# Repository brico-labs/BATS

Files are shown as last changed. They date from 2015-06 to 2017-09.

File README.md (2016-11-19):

NOTA IMPORTANTE  
Lee a sección [META](#meta) para clonar este proxecto.

Qué imos facer? Qué se describe en este documento?
==================================================

Imos deseñar un shield para Arduino usando [KiCad](http://www.kicad-pcb.org/)

Daremos unha visión xeral da funcionalidade da suite KiCad pero non vamos a redactar un tutorial detallado nin de deseño de circuitos nin do mesmo KiCad. Daremos as pistas xustiñas para empezar a traballar con KiCad, se queredes un tutorial detallado, en youtube tedes un super recomendable, elaborado por [TutoElectro](https://www.youtube.com/playlist?list=PL1Hs_F1k2mdRVYDtdWd7tQKDZTfxop7np)

Tamén comentaremos a nivel xeral os pasos para desenvolver este proxecto.

Qué é KiCad?
============

KiCad é unha suite de deseño electrónico automatizado [1]. KiCad permite o deseño tanto de esquemas de circuitos como das placas de circuito impreso a nivel profesional. A suite está dispoñible para Windows, Linux e Apple OS X. É un programa gratuito e **libre** distribuido baixo licencia **GNU GPL v2**.

Mellor ainda, a suite KiCad é a elexida polo CERN para o desenvolvemento e deseño de electrónica. É de esperar que con este respaldo a suite mellore ainda mais.

Requisitos do shield
====================

Queremos facer un shield que poida servir para iniciarse no mundo da programación con Arduino, especialmente centrado no ensino (tecnoloxía 3º - 4º ESO). Neste eido, traballar sobre breadboard pode ser complexo, moitas veces o material é compartido e isto implica que, cada clase, hai que montar e desmontar o circuito que logo se programará. Isto leva o seu tempo e ocasiona erros de montaxe que son difíciles de detectar, polo que o uso dun shield parece que pode ser unha solución.

Mália isto, empregando un shield xa ensamblada se perde a oportunidade de profundizar os coñecementos de electrónica e circuitos que se adquiren ao facer un mesmo a montaxe, así que un shield na que o alumno/a teña que colocar e soldar el mesmo os compoñentes, segundo avanza na súa aprendizaxe, parécenos a solución de compromiso idónea.

Queremos que o shield sexa escalable, que sirva para traballar cuns poucos compoñentes se non se quere profundizar demasiado, pero que permita tamén chegar a nivéis máis avanzados e con máis compoñentes sen cambiar de shield.

Estes son os compoñentes que se pensan incluír:

-   3-4 x Botóns
-   1 x RGB
-   1 x LDR
-   1 x Pines servo
-   1 x sensor temp (dudoso)
-   2 x potenciómetros
-   1 x LED vermello
-   1 x LED amarelo
-   1 x LED verde
-   1 x Zoador
-   1 x Botón de reset

Instalación de KiCad (en Ubuntu)
================================

Para instalar o KiCad en Ubuntu basta con facer o típico ciclo de instalación:

``` {bash}
sudo apt-get install kicad
```

Se queremos estar á última temos o ppa de Monsieur Reynaud dispoñible:

``` {bash}
sudo apt-add-repository ppa:js-reynaud/ppa-KiCad
sudo apt-get update
sudo apt-get install kicad
```

Nos escollimos esta opción.

Se non usades un linux baseado en Debian, teredes que consultar na rede como facer a instalación para o voso sistema operativo. De todolos xeitos a instalación é moi doada, donde podemos atopar algún problemiña é na instalación das bibliotecas de compoñentes que vos contaremos cos mais detalle mais adiante.

Configuración de directorios para este proxecto
===============================================

Además de desenvolver o proxecto con KiCad queremos ter o proxecto dispoñible en github.

Agora que temos KiCad instalado imos preparar un directorio de traballo ao que chamamos **bats**.

O directorio **bats** será o "repositorio" ou depósito do noso proxecto para git. Contén os seguintes subdirectorios:

doc  
Contén a documentación do proxecto (o que estás a leer agora mesmo) redactada en [Pandoc](http://pandoc.org/)

kicad  
Contén o proxecto KiCad

Unha vez que temos preparado o directorio do proxecto activamos git para iniciar o control de versións.

------------------------------------------------------------------------

Describir a configuración de git??

------------------------------------------------------------------------

Biblioteca de compoñentes incluindo un shield para Arduino
==========================================================

As bibliotecas de KiCad están organizadas en duas partes:

-   Un ficheiro que contén os símbolos dos compoñentes para usarse no editor de esquemas electrónicos **Eescheme**

-   As pegadas dos compoñentes electrónicos, é dicir, a forma que ten que ter a pista da placa de circuito impreso (*PCB*) para poder soldar o compoñente.

O KiCad trae por defecto varios templates que permiten o desenrolo de proxectos baseados en diferentes modelos de Arduino.

Nos optamos por outro camiño, instalamos unha nova biblioteca de compoñentes e fixemos o proxecto usando esta biblioteca.

Unha biblioteca moi completa é a de Freetronics que podemos atopar tamén en github en:

<https://github.com/freetronics/freetronics_KiCad_library.git>

As bibliotecas de KiCad poden estar almacenadas en diferentes directorios do noso ordenador. Poderíamos engadir as bibliotecas que usemos en algún subdirectorio de */usr/share/kicad* ou de */usr/local/share*. Esta podería ser unha boa estratexia nun servidor compartido por varios usuarios. Tamén poderíamos descarregar todas as bibliotecas a un directorio común do noso *home*. Pero como estamos facendo un control de versións do noso proxecto con git a propia páxina da biblioteca suxírenos o xeito mais adoitado de facer a instalación: coma un submódulo git do noso proxecto.

A vantaxe de engadir a biblioteca de compoñentes de Freetronics coma un submódulo Git é que o noso proxecto queda "aillado" do proxecto engadido como submódulo. Podemos avanzar no noso proxecto e salvar os cambios feitos con Git, sen afectar aos submódulos, e viceversa.

Por exemplo, unha vez que teñamos o noso directorio de traballo configurado con git, e a libreria de Freetronics engadida como submodulo, poderíamos empezar o desenrolo da nosa placa BATS e ir gardando os nosos avances. Estas operacións non afectarán a librería Freetronics, que de feito ainda que esta descarregada no noso directorio de traballo, non está gardada no git do noso proxecto, soamente está enlazada.

Se no futuro nos interesa actualizarnos a unha versión mais avanzada da librería Freetronics, podemos facer un commit do noso proxecto nunha situación controlada, e despois actualizar o submodulo correspondiente a librería.

Engadir a biblioteca como un submódulo de git
---------------------------------------------

Dende o directorio principal de noso proxecto descarregamos a biblioteca de Freetronics coma un submodulo do noso proxecto:

``` {bash}
cd kicad 
git submodule add https://github.com/freetronics/freetronics_kicad_library.git kicad/ftlibrary
```

Despois de engadir a biblioteca como un submódulo se consultamos o estado git do noso proxecto aparecerán dous novos ficheiros:

``` {bash}
$ git status
On branch master
Your branch is up-to-date with 'origin/master'.
Changes to be committed:
  (use "git reset HEAD <file>..." to unstage)

    new file:   .gitmodules
    new file:   kicad/ftlibrary
```

Git engadíu automáticamente os dous novos ficheiros, o directorio que contén a nosa biblioteca eo ficheiro **.gitmodule** que levará o control de todolos submódulos que usemos.

En realidade os ficheiros que compoñen a biblioteca non pertencen ao noso depósito de software, git só leva conta da versión da biblioteca de Freetronics que estamos a usar.

Se queres saber mais de esta potente funcionalidade de git podes leer: <http://www.git-scm.com/book/en/v2/Git-Tools-Submodules>

Configurar *Eescheme* para usar a nova biblioteca
-------------------------------------------------

No menú Preferences -&gt; Component Library sinalamos na fiestra inferior o directorio do noso proxecto. Na fiestra superior engadimos o ficheiro da biblioteca.

No github da biblioteca nos aconsellan poñer a biblioteca de primeira na nosa lista por que definen todo tipo de compoñentes. Nos de momento seguimos o consello de Freetronics, e a puxemos de primeira.

Configurar acceso aos datos de pegadas (*footprints*) en pcbnew
---------------------------------------------------------------

Configuramos un ficheiro para o noso proxecto declarando os *footprint* extra que imos a utilizar.

``` {cpp}
(fp_lib_table
  (lib
   (name FT)
   (type KiCad)
   (uri ${KIPRJMOD}/ftlibrary/freetronics_footprints.pretty)
   (options "")
   (descr "Freetronics Kicad Library")
   )
)
```

Engadimos o novo ficheiro ao noso repositorio

``` {bash}
git add fp-lib-table
```

Abrimos *Pcbnew* e no menú *Preferences-&gt;Footprint Libraries Manager* comprobamos que na pestaña *Project Specific Libraries* figura o noso ficheiro.

Tutorial
========

Checklist: Pasos a seguir para rematar o proxecto
-------------------------------------------------

-   Abrir o proxecto (e mellor tér un directorio dedicado ao proxecto creado en adianto)
-   Crear o esquema do circuito (usando Eescheme)
-   Chequeo de erros (opción *Perform Electrical Rules Check*)
-   Asignar as pegadas (*footprints*) aos compoñentes (opción *run CvPcb* dende o *Eescheme*). As pegadas quedan asignadas a cada compoñente no esquema.
-   Xerar o ficheiro NET (opción *Generate netlist*)
-   Abrir o PcbNew e cargar o ficheiro NET xenerado dende o Eescheme
-   Distribuir os compoñentes do noso proxecto intentado simplificar a topoloxía das pistas o que poidamos.

A pantalla xeral
----------------

------------------------------------------------------------------------

Pantalla xeral de KiCad opcións, citar a lista de hotkeys

------------------------------------------------------------------------

Abrindo un proxecto
-------------------

### Checklist

-   Usar un directorio adicado ao proxecto
-   Engadir a información do proxecto ao esquema.

Abrimos un novo proxecto: File::New Project (Ctrl+N) **bats**

### 

Crear e Editar o esquema do circuito
------------------------------------

O primeiro que imos facer é o esquema do circuito. Para isto temos que usar a ferramenta *Eeschema* que podemos atopar en tres lugares diferentes [2] na barra de iconos de ferramentas, no menú de KiCad no título da fiestra, ou có atallo **Ctrl+E**.

Abrimos eescheme e creamos un novo ficheiro de esquema.

ERC: comprobación dos erros no circuito
---------------------------------------

### Tips

-   Falar dos flags
    -   Power flags
    -   Not used flag
-   Falar dos ficheiros de pegadas
-   Falar da asignación automática de pegadas

As bibliotecas en KiCAD
=======================

Esta é sen dúbida a parte de KiCAD mais criticada. Hai varias razóns para isto:

-   As bibliotecas de KiCAD manteñen separados os símbolos dos compoñentes para usar no esquema do circuito das pegadas (*footprints*) dos mesmos que son os que se usan no deseño da placa.
-   Os símbolos dos compoñentes están almacenados en ficheiros con extensión *.lib* de ahí que con frecuencia se lles chame *library* (traducido librerias) na xerga de KiCAD
-   Por contra as pegadas dos compoñentes almacénanse en ficheiros con extensión *.mod* ou as mais modernas *.kicad\_mod* de ahí que a miudo se lles chame *modules* (traducido módulos) na xerga de KiCAD
-   Os menús e diálogos para engadir ficheiros *.lib* e os ficheiros *.mod* son completamente diferentes
-   KiCAD soporta multiples localizacións para as bibliotecas, mesmo localizacións en github.

Dende o noso punto de vista o mais sinxelo e ter un só directorio donde almacenemos as bibliotecas de terceiros que queremos usar con KiCAD. Nos usamos **~/resources/kicad** de feito temos:

~/resources/kicad/my\_kicad\_lib  
Para os compoñentes de diseño propio

~/resources/kicad/my\_kicad.pretty  
para os footprints de diseño propio

~/resources/kicad/kicad\_3rd  
para librerias de terceiros

Un exemplo: Engadir novas bibliotecas Arduino
---------------------------------------------

Imos ver como engadir unha nova biblioteca de compoñentes de xeito global (quedará dispoñible para todos os proxectos) ou só para un proxecto concreto.

As bibliotecas que imos usar pódense atopar en esta [páxina](http://meta-blog.eklablog.com/kicad-librairie-arduino-pretty-p930786).

Na páxina hai dous ficheiros dispoñibles para descarga. O que contén as plantillas (*templates*) non o queremos, xa está incluido no github de KiCAD.

Descarregamos o outro e descomprimimos no directorio donde imos ter as bibliotecas de KiCAD, no noso caso: **~/resources/kicad/kicad\_3rd**

Enlaces útiles
==============

-   [Conceptos de circuitos impresos](http://www.pcb.electrosoft.cl/04-articulos-circuitos-impresos-desarrollo-sistemas/01-conceptos-circuitos-impresos/conceptos-circuitos-impresos-pcb.html)
-   [Instalación das bibliotecas](http://www.arunet.co.uk/tkboyd/ele2pcbka.htm)
-   [Mais bibliotecas para KiCad](http://www.kicadlib.org/)

Dende o seguinte enlace podese descarregar unha biblioteca de compoñentes moi currada, ainda que algo anticuada:

<git://smisioto.eu/KiCad_libs.git>

META
====

Este repositorio usa submódulos de git para a xestión das bibliotecas de compoñentes. Para clonar o repositorio tes que clonar o repositorio e despois actualizar os submódulos executando:

``` {bash}
$ git clone https://github.com/brico-labs/BATS
$ git submodule update --init
```

Este documento está escrito en [Markdown-Pandoc](http://pandoc.org/README.html). Pandoc e un sistema moi sinxelo de documentación que permite xerar multiples formatos de saída.

As fontes do documento están no directorio **doc/src**. Os formatos de saída son este fichero **README.md** en formato Markdown-github e os documentos que podes atopar no directorio **doc/out** incluindo un pdf.

Os documentos xéranse automáticamente a partir do ficheiro fonte sen mais que executar:

``` {bash}
$ cd doc
$ make
```

Outras opcións que soporta o **makefile** serían **reset** para rexerar todos os documentos de saída por defecto, **odt** para xerar un **bats\_gl.odt**.

``` {bash}
$ make reset
$ make odt
```

[1] EDA suite en inglés

[2] Isto de ter varios xeitos de facer unha cousa é habitual en KiCad como iremos vendo

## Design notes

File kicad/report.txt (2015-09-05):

Info: Reading netlist file "/home/salvari/work/repos/bats/kicad/bats_n.net".

Info: Using references to match components and footprints.

Info: Checking netlist component footprint "LED1:/55898313:FT:LED-3MM".

Adding new component "LED1:/55898313" footprint "FT:LED-3MM".

Changing component "LED1:/55898313" pin "A" net name from "" to "Net-(LED1-PadA)".

Changing component "LED1:/55898313" pin "K" net name from "" to "Net-(LED1-PadK)".

Info: Checking netlist component footprint "LED2:/55898212:FT:LED-3MM".

Adding new component "LED2:/55898212" footprint "FT:LED-3MM".

Changing component "LED2:/55898212" pin "A" net name from "" to "Net-(LED2-PadA)".

Changing component "LED2:/55898212" pin "K" net name from "" to "Net-(LED2-PadK)".

Info: Checking netlist component footprint "LED3:/55898085:FT:LED-3MM".

Adding new component "LED3:/55898085" footprint "FT:LED-3MM".

Changing component "LED3:/55898085" pin "A" net name from "" to "Net-(LED3-PadA)".

Changing component "LED3:/55898085" pin "K" net name from "" to "Net-(LED3-PadK)".

Info: Checking netlist component footprint "LED4:/558B07DB:FT:LED-RGB-8MM-COM-K-MINIMAL".

Adding new component "LED4:/558B07DB" footprint "FT:LED-RGB-8MM-COM-K-MINIMAL".

Changing component "LED4:/558B07DB" pin "AB" net name from "" to "Net-(LED4-PadAB)".

Changing component "LED4:/558B07DB" pin "AR" net name from "" to "Net-(LED4-PadAR)".

Changing component "LED4:/558B07DB" pin "K" net name from "" to "GND".

Changing component "LED4:/558B07DB" pin "AG" net name from "" to "Net-(LED4-PadAG)".

Info: Checking netlist component footprint "P1:/558B2883:FT:1X03".

Adding new component "P1:/558B2883" footprint "FT:1X03".

Changing component "P1:/558B2883" pin "1" net name from "" to "Net-(P1-Pad1)".

Changing component "P1:/558B2883" pin "2" net name from "" to "Net-(P1-Pad2)".

Changing component "P1:/558B2883" pin "3" net name from "" to "GND".

Info: Checking netlist component footprint "R6:/558983C9:Resistors_ThroughHole:Resistor_Horizontal_RM10mm".

Adding new component "R6:/558983C9" footprint "Resistors_ThroughHole:Resistor_Horizontal_RM10mm".

Changing component "R6:/558983C9" pin "1" net name from "" to "Net-(P1-Pad1)".

Changing component "R6:/558983C9" pin "2" net name from "" to "Net-(R6-Pad2)".

Info: Checking netlist component footprint "R7:/55898454:Resistors_ThroughHole:Resistor_Horizontal_RM10mm".

Adding new component "R7:/55898454" footprint "Resistors_ThroughHole:Resistor_Horizontal_RM10mm".

Changing component "R7:/55898454" pin "1" net name from "" to "Net-(R6-Pad2)".

Changing component "R7:/55898454" pin "2" net name from "" to "GND".

Info: Checking netlist component footprint "R9:/558B13E2:Resistors_ThroughHole:Resistor_Horizontal_RM10mm".

Adding new component "R9:/558B13E2" footprint "Resistors_ThroughHole:Resistor_Horizontal_RM10mm".

Changing component "R9:/558B13E2" pin "1" net name from "" to "Net-(LED4-PadAR)".

Changing component "R9:/558B13E2" pin "2" net name from "" to "Net-(R9-Pad2)".

Info: Checking netlist component footprint "R10:/558B144D:Resistors_ThroughHole:Resistor_Horizontal_RM10mm".

Adding new component "R10:/558B144D" footprint "Resistors_ThroughHole:Resistor_Horizontal_RM10mm".

Changing component "R10:/558B144D" pin "1" net name from "" to "Net-(LED4-PadAG)".

Changing component "R10:/558B144D" pin "2" net name from "" to "Net-(R10-Pad2)".

Info: Checking netlist component footprint "R11:/558B14E5:Resistors_ThroughHole:Resistor_Horizontal_RM10mm".

Adding new component "R11:/558B14E5" footprint "Resistors_ThroughHole:Resistor_Horizontal_RM10mm".

Changing component "R11:/558B14E5" pin "1" net name from "" to "Net-(LED4-PadAB)".

Changing component "R11:/558B14E5" pin "2" net name from "" to "Net-(R11-Pad2)".

Info: Checking netlist component footprint "R12:/558AE59A:Resistors_ThroughHole:Resistor_Horizontal_RM10mm".

Adding new component "R12:/558AE59A" footprint "Resistors_ThroughHole:Resistor_Horizontal_RM10mm".

Changing component "R12:/558AE59A" pin "1" net name from "" to "Net-(R12-Pad1)".

Changing component "R12:/558AE59A" pin "2" net name from "" to "GND".

Info: Checking netlist component footprint "R13:/558AEB17:Resistors_ThroughHole:Resistor_Horizontal_RM10mm".

Adding new component "R13:/558AEB17" footprint "Resistors_ThroughHole:Resistor_Horizontal_RM10mm".

Changing component "R13:/558AEB17" pin "1" net name from "" to "Net-(R13-Pad1)".

Changing component "R13:/558AEB17" pin "2" net name from "" to "GND".

Info: Checking netlist component footprint "R14:/55898319:Resistors_ThroughHole:Resistor_Horizontal_RM10mm".

Adding new component "R14:/55898319" footprint "Resistors_ThroughHole:Resistor_Horizontal_RM10mm".

Changing component "R14:/55898319" pin "1" net name from "" to "Net-(LED1-PadK)".

Changing component "R14:/55898319" pin "2" net name from "" to "GND".

Info: Checking netlist component footprint "R15:/55898218:Resistors_ThroughHole:Resistor_Horizontal_RM10mm".

Adding new component "R15:/55898218" footprint "Resistors_ThroughHole:Resistor_Horizontal_RM10mm".

Changing component "R15:/55898218" pin "1" net name from "" to "Net-(LED2-PadK)".

Changing component "R15:/55898218" pin "2" net name from "" to "GND".

Info: Checking netlist component footprint "R16:/55898121:Resistors_ThroughHole:Resistor_Horizontal_RM10mm".

Adding new component "R16:/55898121" footprint "Resistors_ThroughHole:Resistor_Horizontal_RM10mm".

Changing component "R16:/55898121" pin "1" net name from "" to "Net-(LED3-PadK)".

Changing component "R16:/55898121" pin "2" net name from "" to "GND".

Info: Checking netlist component footprint "R17:/558AEBB6:Resistors_ThroughHole:Resistor_Horizontal_RM10mm".

Adding new component "R17:/558AEBB6" footprint "Resistors_ThroughHole:Resistor_Horizontal_RM10mm".

Changing component "R17:/558AEBB6" pin "1" net name from "" to "Net-(R17-Pad1)".

Changing component "R17:/558AEBB6" pin "2" net name from "" to "GND".

Info: Checking netlist component footprint "R18:/558AEBC3:Resistors_ThroughHole:Resistor_Horizontal_RM10mm".

Adding new component "R18:/558AEBC3" footprint "Resistors_ThroughHole:Resistor_Horizontal_RM10mm".

Changing component "R18:/558AEBC3" pin "1" net name from "" to "Net-(R18-Pad1)".

Changing component "R18:/558AEBC3" pin "2" net name from "" to "GND".

Info: Checking netlist component footprint "SHIELD1:/55897B99:FT:ARDUINO_SHIELD".

Adding new component "SHIELD1:/55897B99" footprint "FT:ARDUINO_SHIELD".

Changing component "SHIELD1:/55897B99" pin "AD5" net name from "" to "Net-(SHIELD1-PadAD5)".

Changing component "SHIELD1:/55897B99" pin "AD4" net name from "" to "Net-(SHIELD1-PadAD4)".

Changing component "SHIELD1:/55897B99" pin "AD3" net name from "" to "Net-(SHIELD1-PadAD3)".

Changing component "SHIELD1:/55897B99" pin "AD0" net name from "" to "Net-(R6-Pad2)".

Changing component "SHIELD1:/55897B99" pin "AD1" net name from "" to "Net-(SHIELD1-PadAD1)".

Changing component "SHIELD1:/55897B99" pin "AD2" net name from "" to "Net-(SHIELD1-PadAD2)".

Changing component "SHIELD1:/55897B99" pin "V_IN" net name from "" to "Net-(SHIELD1-PadV_IN)".

Changing component "SHIELD1:/55897B99" pin "GND2" net name from "" to "GND".

Changing component "SHIELD1:/55897B99" pin "GND1" net name from "" to "GND".

Changing component "SHIELD1:/55897B99" pin "3V3" net name from "" to "Net-(SHIELD1-Pad3V3)".

Changing component "SHIELD1:/55897B99" pin "RST" net name from "" to "Net-(SHIELD1-PadRST)".

Changing component "SHIELD1:/55897B99" pin "0" net name from "" to "Net-(R18-Pad1)".

Changing component "SHIELD1:/55897B99" pin "1" net name from "" to "Net-(R17-Pad1)".

Changing component "SHIELD1:/55897B99" pin "2" net name from "" to "Net-(R13-Pad1)".

Changing component "SHIELD1:/55897B99" pin "3" net name from "" to "Net-(P1-Pad2)".

Changing component "SHIELD1:/55897B99" pin "4" net name from "" to "Net-(R12-Pad1)".

Changing component "SHIELD1:/55897B99" pin "5" net name from "" to "Net-(R11-Pad2)".

Changing component "SHIELD1:/55897B99" pin "6" net name from "" to "Net-(R10-Pad2)".

Changing component "SHIELD1:/55897B99" pin "7" net name from "" to "Net-(SHIELD1-Pad7)".

Changing component "SHIELD1:/55897B99" pin "8" net name from "" to "Net-(SHIELD1-Pad8)".

Changing component "SHIELD1:/55897B99" pin "9" net name from "" to "Net-(R9-Pad2)".

Changing component "SHIELD1:/55897B99" pin "10" net name from "" to "Net-(SHIELD1-Pad10)".

Changing component "SHIELD1:/55897B99" pin "11" net name from "" to "Net-(LED3-PadA)".

Changing component "SHIELD1:/55897B99" pin "12" net name from "" to "Net-(LED2-PadA)".

Changing component "SHIELD1:/55897B99" pin "13" net name from "" to "Net-(LED1-PadA)".

Changing component "SHIELD1:/55897B99" pin "GND3" net name from "" to "GND".

Changing component "SHIELD1:/55897B99" pin "AREF" net name from "" to "Net-(SHIELD1-PadAREF)".

Changing component "SHIELD1:/55897B99" pin "5V" net name from "" to "Net-(P1-Pad1)".

Changing component "SHIELD1:/55897B99" pin "SDA" net name from "" to "Net-(SHIELD1-PadSDA)".

Changing component "SHIELD1:/55897B99" pin "SCL" net name from "" to "Net-(SHIELD1-PadSCL)".

Changing component "SHIELD1:/55897B99" pin "IO_R" net name from "" to "Net-(SHIELD1-PadIO_R)".

Changing component "SHIELD1:/55897B99" pin "NC" net name from "" to "Net-(SHIELD1-PadNC)".

Changing component "SHIELD1:/55897B99" pin "SP1" net name from "" to "Net-(SHIELD1-PadSP1)".

Changing component "SHIELD1:/55897B99" pin "SP2" net name from "" to "Net-(SHIELD1-PadSP2)".

Changing component "SHIELD1:/55897B99" pin "SP3" net name from "" to "Net-(SHIELD1-PadSP3)".

Changing component "SHIELD1:/55897B99" pin "SP4" net name from "" to "Net-(SHIELD1-PadSP4)".

Changing component "SHIELD1:/55897B99" pin "SP5" net name from "" to "Net-(SHIELD1-PadSP5)".

Changing component "SHIELD1:/55897B99" pin "SP6" net name from "" to "Net-(SHIELD1-PadSP6)".

Info: Checking netlist component footprint "SW5:/558B73E7:FT:SW_PUSHBUTTON_PTH".

Adding new component "SW5:/558B73E7" footprint "FT:SW_PUSHBUTTON_PTH".

Changing component "SW5:/558B73E7" pin "1" net name from "" to "GND".

Changing component "SW5:/558B73E7" pin "1" net name from "" to "GND".

Changing component "SW5:/558B73E7" pin "2" net name from "" to "Net-(SHIELD1-PadRST)".

Changing component "SW5:/558B73E7" pin "2" net name from "" to "Net-(SHIELD1-PadRST)".

Info: Checking netlist component footprint "SW6:/5589867E:FT:SW_PUSHBUTTON_PTH".

Adding new component "SW6:/5589867E" footprint "FT:SW_PUSHBUTTON_PTH".

Changing component "SW6:/5589867E" pin "1" net name from "" to "Net-(P1-Pad1)".

Changing component "SW6:/5589867E" pin "1" net name from "" to "Net-(P1-Pad1)".

Changing component "SW6:/5589867E" pin "2" net name from "" to "Net-(R12-Pad1)".

Changing component "SW6:/5589867E" pin "2" net name from "" to "Net-(R12-Pad1)".

Info: Checking netlist component footprint "SW7:/558AEB11:FT:SW_PUSHBUTTON_PTH".

Adding new component "SW7:/558AEB11" footprint "FT:SW_PUSHBUTTON_PTH".

Changing component "SW7:/558AEB11" pin "1" net name from "" to "Net-(P1-Pad1)".

Changing component "SW7:/558AEB11" pin "1" net name from "" to "Net-(P1-Pad1)".

Changing component "SW7:/558AEB11" pin "2" net name from "" to "Net-(R13-Pad1)".

Changing component "SW7:/558AEB11" pin "2" net name from "" to "Net-(R13-Pad1)".

Info: Checking netlist component footprint "SW8:/558AEBB0:FT:SW_PUSHBUTTON_PTH".

Adding new component "SW8:/558AEBB0" footprint "FT:SW_PUSHBUTTON_PTH".

Changing component "SW8:/558AEBB0" pin "1" net name from "" to "Net-(P1-Pad1)".

Changing component "SW8:/558AEBB0" pin "1" net name from "" to "Net-(P1-Pad1)".

Changing component "SW8:/558AEBB0" pin "2" net name from "" to "Net-(R17-Pad1)".

Changing component "SW8:/558AEBB0" pin "2" net name from "" to "Net-(R17-Pad1)".

Info: Checking netlist component footprint "SW9:/558AEBBD:FT:SW_PUSHBUTTON_PTH".

Adding new component "SW9:/558AEBBD" footprint "FT:SW_PUSHBUTTON_PTH".

Changing component "SW9:/558AEBBD" pin "1" net name from "" to "Net-(P1-Pad1)".

Changing component "SW9:/558AEBBD" pin "1" net name from "" to "Net-(P1-Pad1)".

Changing component "SW9:/558AEBBD" pin "2" net name from "" to "Net-(R18-Pad1)".

Changing component "SW9:/558AEBBD" pin "2" net name from "" to "Net-(R18-Pad1)".

Info: Checking netlist component footprint "U1:/5589860F:Buzzers_Beepers:MagneticBuzzer_Kingstate_KCG0601".

Adding new component "U1:/5589860F" footprint "Buzzers_Beepers:MagneticBuzzer_Kingstate_KCG0601".

Changing component "U1:/5589860F" pin "1" net name from "" to "GND".

Changing component "U1:/5589860F" pin "2" net name from "" to "Net-(SHIELD1-Pad10)".

Info: Checking netlist component footprint "VR1:/55EA1F32:FT:POT_RV09_VERT".

Adding new component "VR1:/55EA1F32" footprint "FT:POT_RV09_VERT".

Changing component "VR1:/55EA1F32" pin "W" net name from "" to "Net-(SHIELD1-PadAD1)".

Changing component "VR1:/55EA1F32" pin "1" net name from "" to "Net-(P1-Pad1)".

Changing component "VR1:/55EA1F32" pin "2" net name from "" to "GND".

Info: Checking netlist component footprint "VR2:/55EA2018:FT:POT_RV09_VERT".

Adding new component "VR2:/55EA2018" footprint "FT:POT_RV09_VERT".

Changing component "VR2:/55EA2018" pin "W" net name from "" to "Net-(SHIELD1-PadAD2)".

Changing component "VR2:/55EA2018" pin "1" net name from "" to "Net-(P1-Pad1)".

Changing component "VR2:/55EA2018" pin "2" net name from "" to "GND".

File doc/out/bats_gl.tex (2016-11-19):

\documentclass[12pt,galician,]{article}
\usepackage{lmodern}
\usepackage{amssymb,amsmath}
\usepackage{ifxetex,ifluatex}
\usepackage{fixltx2e} % provides \textsubscript
\ifnum 0\ifxetex 1\fi\ifluatex 1\fi=0 % if pdftex
  \usepackage[T1]{fontenc}
  \usepackage[utf8]{inputenc}
\else % if luatex or xelatex
  \ifxetex
    \usepackage{mathspec}
  \else
    \usepackage{fontspec}
  \fi
  \defaultfontfeatures{Ligatures=TeX,Scale=MatchLowercase}
    \setmainfont[]{Source Sans Pro}
    \setmonofont[Mapping=tex-ansi]{Source Code Pro}
\fi
% use upquote if available, for straight quotes in verbatim environments
\IfFileExists{upquote.sty}{\usepackage{upquote}}{}
% use microtype if available
\IfFileExists{microtype.sty}{%
\usepackage{microtype}
\UseMicrotypeSet[protrusion]{basicmath} % disable protrusion for tt fonts
}{}
\usepackage[a4paper]{geometry}
\usepackage[unicode=true]{hyperref}
\hypersetup{
            pdftitle={BATS: BricoLabs Arduino Training Shield (con kicad)},
            pdfauthor={BricoLabs},
            pdfborder={0 0 0},
            breaklinks=true}
\urlstyle{same}  % don't use monospace font for urls
\ifnum 0\ifxetex 1\fi\ifluatex 1\fi=0 % if pdftex
  \usepackage[shorthands=off,main=galician]{babel}
\else
  \usepackage{polyglossia}
  \setmainlanguage[]{galician}
\fi
\IfFileExists{parskip.sty}{%
\usepackage{parskip}
}{% else
\setlength{\parindent}{0pt}
\setlength{\parskip}{6pt plus 2pt minus 1pt}
}
\setlength{\emergencystretch}{3em}  % prevent overfull lines
\providecommand{\tightlist}{%
  \setlength{\itemsep}{0pt}\setlength{\parskip}{0pt}}
\setcounter{secnumdepth}{5}
% Redefines (sub)paragraphs to behave more like sections
\ifx\paragraph\undefined\else
\let\oldparagraph\paragraph
\renewcommand{\paragraph}[1]{\oldparagraph{#1}\mbox{}}
\fi
\ifx\subparagraph\undefined\else
\let\oldsubparagraph\subparagraph
\renewcommand{\subparagraph}[1]{\oldsubparagraph{#1}\mbox{}}
\fi

\title{BATS: BricoLabs Arduino Training Shield (con kicad)}
\author{BricoLabs}
\date{20 de xunio de 2015}

\begin{document}
\maketitle

\begin{description}
\item[NOTA IMPORTANTE]
Lee a sección \protect\hyperlink{meta}{META} para clonar este proxecto.
\end{description}

\section{Qué imos facer? Qué se describe en este
documento?}\label{quuxe9-imos-facer-quuxe9-se-describe-en-este-documento}

Imos deseñar un shield para Arduino usando
\href{http://www.kicad-pcb.org/}{KiCad}

Daremos unha visión xeral da funcionalidade da suite KiCad pero non
vamos a redactar un tutorial detallado nin de deseño de circuitos nin do
mesmo KiCad. Daremos as pistas xustiñas para empezar a traballar con
KiCad, se queredes un tutorial detallado, en youtube tedes un super
recomendable, elaborado por
\href{https://www.youtube.com/playlist?list=PL1Hs_F1k2mdRVYDtdWd7tQKDZTfxop7np}{TutoElectro}

Tamén comentaremos a nivel xeral os pasos para desenvolver este
proxecto.

\section{Qué é KiCad?}\label{quuxe9-uxe9-kicad}

KiCad é unha suite de deseño electrónico automatizado \footnote{EDA
  suite en inglés}. KiCad permite o deseño tanto de esquemas de
circuitos como das placas de circuito impreso a nivel profesional. A
suite está dispoñible para Windows, Linux e Apple OS X. É un programa
gratuito e \textbf{libre} distribuido baixo licencia \textbf{GNU GPL
v2}.

Mellor ainda, a suite KiCad é a elexida polo CERN para o desenvolvemento
e deseño de electrónica. É de esperar que con este respaldo a suite
mellore ainda mais.

\section{Requisitos do shield}\label{requisitos-do-shield}

Queremos facer un shield que poida servir para iniciarse no mundo da
programación con Arduino, especialmente centrado no ensino (tecnoloxía
3º - 4º ESO). Neste eido, traballar sobre breadboard pode ser complexo,
moitas veces o material é compartido e isto implica que, cada clase, hai
que montar e desmontar o circuito que logo se programará. Isto leva o
seu tempo e ocasiona erros de montaxe que son difíciles de detectar,
polo que o uso dun shield parece que pode ser unha solución.

Mália isto, empregando un shield xa ensamblada se perde a oportunidade
de profundizar os coñecementos de electrónica e circuitos que se
adquiren ao facer un mesmo a montaxe, así que un shield na que o
alumno/a teña que colocar e soldar el mesmo os compoñentes, segundo
avanza na súa aprendizaxe, parécenos a solución de compromiso idónea.

Queremos que o shield sexa escalable, que sirva para traballar cuns
poucos compoñentes se non se quere profundizar demasiado, pero que
permita tamén chegar a nivéis máis avanzados e con máis compoñentes sen
cambiar de shield.

Estes son os compoñentes que se pensan incluír:

\begin{itemize}
\tightlist
\item
  3-4 x Botóns
\item
  1 x RGB
\item
  1 x LDR
\item
  1 x Pines servo
\item
  1 x sensor temp (dudoso)
\item
  2 x potenciómetros
\item
  1 x LED vermello
\item
  1 x LED amarelo
\item
  1 x LED verde
\item
  1 x Zoador
\item
  1 x Botón de reset
\end{itemize}

\section{Instalación de KiCad (en
Ubuntu)}\label{instalaciuxf3n-de-kicad-en-ubuntu}

Para instalar o KiCad en Ubuntu basta con facer o típico ciclo de
instalación:

\begin{verbatim}
sudo apt-get install kicad
\end{verbatim}

Se queremos estar á última temos o ppa de Monsieur Reynaud dispoñible:

\begin{verbatim}
sudo apt-add-repository ppa:js-reynaud/ppa-KiCad
sudo apt-get update
sudo apt-get install kicad
\end{verbatim}

Nos escollimos esta opción.

Se non usades un linux baseado en Debian, teredes que consultar na rede
como facer a instalación para o voso sistema operativo. De todolos
xeitos a instalación é moi doada, donde podemos atopar algún problemiña
é na instalación das bibliotecas de compoñentes que vos contaremos cos
mais detalle mais adiante.

\section{Configuración de directorios para este
proxecto}\label{configuraciuxf3n-de-directorios-para-este-proxecto}

Además de desenvolver o proxecto con KiCad queremos ter o proxecto
dispoñible en github.

Agora que temos KiCad instalado imos preparar un directorio de traballo
ao que chamamos \textbf{bats}.

O directorio \textbf{bats} será o ``repositorio'' ou depósito do noso
proxecto para git. Contén os seguintes subdirectorios:

\begin{description}
\tightlist
\item[doc]
Contén a documentación do proxecto (o que estás a leer agora mesmo)
redactada en \href{http://pandoc.org/}{Pandoc}
\item[kicad]
Contén o proxecto KiCad
\end{description}

Unha vez que temos preparado o directorio do proxecto activamos git para
iniciar o control de versións.

\begin{center}\rule{0.5\linewidth}{\linethickness}\end{center}

Describir a configuración de git??

\begin{center}\rule{0.5\linewidth}{\linethickness}\end{center}

\section{Biblioteca de compoñentes incluindo un shield para
Arduino}\label{biblioteca-de-compouxf1entes-incluindo-un-shield-para-arduino}

As bibliotecas de KiCad están organizadas en duas partes:

\begin{itemize}
\item
  Un ficheiro que contén os símbolos dos compoñentes para usarse no
  editor de esquemas electrónicos \textbf{Eescheme}
\item
  As pegadas dos compoñentes electrónicos, é dicir, a forma que ten que
  ter a pista da placa de circuito impreso (\emph{PCB}) para poder
  soldar o compoñente.
\end{itemize}

O KiCad trae por defecto varios templates que permiten o desenrolo de
proxectos baseados en diferentes modelos de Arduino.

Nos optamos por outro camiño, instalamos unha nova biblioteca de
compoñentes e fixemos o proxecto usando esta biblioteca.

Unha biblioteca moi completa é a de Freetronics que podemos atopar tamén
en github en:

\url{https://github.com/freetronics/freetronics_KiCad_library.git}

As bibliotecas de KiCad poden estar almacenadas en diferentes
directorios do noso ordenador. Poderíamos engadir as bibliotecas que
usemos en algún subdirectorio de \emph{/usr/share/kicad} ou de
\emph{/usr/local/share}. Esta podería ser unha boa estratexia nun
servidor compartido por varios usuarios. Tamén poderíamos descarregar
todas as bibliotecas a un directorio común do noso \emph{home}. Pero
como estamos facendo un control de versións do noso proxecto con git a
propia páxina da biblioteca suxírenos o xeito mais adoitado de facer a
instalación: coma un submódulo git do noso proxecto.

A vantaxe de engadir a biblioteca de compoñentes de Freetronics coma un
submódulo Git é que o noso proxecto queda ``aillado'' do proxecto
engadido como submódulo. Podemos avanzar no noso proxecto e salvar os
cambios feitos con Git, sen afectar aos submódulos, e viceversa.

Por exemplo, unha vez que teñamos o noso directorio de traballo
configurado con git, e a libreria de Freetronics engadida como
submodulo, poderíamos empezar o desenrolo da nosa placa BATS e ir
gardando os nosos avances. Estas operacións non afectarán a librería
Freetronics, que de feito ainda que esta descarregada no noso directorio
de traballo, non está gardada no git do noso proxecto, soamente está
enlazada.

Se no futuro nos interesa actualizarnos a unha versión mais avanzada da
librería Freetronics, podemos facer un commit do noso proxecto nunha
situación controlada, e despois actualizar o submodulo correspondiente a
librería.

\subsection{Engadir a biblioteca como un submódulo de
git}\label{engadir-a-biblioteca-como-un-submuxf3dulo-de-git}

Dende o directorio principal de noso proxecto descarregamos a biblioteca
de Freetronics coma un submodulo do noso proxecto:

\begin{verbatim}
cd kicad 
git submodule add https://github.com/freetronics/freetronics_kicad_library.git kicad/ftlibrary
\end{verbatim}

Despois de engadir a biblioteca como un submódulo se consultamos o
estado git do noso proxecto aparecerán dous novos ficheiros:

\begin{verbatim}
$ git status
On branch master
Your branch is up-to-date with 'origin/master'.
Changes to be committed:
  (use "git reset HEAD <file>..." to unstage)

    new file:   .gitmodules
    new file:   kicad/ftlibrary
\end{verbatim}

Git engadíu automáticamente os dous novos ficheiros, o directorio que
contén a nosa biblioteca eo ficheiro \textbf{.gitmodule} que levará o
control de todolos submódulos que usemos.

En realidade os ficheiros que compoñen a biblioteca non pertencen ao
noso depósito de software, git só leva conta da versión da biblioteca de
Freetronics que estamos a usar.

Se queres saber mais de esta potente funcionalidade de git podes leer:
\url{http://www.git-scm.com/book/en/v2/Git-Tools-Submodules}

\subsection{\texorpdfstring{Configurar \emph{Eescheme} para usar a nova
biblioteca}{Configurar Eescheme para usar a nova biblioteca}}\label{configurar-eescheme-para-usar-a-nova-biblioteca}

No menú Preferences -\textgreater{} Component Library sinalamos na
fiestra inferior o directorio do noso proxecto. Na fiestra superior
engadimos o ficheiro da biblioteca.

No github da biblioteca nos aconsellan poñer a biblioteca de primeira na
nosa lista por que definen todo tipo de compoñentes. Nos de momento
seguimos o consello de Freetronics, e a puxemos de primeira.

\subsection{\texorpdfstring{Configurar acceso aos datos de pegadas
(\emph{footprints}) en
pcbnew}{Configurar acceso aos datos de pegadas (footprints) en pcbnew}}\label{configurar-acceso-aos-datos-de-pegadas-footprints-en-pcbnew}

Configuramos un ficheiro para o noso proxecto declarando os
\emph{footprint} extra que imos a utilizar.

\begin{verbatim}
(fp_lib_table
  (lib
   (name FT)
   (type KiCad)
   (uri ${KIPRJMOD}/ftlibrary/freetronics_footprints.pretty)
   (options "")
   (descr "Freetronics Kicad Library")
   )
)
\end{verbatim}

Engadimos o novo ficheiro ao noso repositorio

\begin{verbatim}
git add fp-lib-table
\end{verbatim}

Abrimos \emph{Pcbnew} e no menú
\emph{Preferences-\textgreater{}Footprint Libraries Manager} comprobamos
que na pestaña \emph{Project Specific Libraries} figura o noso ficheiro.

\section{Tutorial}\label{tutorial}

\subsection{Checklist: Pasos a seguir para rematar o
proxecto}\label{checklist-pasos-a-seguir-para-rematar-o-proxecto}

\begin{itemize}
\tightlist
\item
  Abrir o proxecto (e mellor tér un directorio dedicado ao proxecto
  creado en adianto)
\item
  Crear o esquema do circuito (usando Eescheme)
\item
  Chequeo de erros (opción \emph{Perform Electrical Rules Check})
\item
  Asignar as pegadas (\emph{footprints}) aos compoñentes (opción
  \emph{run CvPcb} dende o \emph{Eescheme}). As pegadas quedan asignadas
  a cada compoñente no esquema.
\item
  Xerar o ficheiro NET (opción \emph{Generate netlist})
\item
  Abrir o PcbNew e cargar o ficheiro NET xenerado dende o Eescheme
\item
  Distribuir os compoñentes do noso proxecto intentado simplificar a
  topoloxía das pistas o que poidamos.
\end{itemize}

\subsection{A pantalla xeral}\label{a-pantalla-xeral}

\begin{center}\rule{0.5\linewidth}{\linethickness}\end{center}

Pantalla xeral de KiCad opcións, citar a lista de hotkeys

\begin{center}\rule{0.5\linewidth}{\linethickness}\end{center}

\subsection{Abrindo un proxecto}\label{abrindo-un-proxecto}

\subsubsection{Checklist}\label{checklist}

\begin{itemize}
\tightlist
\item
  Usar un directorio adicado ao proxecto
\item
  Engadir a información do proxecto ao esquema.
\end{itemize}

Abrimos un novo proxecto: File::New Project (Ctrl+N) \textbf{bats}

\subsubsection{}\label{section}

\subsection{Crear e Editar o esquema do
circuito}\label{crear-e-editar-o-esquema-do-circuito}

O primeiro que imos facer é o esquema do circuito. Para isto temos que
usar a ferramenta \emph{Eeschema} que podemos atopar en tres lugares
diferentes \footnote{Isto de ter varios xeitos de facer unha cousa é
  habitual en KiCad como iremos vendo} na barra de iconos de
ferramentas, no menú de KiCad no título da fiestra, ou có atallo
\textbf{Ctrl+E}.

Abrimos eescheme e creamos un novo ficheiro de esquema.

\subsection{ERC: comprobación dos erros no
circuito}\label{erc-comprobaciuxf3n-dos-erros-no-circuito}

\subsubsection{Tips}\label{tips}

\begin{itemize}
\tightlist
\item
  Falar dos flags

  \begin{itemize}
  \tightlist
  \item
    Power flags
  \item
    Not used flag
  \end{itemize}
\item
  Falar dos ficheiros de pegadas
\item
  Falar da asignación automática de pegadas
\end{itemize}

\section{As bibliotecas en KiCAD}\label{as-bibliotecas-en-kicad}

Esta é sen dúbida a parte de KiCAD mais criticada. Hai varias razóns
para isto:

\begin{itemize}
\tightlist
\item
  As bibliotecas de KiCAD manteñen separados os símbolos dos compoñentes
  para usar no esquema do circuito das pegadas (\emph{footprints}) dos
  mesmos que son os que se usan no deseño da placa.
\item
  Os símbolos dos compoñentes están almacenados en ficheiros con
  extensión \emph{.lib} de ahí que con frecuencia se lles chame
  \emph{library} (traducido librerias) na xerga de KiCAD
\item
  Por contra as pegadas dos compoñentes almacénanse en ficheiros con
  extensión \emph{.mod} ou as mais modernas \emph{.kicad\_mod} de ahí
  que a miudo se lles chame \emph{modules} (traducido módulos) na xerga
  de KiCAD
\item
  Os menús e diálogos para engadir ficheiros \emph{.lib} e os ficheiros
  \emph{.mod} son completamente diferentes
\item
  KiCAD soporta multiples localizacións para as bibliotecas, mesmo
  localizacións en github.
\end{itemize}

Dende o noso punto de vista o mais sinxelo e ter un só directorio donde
almacenemos as bibliotecas de terceiros que queremos usar con KiCAD. Nos
usamos \textbf{\textasciitilde{}/resources/kicad} de feito temos:

\begin{description}
\item[\textasciitilde{}/resources/kicad/my\_kicad\_lib]
Para os compoñentes de diseño propio
\item[\textasciitilde{}/resources/kicad/my\_kicad.pretty]
para os footprints de diseño propio
\item[\textasciitilde{}/resources/kicad/kicad\_3rd]
para librerias de terceiros
\end{description}

\subsection{Un exemplo: Engadir novas bibliotecas
Arduino}\label{un-exemplo-engadir-novas-bibliotecas-arduino}

Imos ver como engadir unha nova biblioteca de compoñentes de xeito
global (quedará dispoñible para todos os proxectos) ou só para un
proxecto concreto.

As bibliotecas que imos usar pódense atopar en esta
\href{http://meta-blog.eklablog.com/kicad-librairie-arduino-pretty-p930786}{páxina}.

Na páxina hai dous ficheiros dispoñibles para descarga. O que contén as
plantillas (\emph{templates}) non o queremos, xa está incluido no github
de KiCAD.

Descarregamos o outro e descomprimimos no directorio donde imos ter as
bibliotecas de KiCAD, no noso caso:
\textbf{\textasciitilde{}/resources/kicad/kicad\_3rd}

\section{Enlaces útiles}\label{enlaces-uxfatiles}

\begin{itemize}
\tightlist
\item
  \href{http://www.pcb.electrosoft.cl/04-articulos-circuitos-impresos-desarrollo-sistemas/01-conceptos-circuitos-impresos/conceptos-circuitos-impresos-pcb.html}{Conceptos
  de circuitos impresos}
\item
  \href{http://www.arunet.co.uk/tkboyd/ele2pcbka.htm}{Instalación das
  bibliotecas}
\item
  \href{http://www.kicadlib.org/}{Mais bibliotecas para KiCad}
\end{itemize}

Dende o seguinte enlace podese descarregar unha biblioteca de
compoñentes moi currada, ainda que algo anticuada:

\url{git://smisioto.eu/KiCad_libs.git}

\hypertarget{meta}{\section{META}\label{meta}}

Este repositorio usa submódulos de git para a xestión das bibliotecas de
compoñentes. Para clonar o repositorio tes que clonar o repositorio e
despois actualizar os submódulos executando:

\begin{verbatim}
$ git clone https://github.com/brico-labs/BATS
$ git submodule update --init
\end{verbatim}

Este documento está escrito en
\href{http://pandoc.org/README.html}{Markdown-Pandoc}. Pandoc e un
sistema moi sinxelo de documentación que permite xerar multiples
formatos de saída.

As fontes do documento están no directorio \textbf{doc/src}. Os formatos
de saída son este fichero \textbf{README.md} en formato Markdown-github
e os documentos que podes atopar no directorio \textbf{doc/out}
incluindo un pdf.

Os documentos xéranse automáticamente a partir do ficheiro fonte sen
mais que executar:

\begin{verbatim}
$ cd doc
$ make
\end{verbatim}

Outras opcións que soporta o \textbf{makefile} serían \textbf{reset}
para rexerar todos os documentos de saída por defecto, \textbf{odt} para
xerar un \textbf{bats\_gl.odt}.

\begin{verbatim}
$ make reset
$ make odt
\end{verbatim}

\end{document}

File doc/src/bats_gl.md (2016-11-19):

% BATS: BricoLabs Arduino Training Shield (con kicad)
% BricoLabs
% 20 de xunio de 2015

NOTA IMPORTANTE

  : Lee a sección [META](#meta) para clonar este proxecto.

# Qué imos facer? Qué se describe en este documento?

Imos deseñar un shield para Arduino usando
[KiCad](http://www.kicad-pcb.org/)

Daremos unha visión xeral da funcionalidade da suite KiCad pero non
vamos a redactar un tutorial detallado nin de deseño de circuitos nin
do mesmo KiCad. Daremos as pistas xustiñas para empezar a traballar
con KiCad, se queredes un tutorial detallado, en youtube tedes un
super recomendable, elaborado por
[TutoElectro](https://www.youtube.com/playlist?list=PL1Hs_F1k2mdRVYDtdWd7tQKDZTfxop7np)

Tamén comentaremos a nivel xeral os pasos para desenvolver este
proxecto.

# Qué é KiCad?

KiCad é unha suite de deseño electrónico automatizado
^[EDA suite en inglés]. KiCad permite o deseño tanto de esquemas de
circuitos como das placas de circuito impreso a nivel profesional. A suite
está dispoñible para Windows, Linux e Apple OS X. É un programa
gratuito e __libre__ distribuido baixo licencia __GNU GPL v2__.

Mellor ainda, a suite KiCad é a elexida polo CERN para o
desenvolvemento e deseño de electrónica. É de esperar que con este
respaldo a suite mellore ainda mais.

# Requisitos do shield

Queremos facer un shield que poida servir para iniciarse no mundo da
programación con Arduino, especialmente centrado no ensino (tecnoloxía
3º - 4º ESO). Neste eido, traballar sobre breadboard pode ser
complexo, moitas veces o material é compartido e isto implica que,
cada clase, hai que montar e desmontar o circuito que logo se
programará. Isto leva o seu tempo e ocasiona erros de montaxe que son
difíciles de detectar, polo que o uso dun shield parece que pode ser
unha solución.

Mália isto, empregando un shield xa ensamblada se perde a oportunidade
de profundizar os coñecementos de electrónica e circuitos que se
adquiren ao facer un mesmo a montaxe, así que un shield na que o
alumno/a teña que colocar e soldar el mesmo os compoñentes, segundo
avanza na súa aprendizaxe, parécenos a solución de compromiso idónea.

Queremos que o shield sexa escalable, que sirva para traballar cuns
poucos compoñentes se non se quere profundizar demasiado, pero que
permita tamén chegar a nivéis máis avanzados e con máis compoñentes
sen cambiar de shield.

Estes son os compoñentes que se pensan incluír:

* 3-4 x Botóns
* 1 x RGB
* 1 x LDR
* 1 x Pines servo
* 1 x sensor temp (dudoso)
* 2 x potenciómetros
* 1 x LED vermello
* 1 x LED amarelo
* 1 x LED verde
* 1 x Zoador
* 1 x Botón de reset

# Instalación de KiCad (en Ubuntu)

Para instalar o KiCad en Ubuntu basta con facer o típico ciclo de
instalación:

~~~~{bash}
sudo apt-get install kicad
~~~~

Se queremos estar á última temos o ppa de Monsieur Reynaud dispoñible:

~~~~{bash}
sudo apt-add-repository ppa:js-reynaud/ppa-KiCad
sudo apt-get update
sudo apt-get install kicad
~~~~

Nos escollimos esta opción.

Se non usades un linux baseado en Debian, teredes que consultar na
rede como facer a instalación para o voso sistema operativo. De
todolos xeitos a instalación é moi doada, donde podemos atopar algún
problemiña é na instalación das bibliotecas de compoñentes que vos
contaremos cos mais detalle mais adiante.

# Configuración de directorios para este proxecto

Además de desenvolver o proxecto con KiCad queremos ter o proxecto
dispoñible en github.

Agora que temos KiCad instalado imos preparar un directorio de
traballo ao que chamamos __bats__.

O directorio __bats__ será o "repositorio" ou depósito do
noso proxecto para git. Contén os seguintes subdirectorios:

doc
  : Contén a documentación do proxecto (o que estás a leer agora
mesmo) redactada en [Pandoc](http://pandoc.org/)

kicad
  : Contén o proxecto KiCad

Unha vez que temos preparado o directorio do proxecto activamos git
para iniciar o control de versións.

----

Describir a configuración de git??

----

# Biblioteca de compoñentes incluindo un shield para Arduino

As bibliotecas de KiCad están organizadas en duas partes:

* Un ficheiro que contén os símbolos dos compoñentes para usarse no
  editor de esquemas electrónicos __Eescheme__

* As pegadas dos compoñentes electrónicos, é dicir, a forma que ten que
  ter a pista da placa de circuito impreso (_PCB_) para poder soldar o
  compoñente.

O KiCad trae por defecto varios templates que permiten o desenrolo de
proxectos baseados en diferentes modelos de Arduino.

Nos optamos por outro camiño, instalamos unha nova biblioteca de
compoñentes e fixemos o proxecto usando esta biblioteca.

Unha biblioteca moi completa é a de Freetronics que podemos atopar
tamén en github en:

<https://github.com/freetronics/freetronics_KiCad_library.git>

As bibliotecas de KiCad poden estar almacenadas en diferentes
directorios do noso ordenador. Poderíamos engadir as bibliotecas que
usemos en algún subdirectorio de _/usr/share/kicad_ ou de
_/usr/local/share_. Esta podería ser unha boa estratexia nun servidor
compartido por varios usuarios. Tamén poderíamos descarregar todas as
bibliotecas a un directorio común do noso _home_. Pero como estamos
facendo un control de versións do noso proxecto con git a propia
páxina da biblioteca suxírenos o xeito mais adoitado de facer a
instalación: coma un submódulo git do noso proxecto.

A vantaxe de engadir a biblioteca de compoñentes de Freetronics coma
un submódulo Git é que o noso proxecto queda "aillado" do proxecto
engadido como submódulo. Podemos avanzar no noso proxecto e salvar os
cambios feitos con Git, sen afectar aos submódulos, e viceversa.

Por exemplo, unha vez que teñamos o noso directorio de traballo configurado
con git, e a libreria de Freetronics engadida como submodulo, poderíamos
empezar o desenrolo da nosa placa BATS e ir gardando os nosos
avances. Estas operacións non afectarán a librería Freetronics, que de
feito ainda que esta descarregada no noso directorio de traballo, non
está gardada no git do noso proxecto, soamente está enlazada.

Se no futuro nos interesa actualizarnos a unha versión mais avanzada
da librería Freetronics, podemos facer un commit do noso proxecto
nunha situación controlada, e despois actualizar o submodulo
correspondiente a librería.

## Engadir a biblioteca como un submódulo de git

Dende o directorio principal de noso proxecto descarregamos a
biblioteca de Freetronics coma un submodulo do noso proxecto:

~~~{bash}
cd kicad 
git submodule add https://github.com/freetronics/freetronics_kicad_library.git kicad/ftlibrary
~~~

Despois de engadir a biblioteca como un submódulo se consultamos o
estado git do noso proxecto aparecerán dous novos ficheiros:

~~~~{bash}
$ git status
On branch master
Your branch is up-to-date with 'origin/master'.
Changes to be committed:
  (use "git reset HEAD <file>..." to unstage)

	new file:   .gitmodules
	new file:   kicad/ftlibrary
~~~~

Git engadíu automáticamente os dous novos ficheiros, o directorio que
contén a nosa biblioteca eo ficheiro __.gitmodule__ que levará o
control de todolos submódulos que usemos.

En realidade os ficheiros que compoñen a biblioteca non pertencen ao
noso depósito de software, git só leva conta da versión da biblioteca
de Freetronics que estamos a usar.

Se queres saber mais de esta potente funcionalidade de git podes leer:
<http://www.git-scm.com/book/en/v2/Git-Tools-Submodules>

## Configurar _Eescheme_ para usar a nova biblioteca

No menú Preferences -> Component Library sinalamos na fiestra inferior o
directorio do noso proxecto. Na fiestra superior engadimos o ficheiro da
biblioteca.

No github da biblioteca nos aconsellan poñer a biblioteca de primeira
na nosa lista por que definen todo tipo de compoñentes. Nos de momento
seguimos o consello de Freetronics, e a puxemos de primeira.

## Configurar acceso aos datos de pegadas (_footprints_) en pcbnew

Configuramos un ficheiro para o noso proxecto declarando os
_footprint_ extra que imos a utilizar.

~~~~{cpp}
(fp_lib_table
  (lib
   (name FT)
   (type KiCad)
   (uri ${KIPRJMOD}/ftlibrary/freetronics_footprints.pretty)
   (options "")
   (descr "Freetronics Kicad Library")
   )
)
~~~~

Engadimos o novo ficheiro ao noso repositorio

~~~~{bash}
git add fp-lib-table
~~~~

Abrimos _Pcbnew_ e no menú _Preferences->Footprint Libraries Manager_
comprobamos que na pestaña _Project Specific Libraries_ figura o noso
ficheiro.

# Tutorial

## Checklist: Pasos a seguir para rematar o proxecto

* Abrir o proxecto (e mellor tér un directorio dedicado ao proxecto
  creado en adianto)
* Crear o esquema do circuito (usando Eescheme)
* Chequeo de erros (opción _Perform Electrical Rules Check_)
* Asignar as pegadas (_footprints_) aos compoñentes (opción _run
  CvPcb_ dende o _Eescheme_). As pegadas quedan asignadas a cada
  compoñente no esquema.
* Xerar o ficheiro NET (opción _Generate netlist_)
* Abrir o PcbNew e cargar o ficheiro NET xenerado dende o Eescheme
* Distribuir os compoñentes do noso proxecto intentado simplificar a
  topoloxía das pistas o que poidamos.

## A pantalla xeral

----

Pantalla xeral de KiCad opcións, citar a lista de hotkeys

----

## Abrindo un proxecto

### Checklist

* Usar un directorio adicado ao proxecto
* Engadir a información do proxecto ao esquema.

Abrimos un novo proxecto: File::New Project (Ctrl+N)
__bats__

###

## Crear e Editar o esquema do circuito

O primeiro que imos facer é o esquema do circuito. Para isto temos que
usar a ferramenta _Eeschema_ que podemos atopar en tres lugares
diferentes
^[Isto de ter varios xeitos de facer unha cousa é habitual en KiCad como iremos vendo]
na barra de iconos de ferramentas, no menú de KiCad no título da
fiestra, ou có atallo __Ctrl+E__.

Abrimos eescheme e creamos un novo ficheiro de esquema.

## ERC: comprobación dos erros no circuito

### Tips

* Falar dos flags
    * Power flags
    * Not used flag
* Falar dos ficheiros de pegadas
* Falar da asignación automática de pegadas

# As bibliotecas en KiCAD

Esta é sen dúbida a parte de KiCAD mais criticada. Hai varias razóns para isto:

* As bibliotecas de KiCAD manteñen separados os símbolos dos
  compoñentes para usar no esquema do circuito das pegadas
  (*footprints*) dos mesmos que son os que se usan no deseño da placa.
* Os símbolos dos compoñentes están almacenados en ficheiros con
  extensión *.lib* de ahí que con frecuencia se lles chame *library*
  (traducido librerias) na xerga de KiCAD
* Por contra as pegadas dos compoñentes almacénanse en ficheiros con
  extensión *.mod* ou as mais modernas *.kicad_mod* de ahí que a miudo
  se lles chame *modules* (traducido módulos) na xerga de KiCAD
* Os menús e diálogos para engadir ficheiros *.lib* e os ficheiros
  *.mod* son completamente diferentes
* KiCAD soporta multiples localizacións para as bibliotecas, mesmo
  localizacións en github.

Dende o noso punto de vista o mais sinxelo e ter un só directorio
donde almacenemos as bibliotecas de terceiros que queremos usar con
KiCAD. Nos usamos **~/resources/kicad** de feito temos:

~/resources/kicad/my_kicad_lib

  ~ Para os compoñentes de diseño propio

~/resources/kicad/my_kicad.pretty

  ~ para os footprints de diseño propio

~/resources/kicad/kicad_3rd

  ~ para librerias de terceiros

## Un exemplo: Engadir novas bibliotecas Arduino

Imos ver como engadir unha nova biblioteca de compoñentes de xeito
global (quedará dispoñible para todos os proxectos) ou só para un
proxecto concreto.

As bibliotecas que imos usar pódense atopar en esta
[páxina](http://meta-blog.eklablog.com/kicad-librairie-arduino-pretty-p930786).

Na páxina hai dous ficheiros dispoñibles para descarga. O que contén
as plantillas (*templates*) non o queremos, xa está incluido no github
de KiCAD.

Descarregamos o outro e descomprimimos no directorio donde imos ter as
bibliotecas de KiCAD, no noso caso: **~/resources/kicad/kicad_3rd**

# Enlaces útiles

* [Conceptos de circuitos impresos](http://www.pcb.electrosoft.cl/04-articulos-circuitos-impresos-desarrollo-sistemas/01-conceptos-circuitos-impresos/conceptos-circuitos-impresos-pcb.html)
* [Instalación das bibliotecas](http://www.arunet.co.uk/tkboyd/ele2pcbka.htm)
* [Mais bibliotecas para KiCad](http://www.kicadlib.org/)

Dende o seguinte enlace podese descarregar unha biblioteca de
compoñentes moi currada, ainda que algo anticuada:

<git://smisioto.eu/KiCad_libs.git>

# META

Este repositorio usa submódulos de git para a xestión das bibliotecas
de compoñentes. Para clonar o repositorio tes que clonar o repositorio
e despois actualizar os submódulos executando:

~~~~{bash}
$ git clone https://github.com/brico-labs/BATS
$ git submodule update --init
~~~~

Este documento está escrito en
[Markdown-Pandoc](http://pandoc.org/README.html). Pandoc e un sistema
moi sinxelo de documentación que permite xerar multiples formatos de
saída.

As fontes do documento están no directorio __doc/src__. Os formatos de
saída son este fichero __README.md__ en formato Markdown-github e os
documentos que podes atopar no directorio __doc/out__ incluindo un
pdf.

Os documentos xéranse automáticamente a partir do ficheiro fonte sen
mais que executar:

~~~~{bash}
$ cd doc
$ make
~~~~

Outras opcións que soporta o __makefile__ serían __reset__ para
rexerar todos os documentos de saída por defecto, __odt__ para xerar
un __bats_gl.odt__.

~~~~{bash}
$ make reset
$ make odt
~~~~

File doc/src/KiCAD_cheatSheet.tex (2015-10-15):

%%
%% This is file `tikzposter-template.tex',
%% generated with the docstrip utility.
%%
%% The original source files were:
%%
%% tikzposter.dtx  (with options: `tikzposter-template.tex')
%%
%% This is a generated file.
%%
%% Copyright (C) 2014 by Pascal Richter, Elena Botoeva, Richard Barnard, and Dirk Surmann
%%
%% This file may be distributed and/or modified under the
%% conditions of the LaTeX Project Public License, either
%% version 2.0 of this license or (at your option) any later
%% version. The latest version of this license is in:
%%
%% http://www.latex-project.org/lppl.txt
%%
%% and version 2.0 or later is part of all distributions of
%% LaTeX version 2013/12/01 or later.
%%

\documentclass[20pt]{tikzposter} %Options for format can be included here

\usepackage{bookman}

% Esto es para poder escribir acentos directamente:
\usepackage[utf8]{inputenc}
% Esto es para que el LaTeX sepa que el texto está en español:
\usepackage[spanish]{babel}

\usepackage{graphicx}
\graphicspath{ {img/} }

 % Title, Author, Institute
\title{KiCAD Cheat Sheet}
\author{salvari}
\institute{BricoLabs}
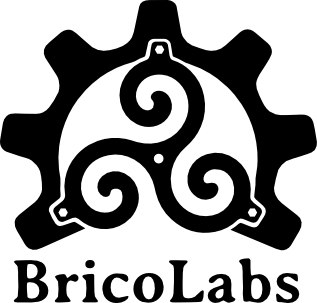
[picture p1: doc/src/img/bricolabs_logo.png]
\titlegraphic{}

 %Choose Layout
\usetheme{Default}

\begin{document}

 % Title block with title, author, logo, etc.
\maketitle
\block{KiCAD}{

  KiCad é unha suite de deseño electrónico automatizado (EDA Suite en
  inglés). KiCad permite o deseño tanto de esquemas de circuitos como
  das placas de circuito impreso a nivel profesional. A suite está
  dispoñible para Windows, Linux e Apple OS X. É un programa gratuito
  e libre distribuido baixo licencia GNU GPL v2.

  Mellor ainda, a suite KiCad é a elexida polo CERN para o
  desenvolvemento e deseño de electrónica. É de esperar que con este
  respaldo a suite mellore ainda mais.
\\
\innerblock{Compoñentes da suite KiCAD}{
  \begin{description}
  \item[Eescheme] O editor dos esquemas eléctricos
  \item[Pcbnew] O editor das placas de circuito impreso (PCB en inglés)
  \item[Schematic Library Editor] O editor dos compoñentes esquemáticos
  \item[PCB footprint editor] O editor de ``pegadas'' dos compoñentes
  \item[GerbView] Un visor de ficheiros Gerb
  \item[Bitmap2Component] Conversor de bitmaps a compoñentes de
    Eescheme ou de Pcbnew
  \item[Pcb calculator] Unha calculadora de circuitos impresos con
    distintas utilidades
  \item[Pl editor] Un editor de plantillas para as follas de circuitos
    impresos ou de circuitos impresos
  \end{description}
}

}
 \begin{columns}

 % FIRST column
\column{0.5}% Width set relative to text width

\block{Eescheme}{
  \begin{tabular}{l|l|c}
    Axuda & Help & ?\\
    Aumentar zoom & Zoom In & F1\\
    Disminuir zoom & Zoom Out & F2\\
    Redibuxar zoom & Zoom Redraw & F3\\
    Centrar zoom & Zoom Center & F4\\
    Encaixar na pantalla & Fit on Screen & Home\\
    Borrar item & Delete Item & Del\\
    Repetir derradeiro item & Repeat Lest Item & Ins\\
    Mover ou arrastrar bloque & Move Block -> Drag Block & Tab\\
    Mover item & Move Item & M\\
    Copiar compoñente ou etiqueta & Copy Component or Label & C\\
    Arrastrar item & Drag Item & G\\
    Engadir compoñente & Add Component & A\\
    Engadir Alimentación & Add Power & P\\
    Xirar item & Rotate Item & R\\
    Invertir compoñente no eixo X & Mirror X Component & X\\
    Invertir compoñente no eixo Y & Mirror Y Component & Y\\
    Orientación por defecto de compoñente & Orient Normal Component & N\\
    Editar item & Edit Item & E\\
    Editar valor & Edit Value & V\\
    Editar referencia & Edit Reference & U\\
    Editar pegada & Edit Footprint & F\\
    Comenzar cableado & Begin Wire & W\\
    Comenzar Bus & Begin Bus & B\\
    Finalizar cableado ou bus & End Line Wire Bus & K\\
    Engadir etiqueta & Add Label & L\\
    Engadir etiqueta xerarquica & Add Hierarchical Label & H\\
    Engadir conexión de cables & Add Junction & J\\
    Engadir marca de no conexión & Add No Connect Flag & Q\\
    Engadir folla & Add Sheet & S\\
    Engadir conexión & Add Wire Entry & Z\\
    Engadir entrada de bus & Add Bus Entry & /\\
  \end{tabular}
}
% \note{Note with default behavior}
% \note[targetoffsetx=12cm, targetoffsety=-1cm, angle=20, rotate=25]
% {Note \\ offset and rotated}

 % First column - second block
\block{Fluxo de traballo}{
  \begin{list}{}{}
  \item 
  \end{list}
}

%  % First column - third block
% \block{Sample Block 4}{T\\E\\S\\T}

 % SECOND column
\column{0.5}
 %Second column with first block's top edge aligned with with previous column's top.

 % Second column - first block
\block{Pcbnew}{
  \begin{tabular}{l|l|c}
    Cambiar unidades & Switch Units & CTRL+U\\
    Resetear coordinadas locales & Reset Local Coordinates & Space\\
    Desfacer & Undo & Ctrl+Z\\
    Volver a facer & Redo & CTRL-Y\\
    Modo seguimento & Track Display Mode & K\\
    Borrar & Delete & Del\\
    Borrar segmento & Delete Track Segment & BkSp\\
    Engadir nova pista & Add New Track X\\
    Engadir via & Add Via & V\\
    Engadir microvia & Add Microvia & CTRL+V\\
    Cambiar posición da pista & Switch Track Posture & /\\
    Arrastrar pista manter pend & Drag Track, Keep Slope &  D\\
    Colocar compoñente & Place Item & P\\
    Copiar item & Copy Item & C\\
    Finalizar pista & End Track & End\\
    Move item & Move Item & M\\
    Invertir item & Flip Item & F\\
    Rotar item & Rotate Item & R\\
    Arrastrar item & Drag Item & G\\
    Buscar compoñente & Get and Move Footprint & T\\
    Bloquear pegada & Lock/Unlock Footprint & L\\
    Salvar tarxeta & Save Board & Ctrl+S\\
    Cargar tarxeta & Load Board & Ctrl+L\\
    Atopar item & Find Item & Ctrl+F\\
    Editar item & Edit Item & End\\
    Ir á capa de cobre & Switch to Cooper Layer & PgDn\\
    Ir á capa interna 1 & Switch to Inner Layer 1 & F5\\
    Ir á capa interna 2 & Switch to Inner Layer 2 & F6\\
    Ir á capa de compoñentes & Switch to Component Layer & PgUp\\
    Ir á siguiente capa & Switch to Next Layer & +\\
    Ir á capa previa & Switch to Previous Layer & -\\
    Engadir módulo & Add Module & O\\
    Camb. á anch. de pista sig. & Switch Track Width to Next & W\\
    Camb. á anch. de pista prev & Switch Track Width to Previous & Ctrl+W\\
    Modo de alto contraste & Switch Highcontrast Mode & H\\
    Invertir bloque (espello) & Invert (mirror) Block & Shift-LeftMouseB\\
  \end{tabular}
}

%  % Second column - second block
% \block[titlewidthscale=0.6, bodywidthscale=0.8]
% {Variable width title}{Block with smaller width.}
% 
%  % Second column - third block
% \block{}{Block with no title}
% 
%  % Second column - A collection of blocks in subcolumn environment.
% \begin{subcolumns}
%     \subcolumn{0.27} \block{1}{First block.} \block{2}{Second block}
%     \subcolumn{0.4} \block{Sub-columns}{Sample subblocks\\Second subcolumn}
%     \subcolumn{0.33} \block{4}{Fourth} \block{}{Final Subcolumn block}
% \end{subcolumns}
% 
 % Bottomblock
% \block{Final Block in column}{
%     Sample block.
% }
\end{columns}
% \block[titleleft, titleoffsetx=2em, titleoffsety=1em, bodyoffsetx=2em,%
%  bodyoffsety=-2cm, roundedcorners=10, linewidth=0mm, titlewidthscale=0.7,%
%  bodywidthscale=0.9, bodyverticalshift=2cm, titleright]
% {Block outside of Columns}{Along with several options enabled}

\end{document}

\endinput
%%
%% End of file `tikzposter-template.tex'.

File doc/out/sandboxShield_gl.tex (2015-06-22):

\section{Qué imos facer? Qué se describe en este
documento?}\label{quuxe9-imos-facer-quuxe9-se-describe-en-este-documento}

Imos deseñar un shield para Arduino. Usando
\href{http://www.kicad-pcb.org/}{KiCad}

Daremos unha visión xeral da funcionalidade da suite KiCad pero non
vamos a redactar un tutorial detallado nin de deseño de circuitos nin do
mesmo KiCad. Daremos as pistas xustiñas para empezar a traballar con
KiCad, se queredes un tutorial detallado, en youtube tedes un super
recomendable, elaborado por
\href{https://www.youtube.com/playlist?list=PL1Hs_F1k2mdRVYDtdWd7tQKDZTfxop7np}{TutoElectro}

Tamén comentaremos de pasada como fumos desenvolvendo iste proxecto.

\section{Qué é KiCad?}\label{quuxe9-uxe9-kicad}

KiCad é unha suite de deseño electrónico automatizado \footnote{EDA
  suite en inglés}. KiCad permite o deseño tanto de esquemas de
circuitos como das placas de circuito impreso a nivel profesional. Hai
versións de KiCad dispoñibles para Windows, Linux, Apple OS X. A suite
está dispoñible para Windows, Linux e Apple OS X. É un programa gratuito
e \textbf{libre} distribuido baixo licencia \textbf{GNU GPL v2}.

Mellor ainda, a suite KiCad é a elexida polo CERN para o desenvolvemento
e deseño de electrónica. É de esperar que con este respaldo a suite
mellore ainda mais.

\section{Requisitos do shield}\label{requisitos-do-shield}

Queremos facer un shield sinxelo para a enseñanza.

\begin{itemize}
\itemsep1pt\parskip0pt\parsep0pt
\item
  1 x LDR
\item
  3-4 x Botóns
\item
  1 x RGB
\item
  1 x LDR
\item
  1 x Pines servo
\item
  1 x sensor temp
\item
  2 x potenciómetros
\item
  1 x LED bermello
\item
  1 x LED amarelo
\item
  1 x LED verde
\item
  1 x Zoador
\item
  1 x Botón de reset
\end{itemize}

\section{Instalación de KiCad (en
Ubuntu)}\label{instalaciuxf3n-de-kicad-en-ubuntu}

Para instalar o KiCad en Ubuntu basta con facer o típico ciclo de
instalación:

\begin{verbatim}
sudo apt-get install kicad
\end{verbatim}

Se queremos estar á última temos o ppa de Monsieur Reynaud dispoñible:

\begin{verbatim}
sudo apt-add-repository ppa:js-reynaud/ppa-KiCad
sudo apt-get update
sudo apt-get install kicad
\end{verbatim}

Nos escollimos esta opción.

Se non usades un linux baseado en Debian, teredes que consultar na rede
como facer a instalación para o voso sistema operativo. De todolos
xeitos a instalación é moi doada, donde podemos atopar algún problemiña
é na instalación das bibliotecas de compoñentes que vos contaremos cos
mais detalle mais adiante.

\section{Configuración de directorios para este
proxecto}\label{configuraciuxf3n-de-directorios-para-este-proxecto}

Además de desenvolver o proxecto con KiCad queremos ter o proxecto
dispoñible en github.

Agora que temos KiCad instalado imos preparar un directorio de traballo
ao que chamamos \textbf{sandboxShield}.

O directorio \textbf{sandboxShield} será o ``repositorio'' ou depósito
do noso proxecto para git. Contén os seguintes subdirectorios:

doc

: Contén a documentación do proxecto (o que estás a leer agora mesmo)
redactada en \href{http://pandoc.org/}{Pandoc}

kicad

: Contén o proxecto KiCad

Unha vez que temos preparado o directorio do proxecto activamos git para
iniciar o control de versións.

\begin{center}\rule{0.5\linewidth}{\linethickness}\end{center}

Describir a configuración de git??

\begin{center}\rule{0.5\linewidth}{\linethickness}\end{center}

\section{Biblioteca de compoñentes incluindo un shield para
Arduino}\label{biblioteca-de-compouxf1entes-incluindo-un-shield-para-arduino}

As bibliotecas de KiCad están organizadas en duas partes:

\begin{itemize}
\item
  Un ficheiro que contén os símbolos dos compoñentes para usarse no
  editor de esquemas electrónicos \textbf{Eescheme}
\item
  As pegadas dos compoñentes electrónicos, é dicir, a forma que ten que
  ter a pista da placa de circuito impreso (\emph{PCB}) para poder
  soldar o compoñente.
\end{itemize}

O KiCad non trae por defecto unha biblioteca de compoñentes que inclúa
shields de Arduino. Pero non hai problema hai bibliotecas que podemos
descarregar da rede.

Unha biblioteca moi completa é a de Freetronics que podemos atopar tamén
en github en:

\url{https://github.com/freetronics/freetronics_KiCad_library.git}

As bibliotecas de KiCad poden estar almacenadas en diferentes
directorios do noso ordenador. Poderíamos engadir as bibliotecas que
usemos en algún subdirectorio de \emph{/usr/share/kicad} ou de
\emph{/usr/local/share}. Esta podería ser unha boa estratexia nun
servidor compartido por varios usuarios. Tamén poderíamos descarregar
todas as bibliotecas a un directorio común do noso \emph{home}. Pero
como estamos facendo un control de versións do noso proxecto con git a
propia páxina da biblioteca suxírenos o xeito mais adoitado de facer a
instalación: coma un submódulo git do noso proxecto.

\begin{center}\rule{0.5\linewidth}{\linethickness}\end{center}

Describir as vantaxes de usar un git submodule

\begin{center}\rule{0.5\linewidth}{\linethickness}\end{center}

\subsection{Engadir a biblioteca como un submódulo de
git}\label{engadir-a-biblioteca-como-un-submuxf3dulo-de-git}

Dende o directorio principal de noso proxecto descarregamos a biblioteca
de Freetronics coma un submodulo do noso proxecto:

\begin{verbatim}
git submodule add https://github.com/freetronics/freetronics_kicad_library.git kicad/ftlibrary
\end{verbatim}

Despois de engadir a biblioteca como un submódulo se consultamos o
estado git do noso proxecto aparecerán dous novos ficheiros:

\begin{verbatim}
$ git status
On branch master
Your branch is up-to-date with 'origin/master'.
Changes to be committed:
  (use "git reset HEAD <file>..." to unstage)

    new file:   .gitmodules
    new file:   kicad/ftlibrary
\end{verbatim}

Git engadíu automáticamente os dous novos ficheiros, o directorio que
contén a nosa biblioteca eo ficheiro \textbf{.gitmodule} que levará o
control de todolos submódulos que usemos.

En realidade os ficheiros que compoñen a biblioteca non pertencen ao
noso depósito de software, git só leva conta da versión da biblioteca de
Freetronics que estamos a usar.

Se queres saber mais de esta potente funcionalidade de git podes leer:
\url{http://www.git-scm.com/book/en/v2/Git-Tools-Submodules}

\subsection{\texorpdfstring{Configurar \emph{Eescheme} para usar a nova
biblioteca}{Configurar Eescheme para usar a nova biblioteca}}\label{configurar-eescheme-para-usar-a-nova-biblioteca}

No menú Preferences -\textgreater{} Component Library sinalamos na ventá
inferior o directorio do noso proxecto. Na ventá superior engadimos o
ficheiro da biblioteca.

No github da biblioteca nos aconsellan poñer a biblioteca de primeira na
nosa lista por que definen todo tipo de compoñentes. Nos de momento
seguimos o consello de Freetronics, e a puxemos de primeira.

\subsection{\texorpdfstring{Configurar acceso aos datos de pegadas
(\emph{footprints}) en
pcbnew}{Configurar acceso aos datos de pegadas (footprints) en pcbnew}}\label{configurar-acceso-aos-datos-de-pegadas-footprints-en-pcbnew}

Configuramos un ficheiro para o noso proxecto declarando os
\emph{footprint} extra que imos a utilizar.

\begin{verbatim}
(fp_lib_table
  (lib
   (name FT)
   (type KiCad)
   (uri ${KIPRJMOD}/ftlibrary/freetronics_footprints.pretty)
   (options "")
   (descr "Freetronics Kicad Library")
   )
)
\end{verbatim}

Engadimos o novo ficheiro ao noso repositorio

\begin{verbatim}
git add fp-lib-table
\end{verbatim}

Abrimos \emph{Pcbnew} e no menú
\emph{Preferences-\textgreater{}Footprint Libraries Manager} comprobamos
que na pestaña \emph{Project Specific Libraries} figura o noso ficheiro.

\subsection{Outra biblioteca moi
currada}\label{outra-biblioteca-moi-currada}

\url{git://smisioto.eu/KiCad_libs.git}

\subsection{Ainda mais bibliotecas}\label{ainda-mais-bibliotecas}

\url{http://www.kicadlib.org/}

\subsection{Instalación das
bibliotecas}\label{instalaciuxf3n-das-bibliotecas}

\url{http://www.arunet.co.uk/tkboyd/ele2pcbka.htm}

\section{Tutorial}\label{tutorial}

\subsection{A pantalla xeral}\label{a-pantalla-xeral}

\begin{center}\rule{0.5\linewidth}{\linethickness}\end{center}

Pantalla xeral de KiCad opcións, citar a lista de hotkeys

\begin{center}\rule{0.5\linewidth}{\linethickness}\end{center}

\subsection{Abrindo un proxecto}\label{abrindo-un-proxecto}

Abrimos un novo proxecto: File::New Project (Ctrl+N)
\textbf{sandbox\_shield}

\begin{center}\rule{0.5\linewidth}{\linethickness}\end{center}

falar das propiedades do documento

\begin{center}\rule{0.5\linewidth}{\linethickness}\end{center}

\subsection{Crear e Editar o esquema do
circuito}\label{crear-e-editar-o-esquema-do-circuito}

O primeiro que imos facer é o esquema do circuito. Para isto temos que
usar a ferramenta \emph{Eeschema} que podemos atopar en tres lugares
diferentes \footnote{Isto de ter varios xeitos de facer unha cousa é
  habitual en KiCad como iremos vendo} na barra de iconos de
ferramentas, no menú de KiCad no título da fiestra, ou có atallo
\textbf{Ctrl+E}.

Abrimos eescheme e creamos un novo ficheiro de esquema.

\subsubsection{Checklist}\label{checklist}

\begin{itemize}
\itemsep1pt\parskip0pt\parsep0pt
\item
  Crear o esquema do circuito (usando Eescheme)
\item
  Chequeo de erros (opción \emph{Perform Electrical Rules Check})
\item
  Xerar o ficheiro NET (opción \emph{Generate netlist})
\item
  Asignar as pegadas (\emph{footprints}) aos compoñentes
\end{itemize}

\subsubsection{Tips}\label{tips}

\begin{itemize}
\itemsep1pt\parskip0pt\parsep0pt
\item
  Falar dos flags

  \begin{itemize}
  \itemsep1pt\parskip0pt\parsep0pt
  \item
    Power flags
  \item
    Not used flag
  \end{itemize}
\end{itemize}

\section{Meta}\label{meta}

Este documento está escrito en
\href{http://pandoc.org/README.html}{Markdown-Pandoc}. Pandoc e un
sistema moi sinxelo de documentación que permite xerar multiples
formatos de saída.

As fontes do documento están no directorio \textbf{doc/src}. Os formatos
de saída son este fichero \textbf{README.md} en formato Markdown-github
e os documentos que podes atopar no directorio \textbf{doc/out}
incluindo un pdf.

Os documentos xeneranse automáticamente a partir do ficheiro fonte sen
mai que executar:

\begin{verbatim}
$ cd doc
$ ./makeDoc
\end{verbatim}

É importante cambiar ao directorio doc antes de executar o
\textbf{makeDoc}.

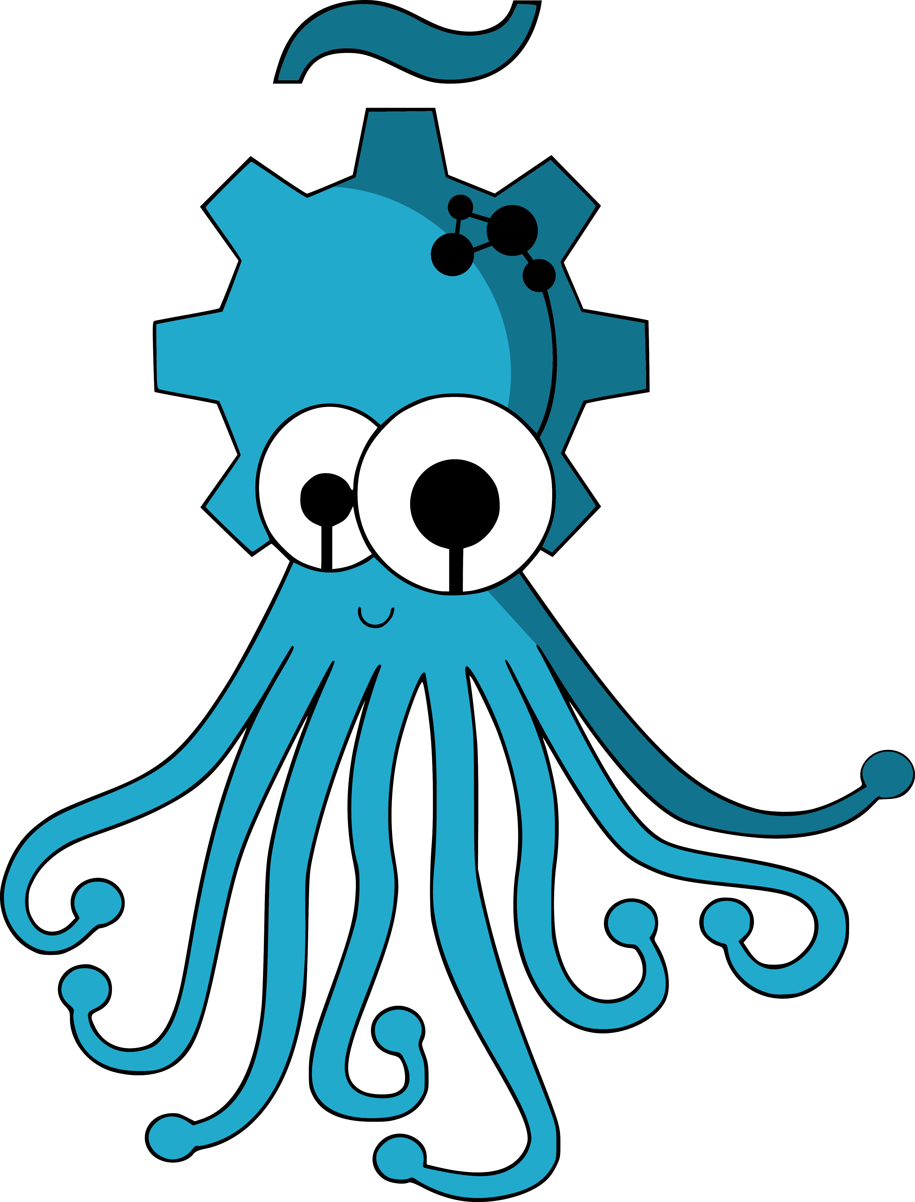
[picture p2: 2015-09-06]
doc/src/img/OSHWI_color.png

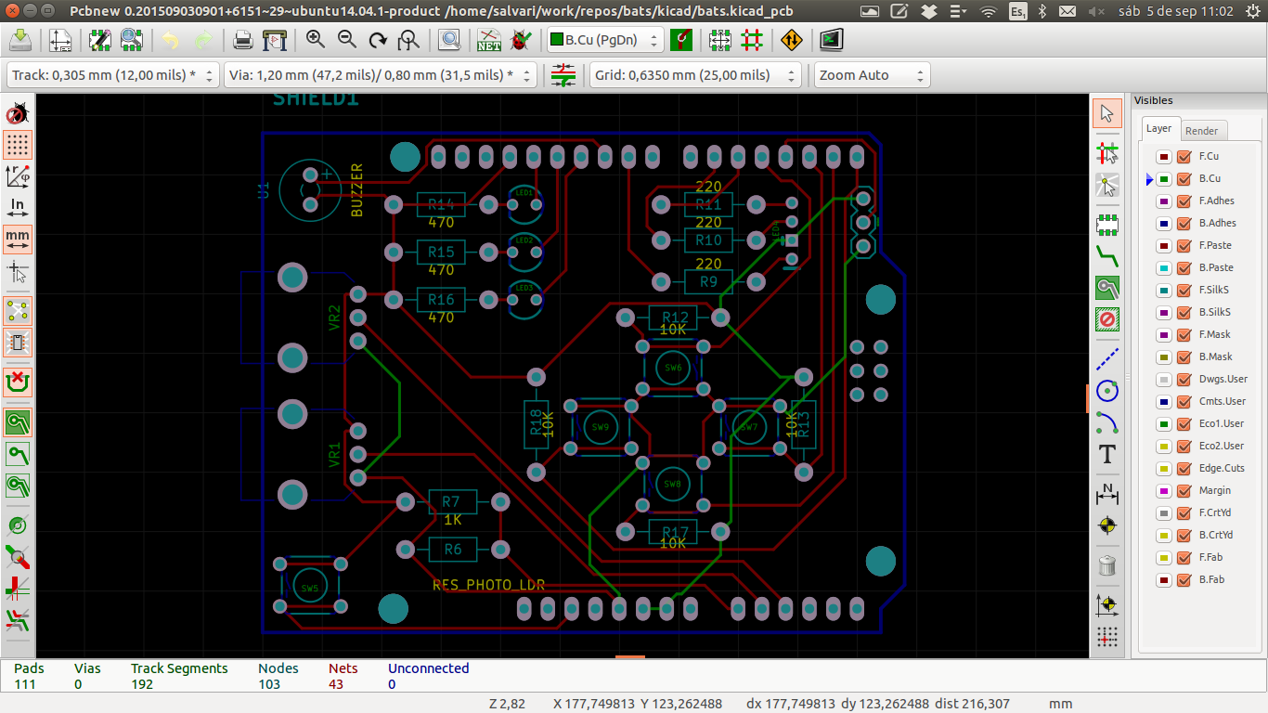
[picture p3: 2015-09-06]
doc/src/img/Bats.png

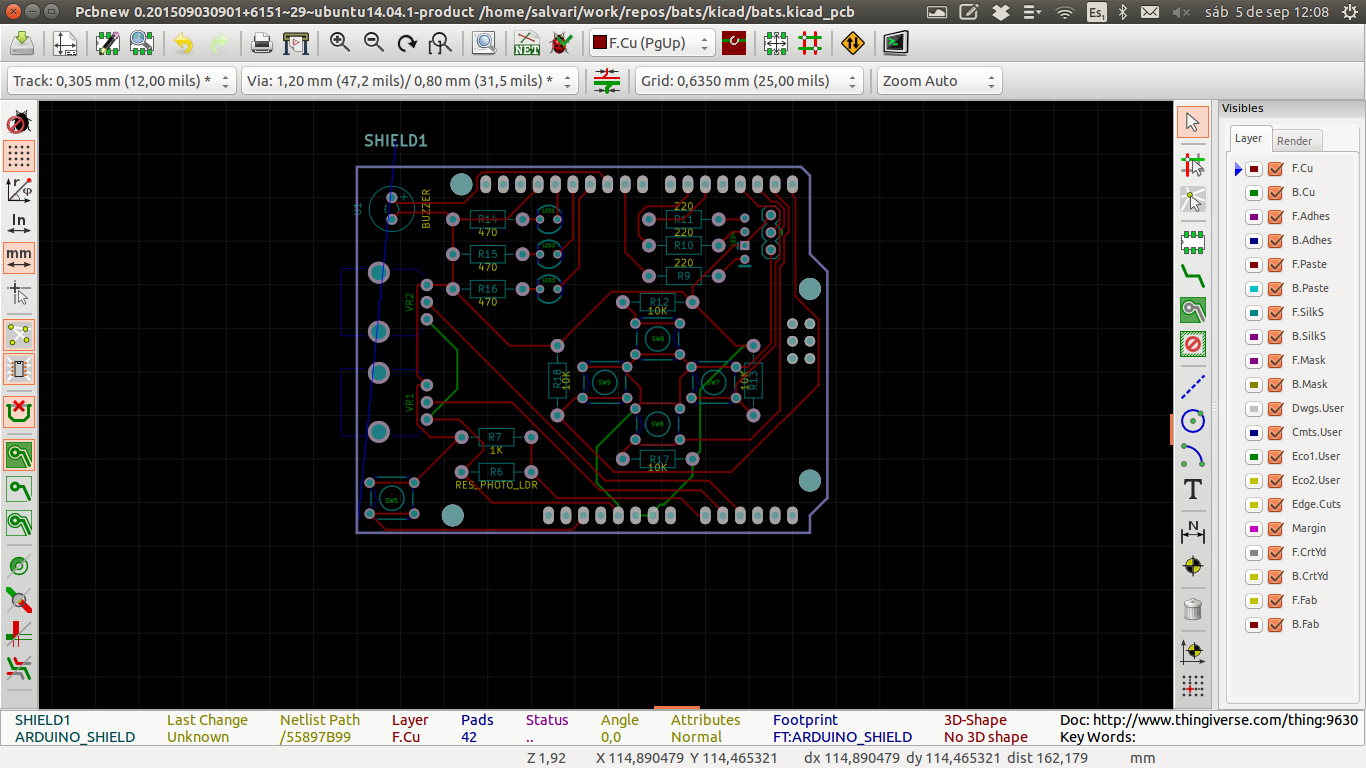
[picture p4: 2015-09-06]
doc/src/img/Bats_2.png

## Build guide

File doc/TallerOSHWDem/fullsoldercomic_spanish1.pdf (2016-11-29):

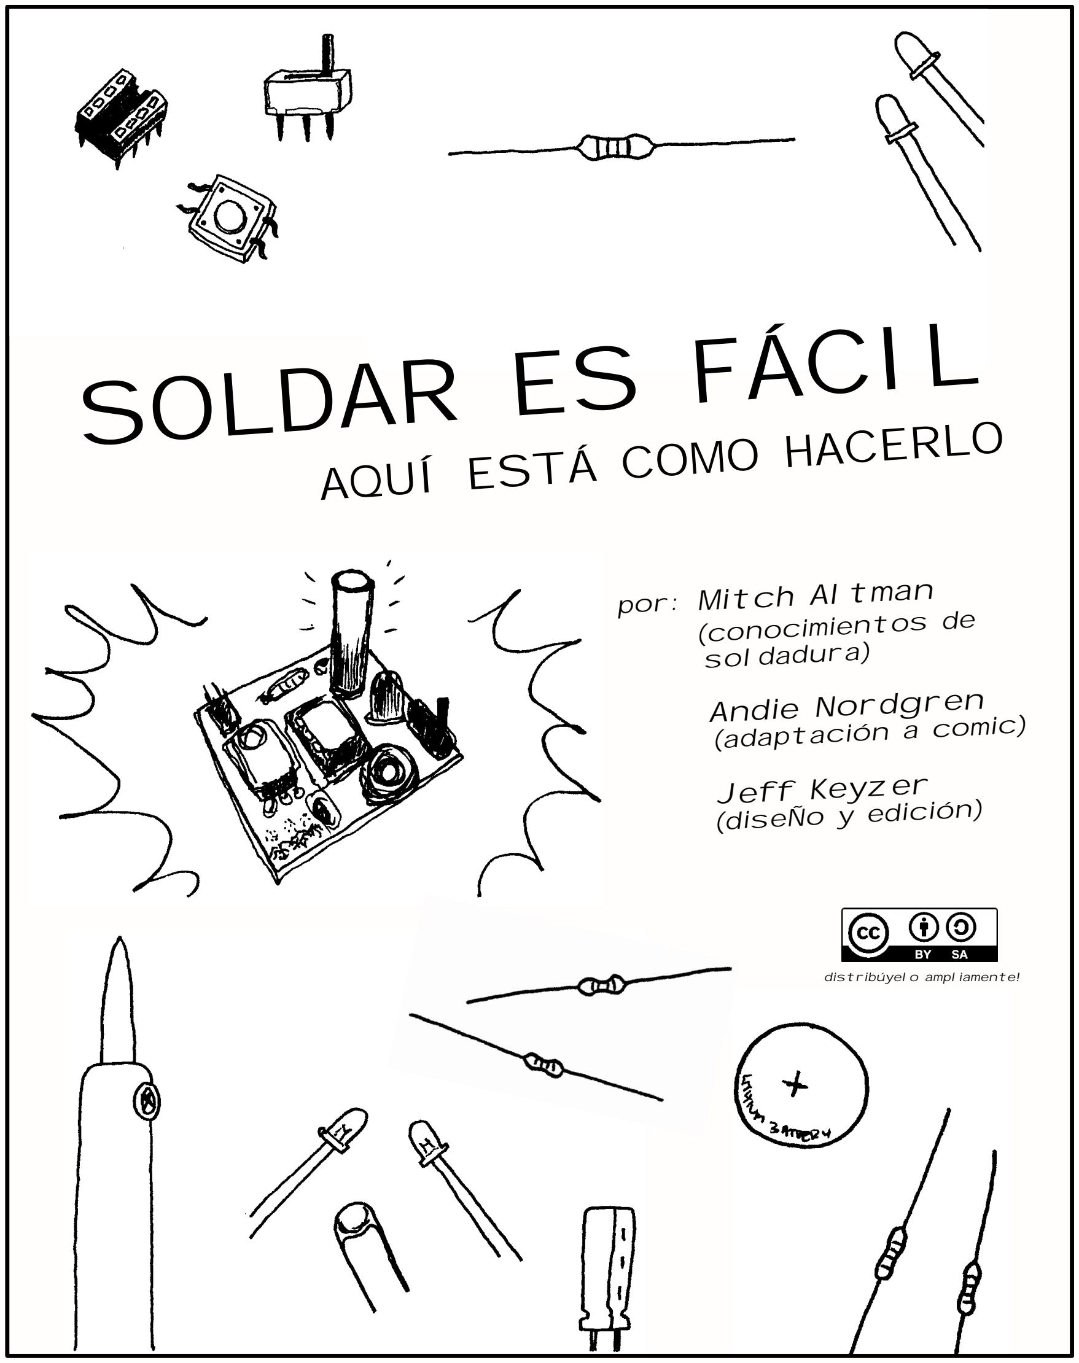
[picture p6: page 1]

# SOLDAR ES FÁCIL AQUÍ ESTÁ COMO HACERLO

# por: Mitch Altman

# Andie Nordgren

# (adaptación a comic)

# Jeff Keyzer

# (diseÑo y edición)

# (conocimientos de soldadura)

distribúyelo ampliamente!

# SOLDAR

### DE VERAS LO ES!

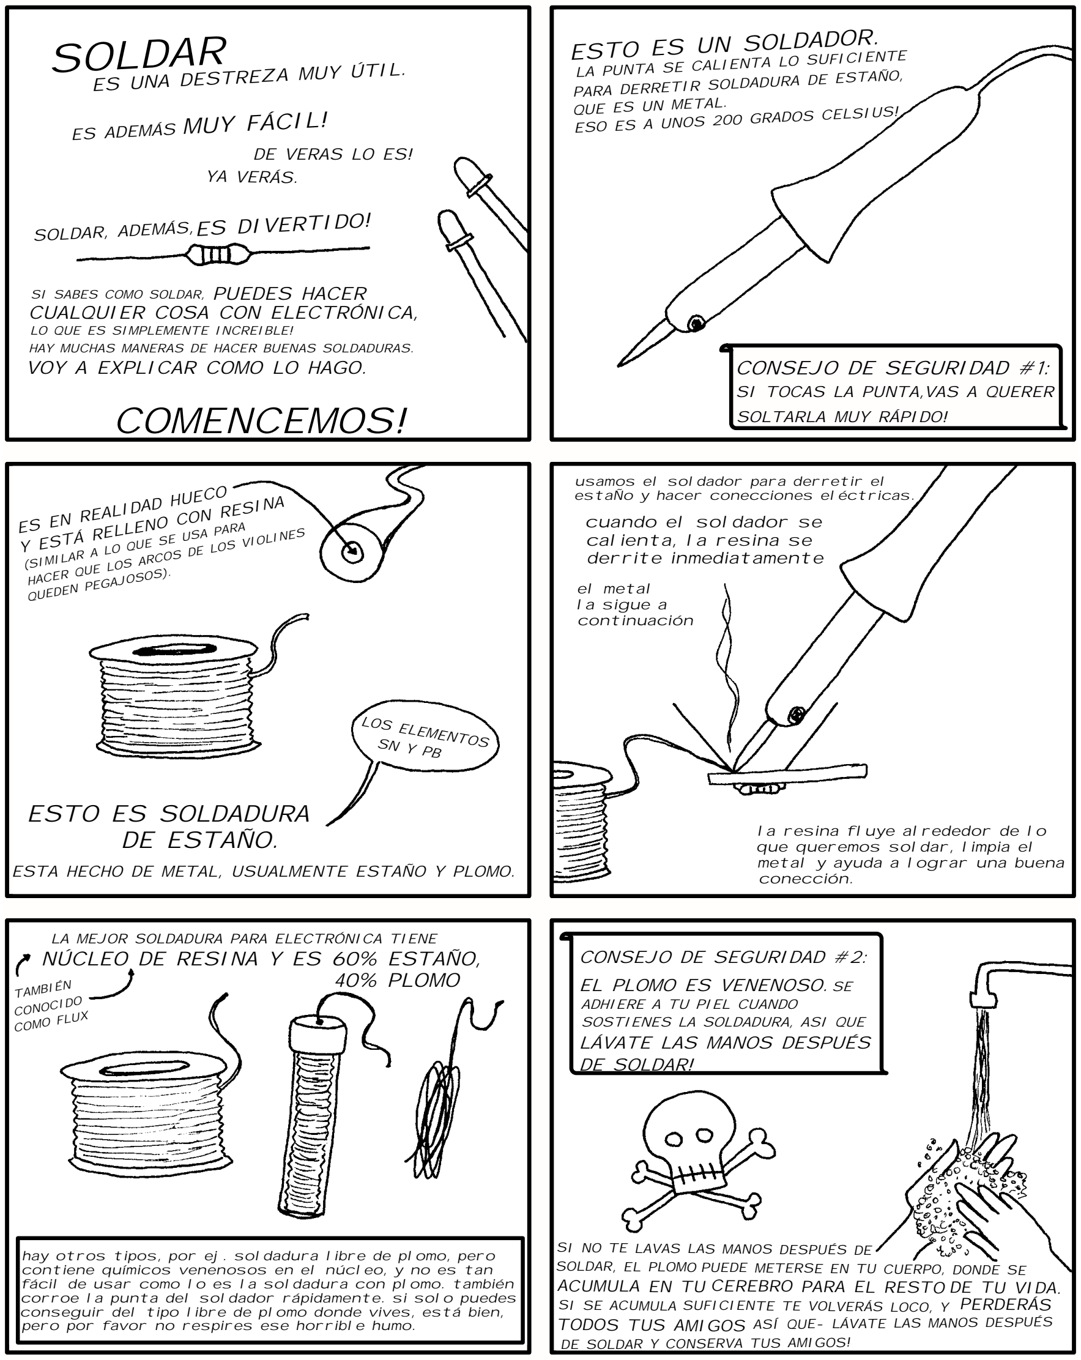
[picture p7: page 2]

## Es tambi´en muy fácil!

# Soldering SoldAR

# SoldAr

SOLDAR ES UNA DESTREZA MUY ÚTIL.

### ES ADEMÁS MUY FÁCIL!

## SOLDAR, ADEMÁS, ES DIVERTIDO!

YA VERÁS.

SI SABES COMO SOLDAR, PUEDES HACER
CUALQUIER COSA CON ELECTRÓNICA,
LO QUE ES SIMPLEMENTE INCREIBLE!
HAY MUCHAS MANERAS DE HACER BUENAS SOLDADURAS.
VOY A EXPLICAR COMO LO HAGO.

# COMENCEMOS!

ESTO ES UN SOLDADOR.
LA PUNTA SE CALIENTA LO SUFICIENTE PARA DERRETIR SOLDADURA DE ESTAÑO,

ESO ES A UNOS 200 GRADOS CELSIUS!

## CONSEJO DE SEGURIDAD #1:

### SI TOCAS LA PUNTA,VAS A QUERER SOLTARLA MUY RÁPIDO!

## ES EN REALIDAD HUECO

## Y ESTÁ RELLENO CON RESINA

(SIMILAR A LO QUE SE USA PARA
HACER QUE LOS ARCOS DE LOS VIOLINES

QUEDEN PEGAJOSOS).

QUE ES UN METAL.

# ESTO ES SOLDADURA

ESTA HECHO DE METAL, USUALMENTE ESTAÑO Y PLOMO.

DE ESTAÑO.

LOS ELEMENTOS
SN Y PB

## CONSEJO DE SEGURIDAD #2:

LA MEJOR SOLDADURA PARA ELECTRÓNICA TIENE
NÚCLEO DE RESINA Y ES 60% ESTAÑO,

## 40% PLOMO

TAMBIÉN
CONOCIDO
COMO FLUX

## EL PLOMO ES VENENOSO. SE

ADHIERE A TU PIEL CUANDO
SOSTIENES LA SOLDADURA, ASI QUE

## LÁVATE LAS MANOS DESPUÉS DE SOLDAR!

SI NO TE LAVAS LAS MANOS DESPUÉS DE PUEDE METERSE EN TU CUERPO, DONDE SE

### ACUMULA EN TU

SI SE ACUMULA
ASÍ QUE- LÁVATE LAS MANOS DESPUÉS

CEREBRO PARA EL RESTO DE TU VIDA.
SUFICIENTE TE VOLVERÁS LOCO, Y PERDERÁS

### TODOS TUS AMIGOS

SOLDAR, EL PLOMO

DE SOLDAR Y CONSERVA TUS AMIGOS!

### cuando el soldador se calienta, la resina se derrite inmediatamente

el metal
la sigue a
continuación

usamos el soldador para derretir el estaÑo y hacer conecciones eléctricas.

la resina fluye alrededor de lo que queremos soldar, limpia el metal y ayuda a lograr una buena conección.

hay otros tipos, por ej. soldadura libre de plomo, pero contiene químicos venenosos en el núcleo, y no es tan fácil de usar como lo es la soldadura con plomo. también corroe la punta del soldador rápidamente. si solo puedes conseguir del tipo libre de plomo donde vives, está bien, pero por favor no respires ese horrible humo.

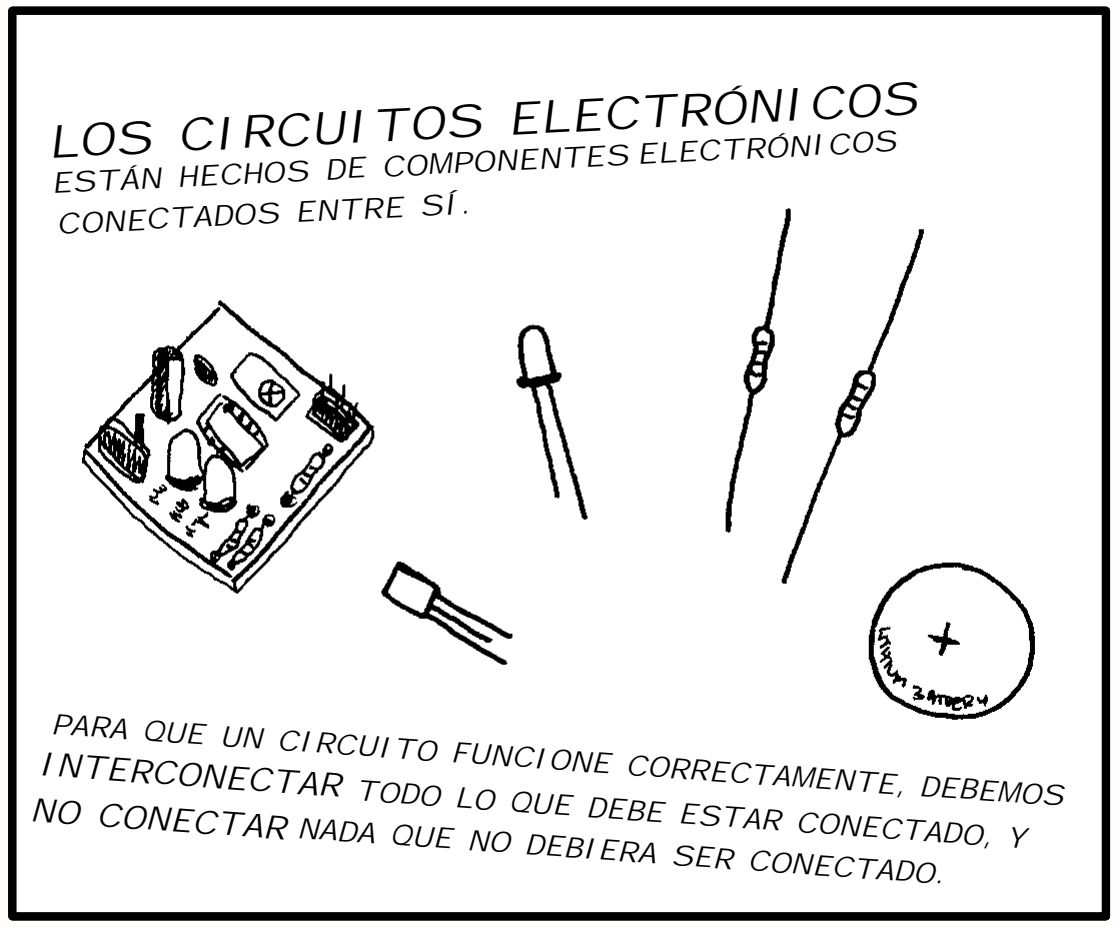
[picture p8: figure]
LOS CIRCUITOS ELECTRÓNICOS; ESTÁN HECHOS DE COMPONENTES CONECTADOS ENTRE SÍ.; ELECTRÓNICOS

PARA QUE UN CIRCUITO FUNCIONE CORRECTAMENTE, DEBEMOS INTERCONECTAR TODO LO QUE DEBE ESTAR CONECTADO, Y NADA QUE NO DEBIERA SER CONECTADO. NO CONECTAR

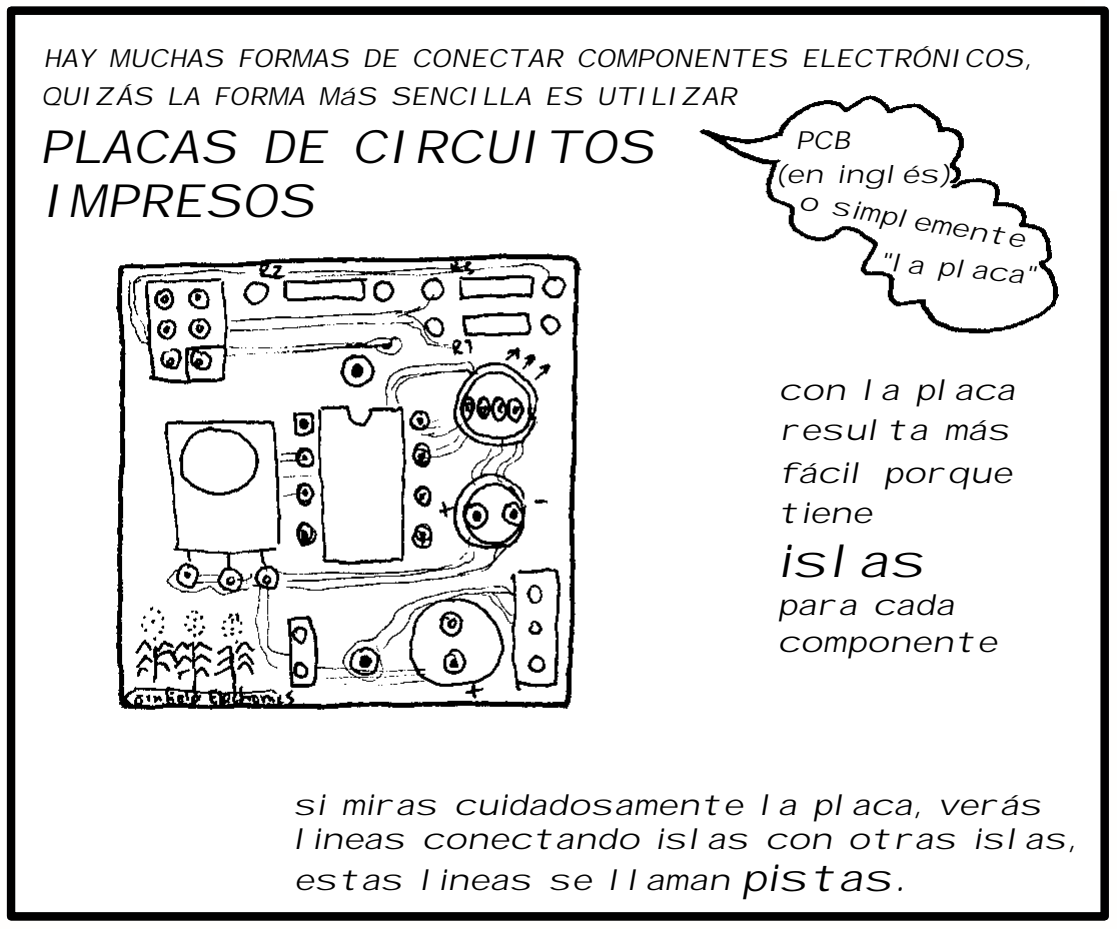
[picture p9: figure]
o simplemente; "la placa"

HAY MUCHAS FORMAS DE CONECTAR COMPONENTES ELECTRÓNICOS, QUIZÁS LA FORMA MáS SENCILLA ES UTILIZAR PLACAS DE CIRCUITOS PCB (en inglés) IMPRESOS

| con la placa resulta más fácil porque tiene islas para cada componente si miras cuidadosamente la placa, verás lineas conectando islas con otras islas, estas lineas se llaman pistas.

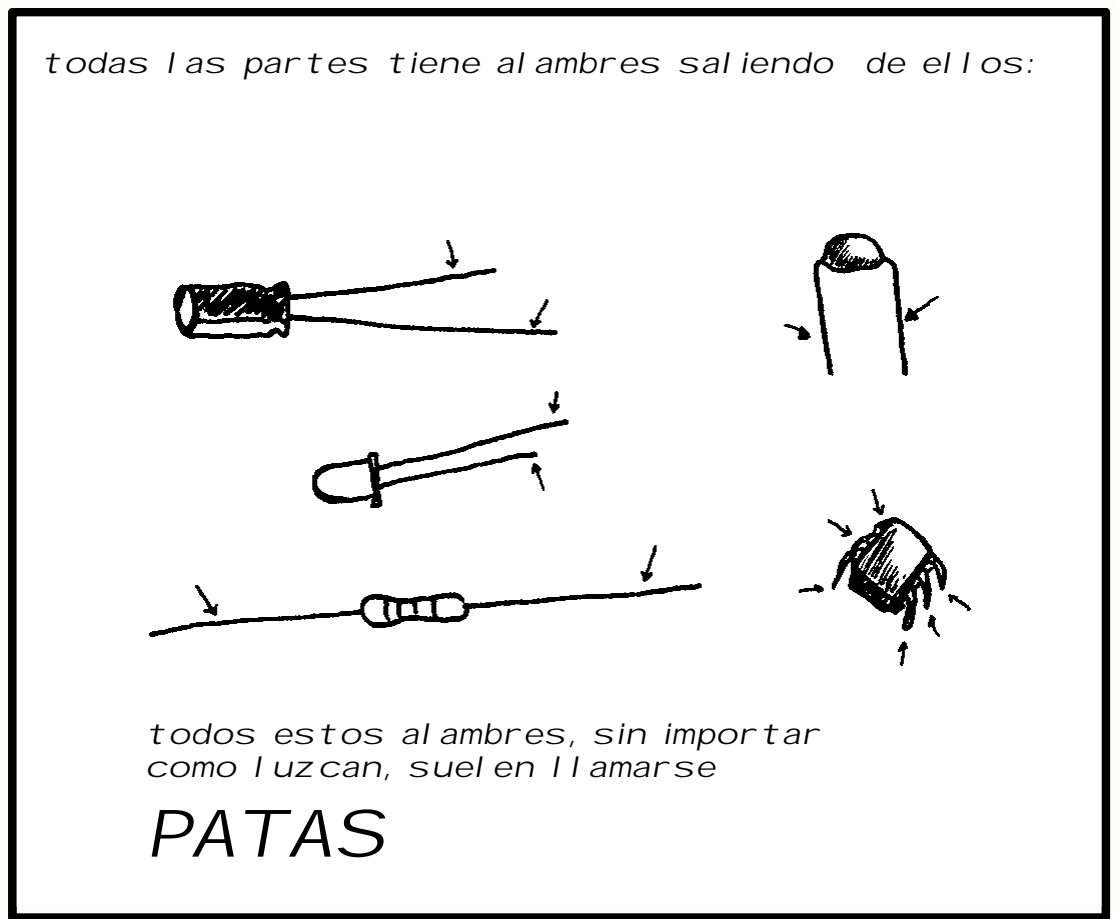
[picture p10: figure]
todos estos alambres, sin importar como luzcan, suelen llamarse PATAS

todas las partes tiene alambres saliendo de ellos:

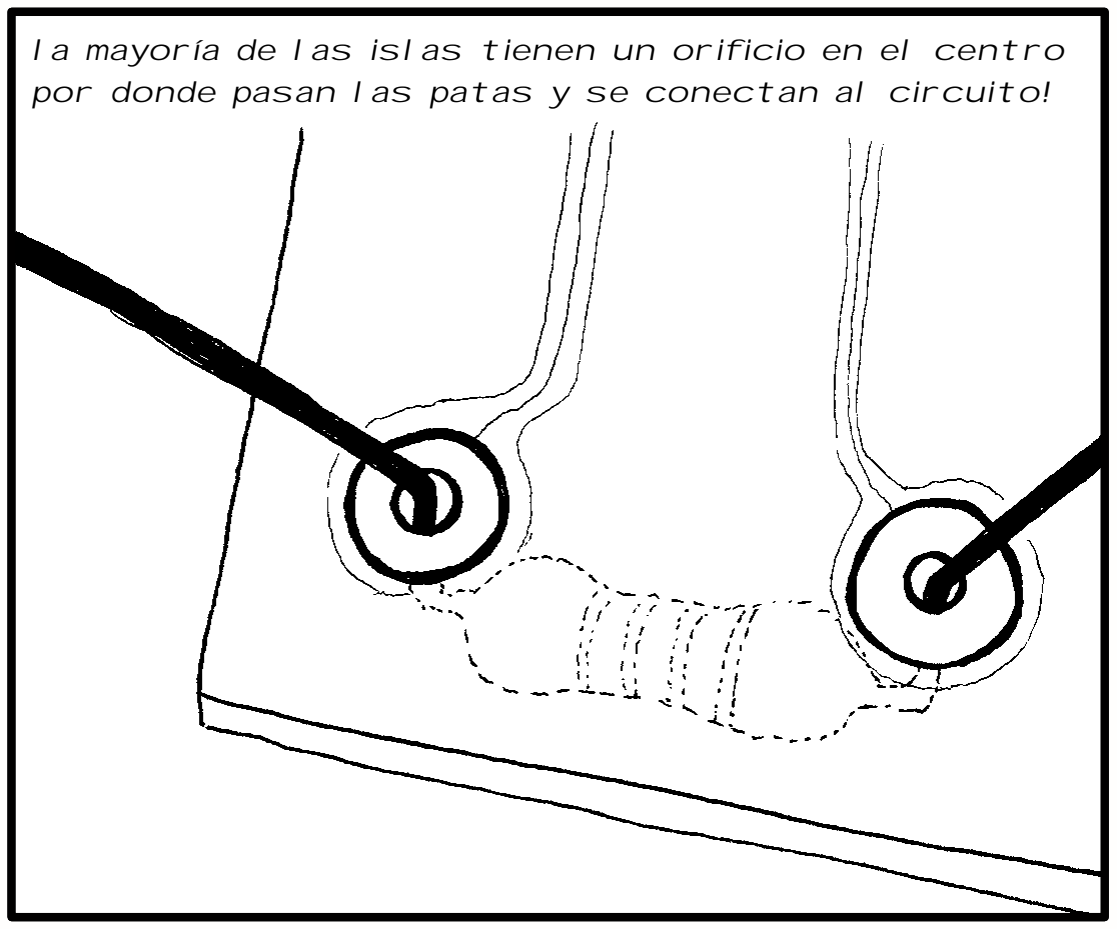
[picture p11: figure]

la mayoría de las islas tienen un orificio en el centro por donde pasan las patas y se conectan al circuito!

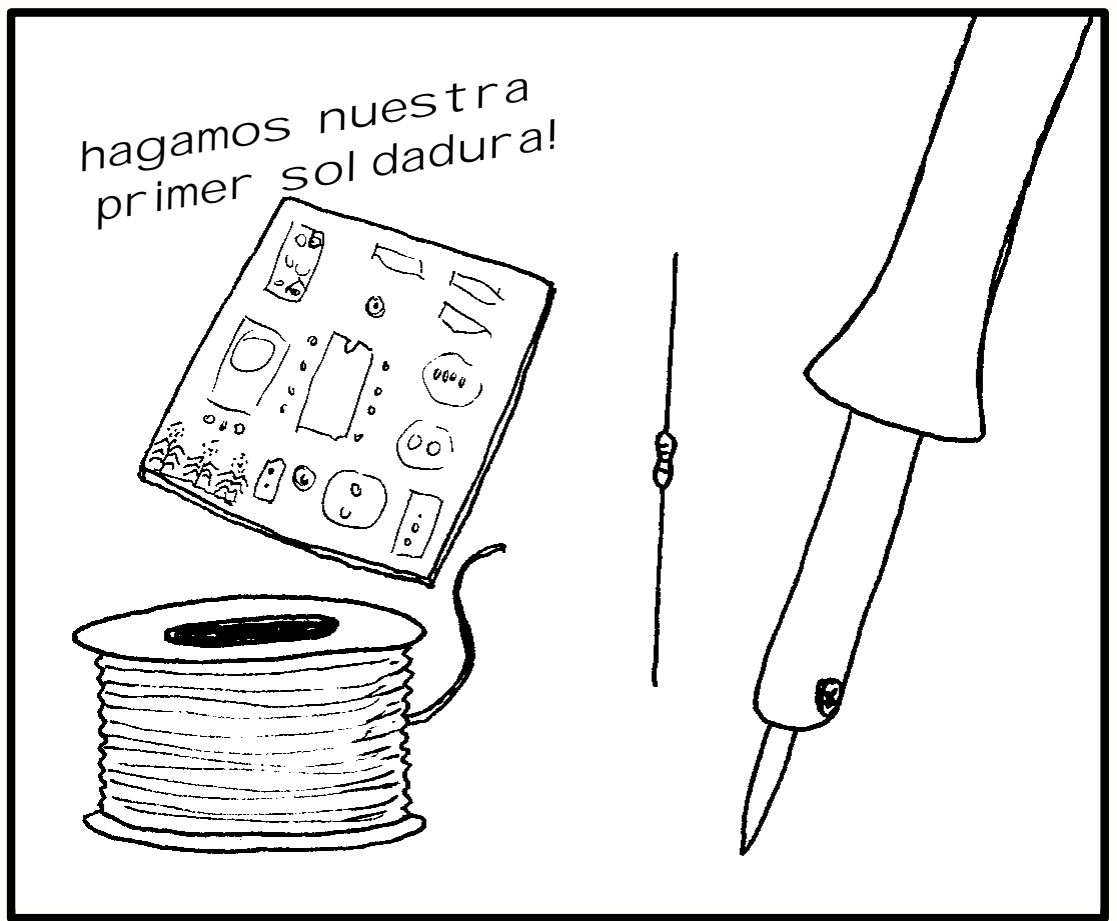
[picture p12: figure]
hagamos nuestra primer soldadura!

si pones todas las patas de los componentes en sus

respectivas islas y si pones todos los componentes en sus correctas posiciones

### y si haces buenas soldaduras

algunos
componentes
pueden ir de forma
incorrecta

## entonces el circuito funcionará!

esto es porque la placa conecta todo lo que debe ser conectado, y nada que no debiera conectarse.

comenzaremos con una resistencia.

las resistencias tienen dos patas y (al contrario de algunos componentes, como los diodos, que tiene un lado "más" y un lado "menos") pueden ser ubicadas en sus islas en cualquier dirección

las pcb usualmente tienen marcas que muestran donde vá cada componente (y si la orientación importa, la pcb suele tener alguna forma de enseÑartelo).

como la palabra "resistencia" comienza con la letra "r", la placa suele mostrar los lugares donde van las resistencias con una "r", seguido por el número de la resistencia, como en "r3"

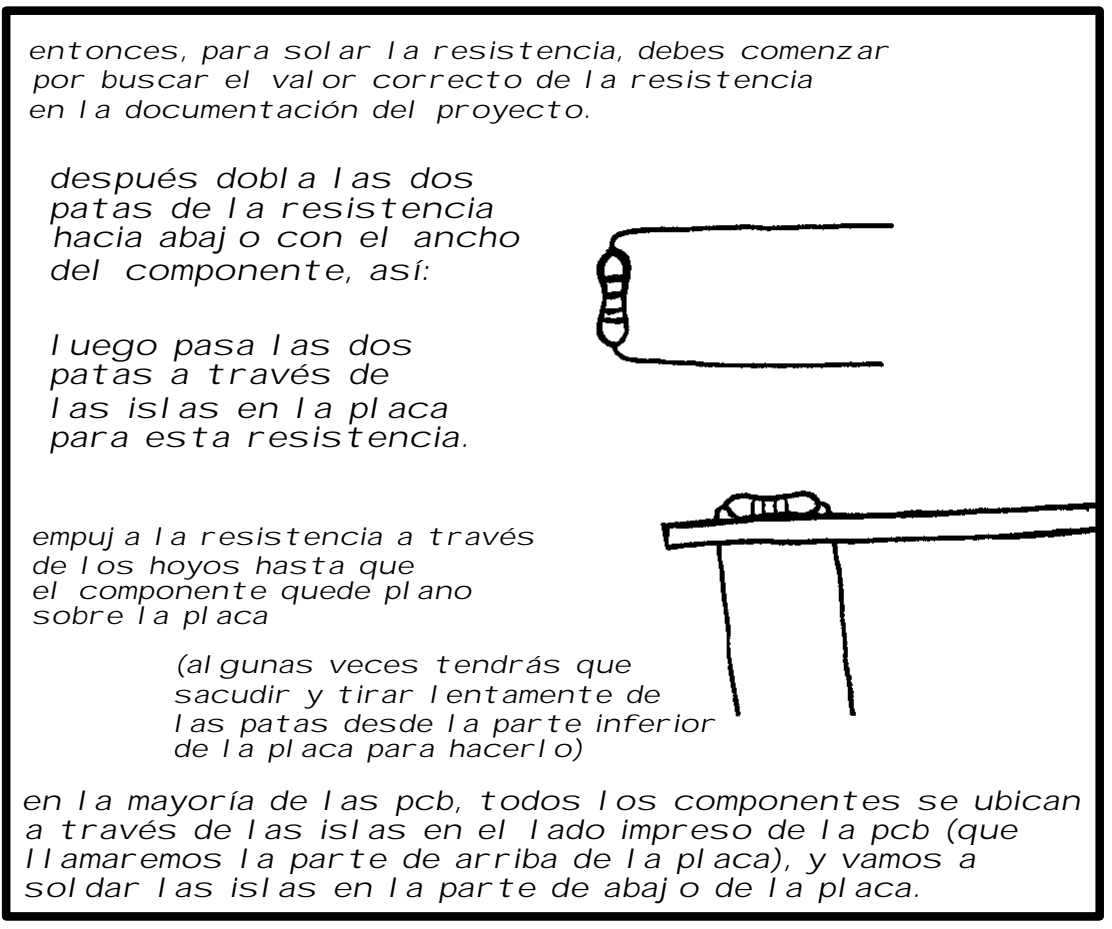
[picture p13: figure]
en la documentación del proyecto.; después dobla las dos patas de la resistencia hacia abajo con el ancho del componente, así:; luego pasa las dos patas a través de las islas en la placa para esta resistencia.; empuja la resistencia a través de los hoyos hasta que el componente quede plano sobre la placa; (algunas veces tendrás que sacudir y tirar lentamente de las patas desde la parte inferior de la placa para hacerlo)

entonces, para solar la resistencia, debes comenzar por buscar el valor correcto de la resistencia

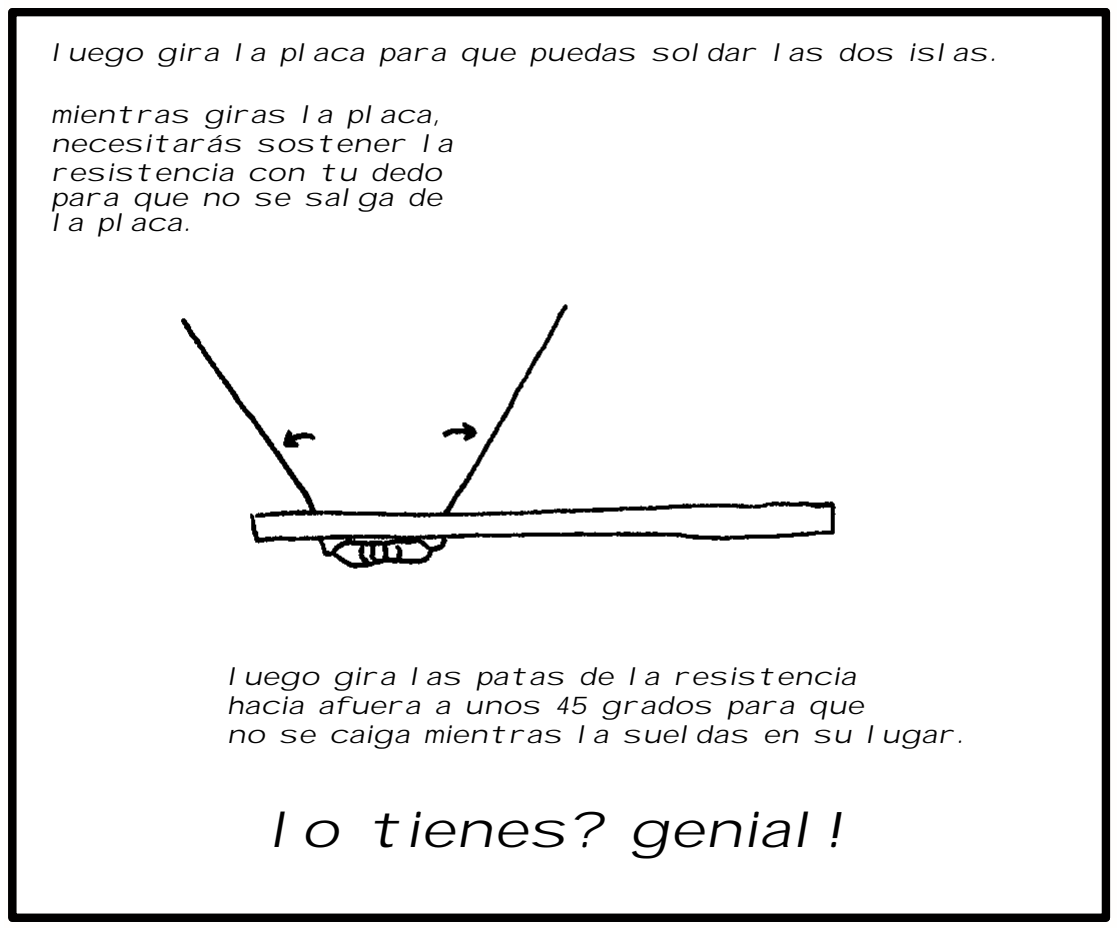
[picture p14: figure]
mientras giras la placa, necesitarás sostener la resistencia con tu dedo para que no se salga de la placa.; luego gira las patas de la resistencia hacia afuera a unos 45 grados para que; lo tienes? genial!
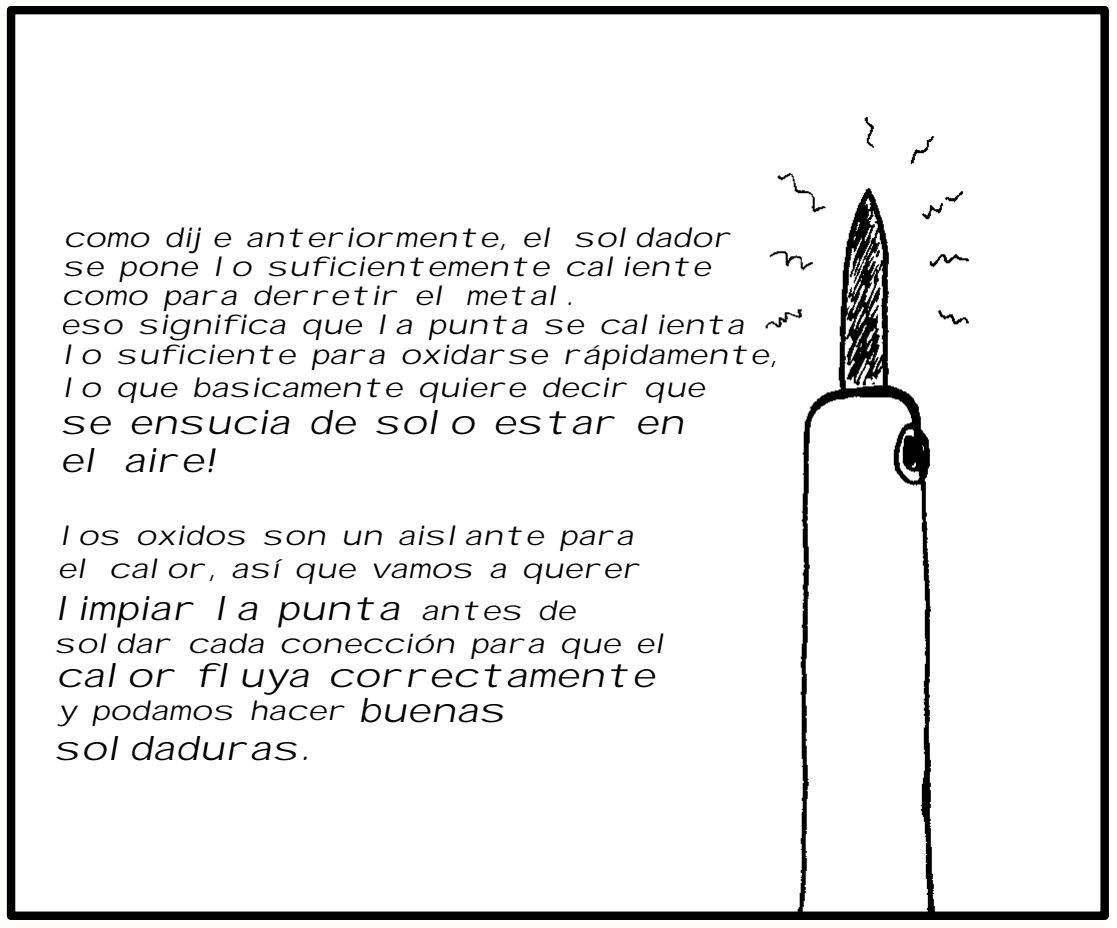
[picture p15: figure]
como dije anteriormente, el soldador se pone lo suficientemente caliente como para derretir el metal. eso significa que la punta se calienta; se ensucia de solo estar en; los oxidos son un aislante para el calor, así que vamos a querer limpiar la punta antes de soldar cada conección para que el calor fluya correctamente y podamos hacer buenas; lo que basicamente quiere decir que; el aire!; soldaduras.

luego gira la placa para que puedas soldar las dos islas.

no se caiga mientras la sueldas en su lugar.

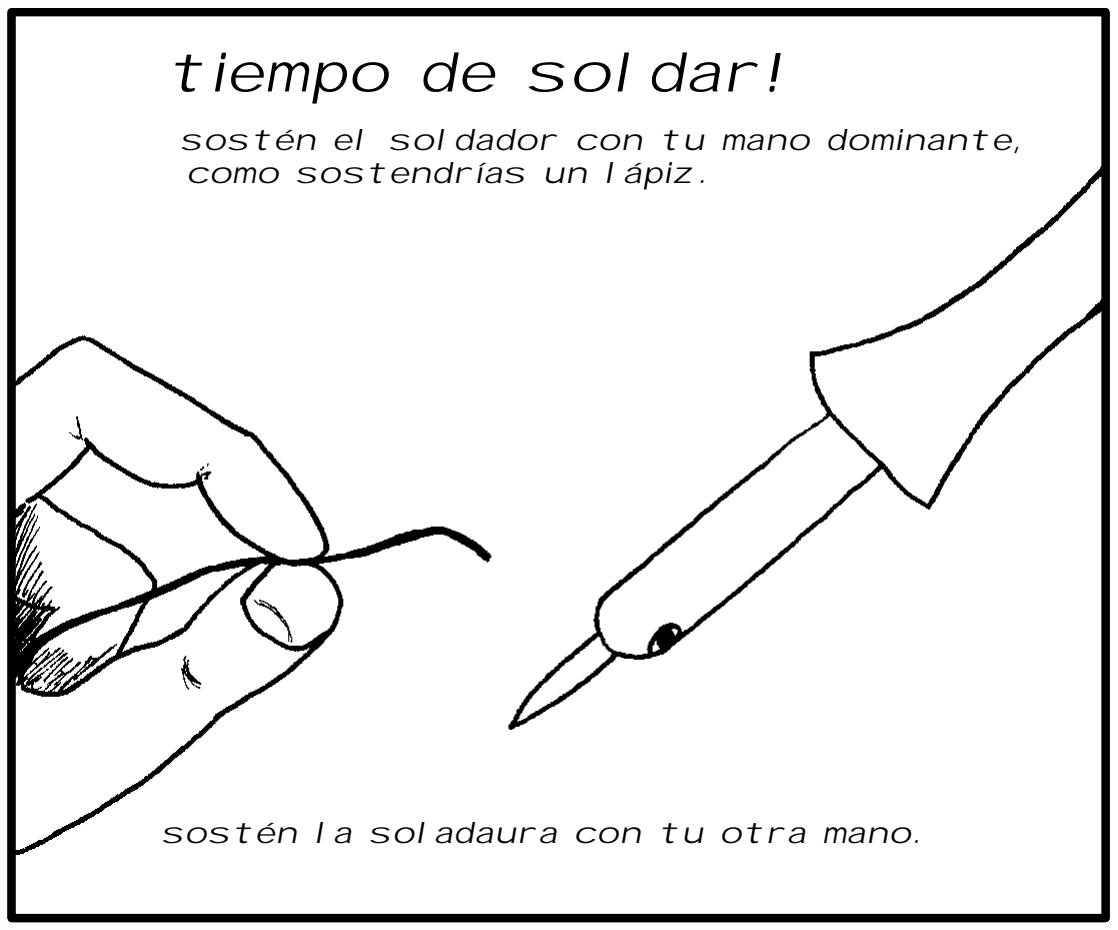
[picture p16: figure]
tiempo de soldar!; como sostendrías un lápiz.; sostén la soladaura con tu otra mano.

sostén el soldador con tu mano dominante,

esto debería volver la punta plateada y un poco brrillante

### lista para soldar. recuerda limpiar la punta así antes de cada conección que hagas-la punta se

oxida rápidamente!

## si la punta luce bien y brillante, podrás

hacer buenas conecciones.

para esto tenemos una esponja húmeda:
para limpiar el óxido de la punta. simplemente frota

### la punta a través de la esponja genilmente luego rota el soldador y frota nuevamente

a través de la esponja.

lo suficiente para oxidarse rápidamente, en la mayoría de las pcb, todos los componentes se ubican a través de las islas en el lado impreso de la pcb (que llamaremos la parte de arriba de la placa), y vamos a soldar las islas en la parte de abajo de la placa.

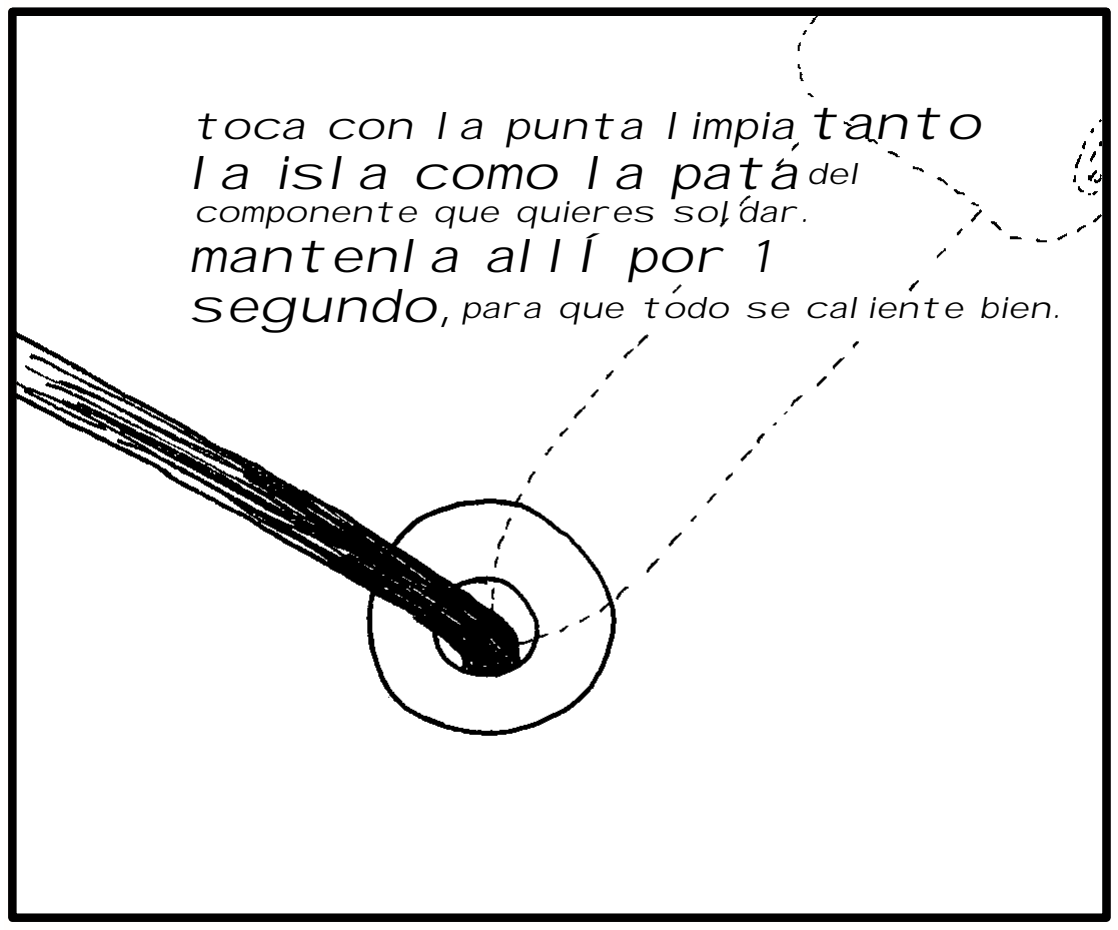
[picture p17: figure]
toca con la punta limpia tanto la isla como la pata del componente que quieres soldar. mantenla allÍ por 1
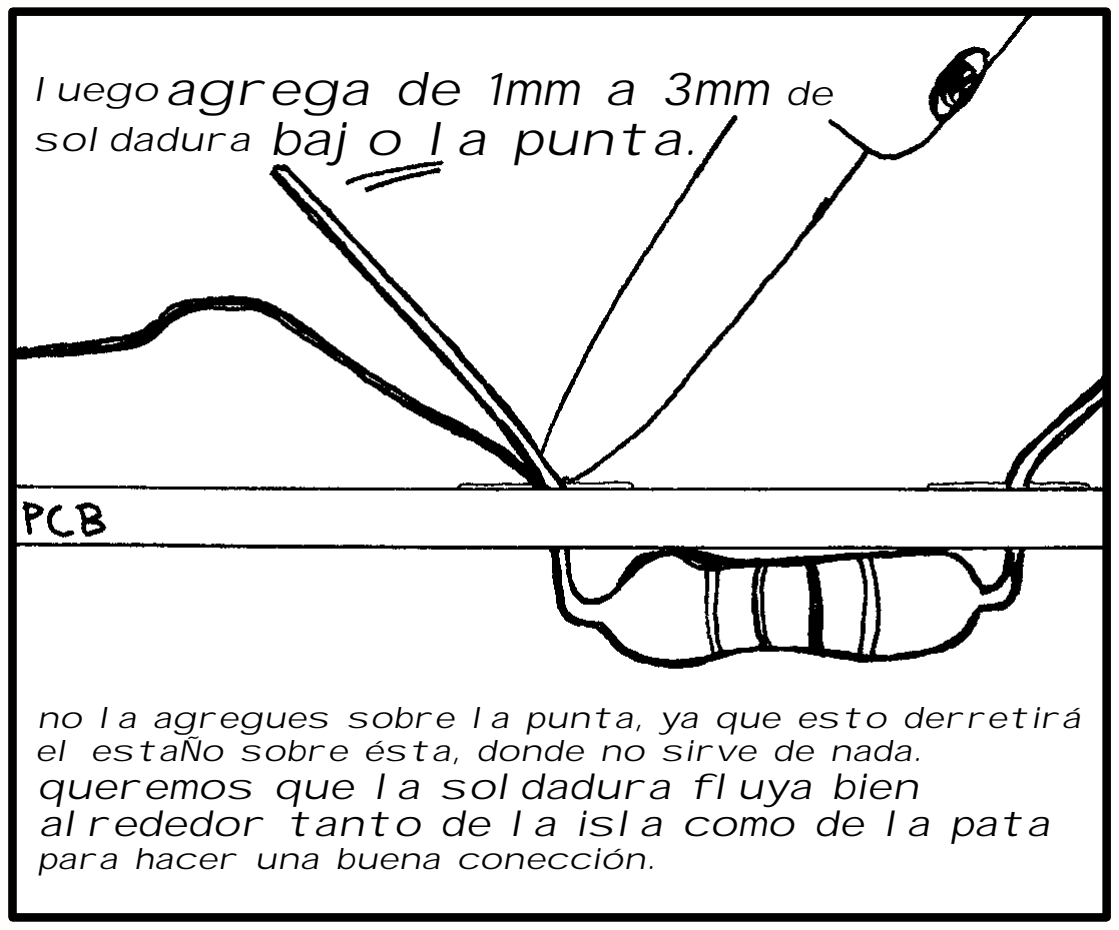
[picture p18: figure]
luego agrega de 1mm a 3mm soldadura bajo la punta.; queremos que la soldadura fluya bien; para hacer una buena conección.

segundo, para que todo se caliente bien.

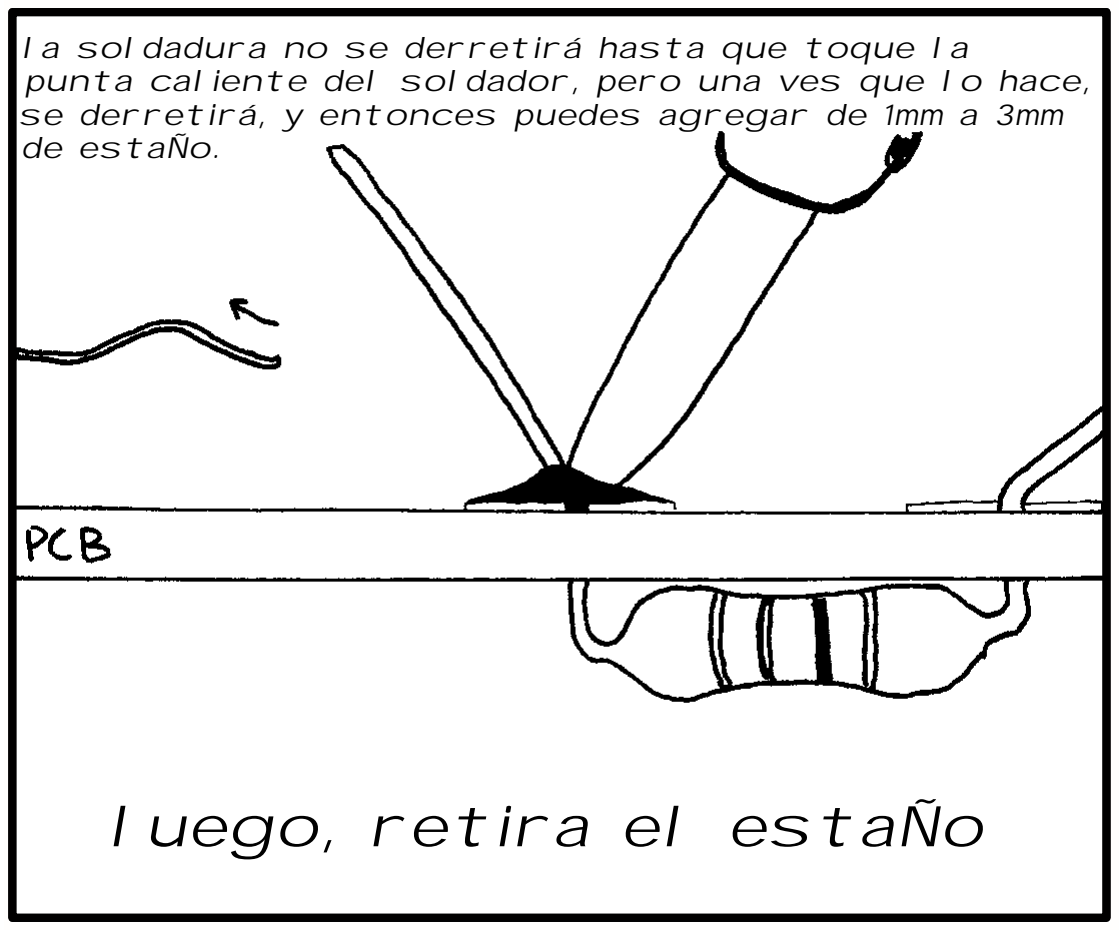
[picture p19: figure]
luego, retira el estaÑo; de estaÑo.

la soldadura no se derretirá hasta que toque la punta caliente del soldador, pero una ves que lo hace, se derretirá, y entonces puedes agregar de 1mm a 3mm

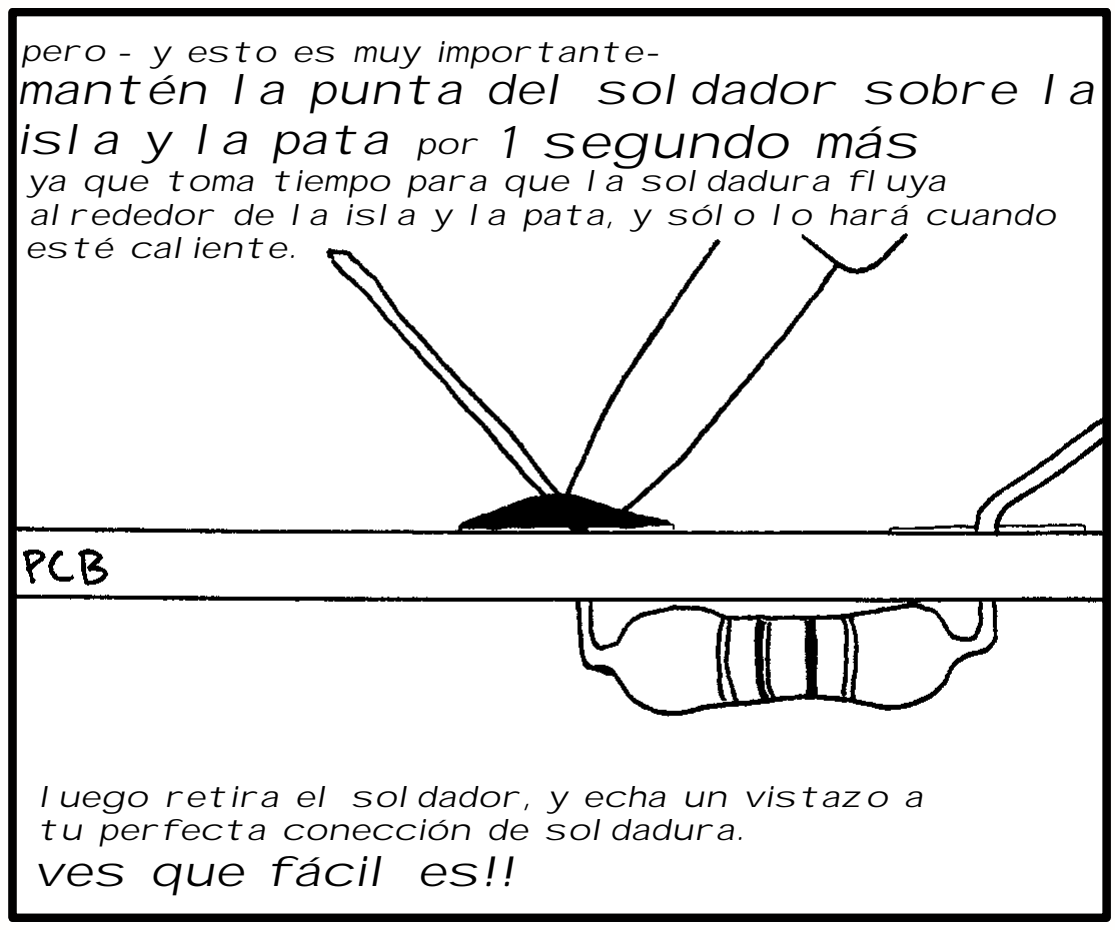
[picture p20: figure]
pero - y esto es muy importante- mantén la punta del soldador sobre la isla y la pata por 1 segundo más; esté caliente.; tu perfecta conección de soldadura. ves que fácil es!!

### ahora pon el soldador nuevamente sobre el

soporte mientras no lo estemos usando.

## el soporte mantiene el soldador de forma segura sobre la mesa..la mayoría de la gente dice

que no es divertido que aterrice sobre tu regazo!

no la agregues sobre la punta, ya que esto derretirá el estaÑo sobre ésta, donde no sirve de nada.

## alrededor tanto de la isla como de la pata

ya que toma tiempo para que la soldadura fluya alrededor de la isla y la pata, y sólo lo hará cuando

## ten en cuenta que la soldadura se enfría y endurece rápidamente por sí solo. sólo

toma cerca de un segundo. y luego estás listo para tu próxima conección.

ese humo que has visto
cuando la soldadura de

derretía es la resina
vaporizandose.

contiene algunos químicos
que no son buenos para tí, asi que trata de no aspirarlos!

## puedes soplar suavemente

si usas soldadura
libre de plomo,
entonces el humo
es realmente
desagradable, asi
que úsalo en
lugares bien

por favor trata
de no aspirar
el humo mientras
sueldas.

## sobre la conección mientras sueldas para mantener el humo lejos

de tus pumones.

estaÑo/plomo se

ventilados y

luego retira el soldador, y echa un vistazo a

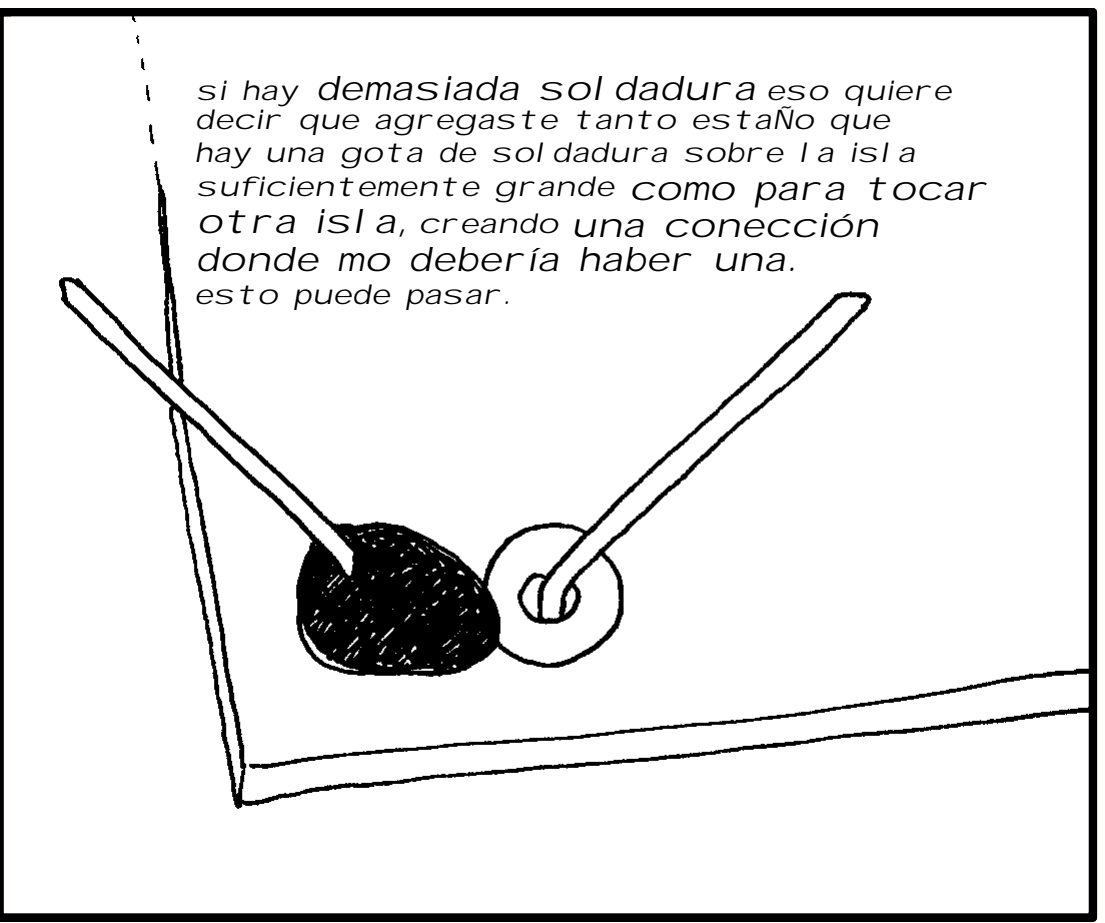
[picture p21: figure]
si hay demasiada soldadura eso quiere decir que agregaste tanto estaÑo que hay una gota de soldadura sobre la isla suficientemente grande como para tocar creando una conección; esto puede pasar.; otra isla, donde mo debería haber una.
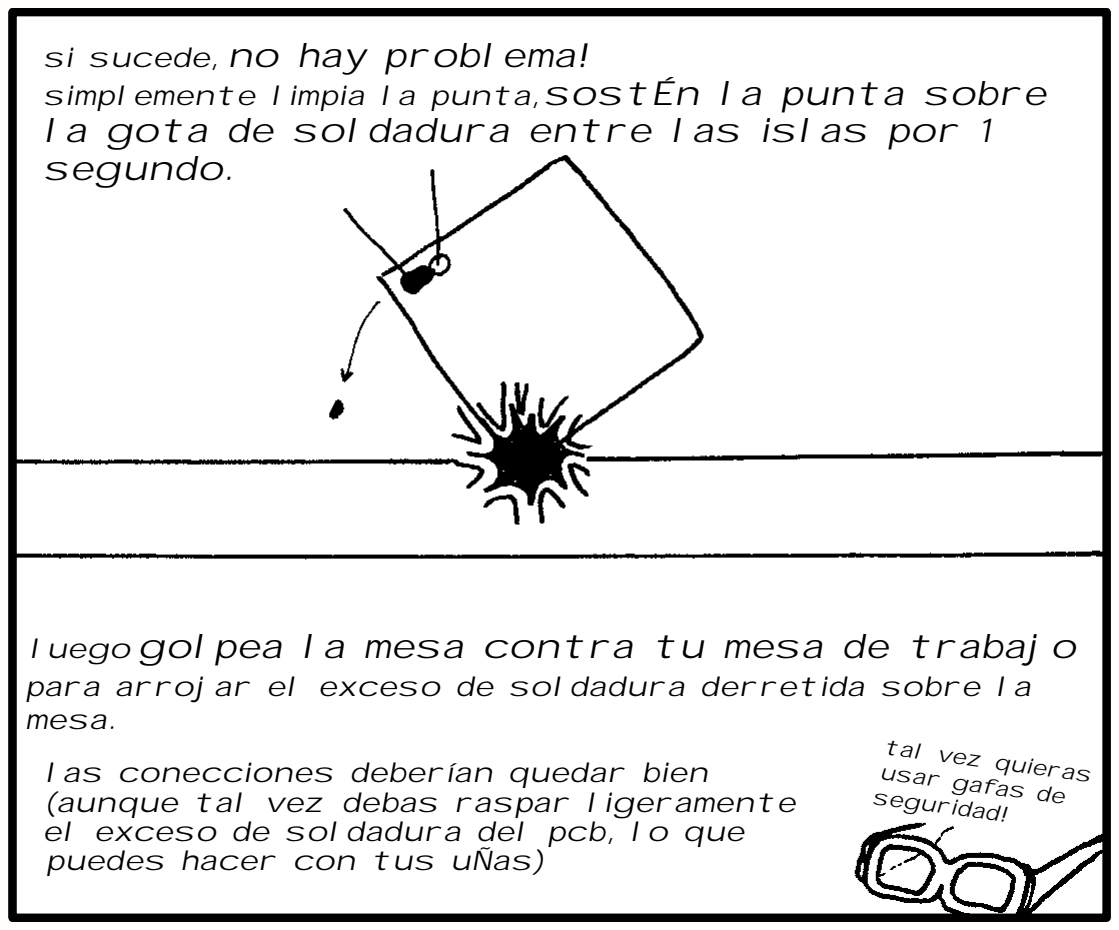
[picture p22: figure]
si sucede, no hay problema!; segundo.; tal vez quieras usar gafas de seguridad!; las conecciones deberían quedar bien; el exceso de soldadura del pcb, lo que puedes hacer con tus uÑas); mesa.

simplemente limpia la punta,sostÉn la punta sobre

### la gota de soldadura entre las islas por 1

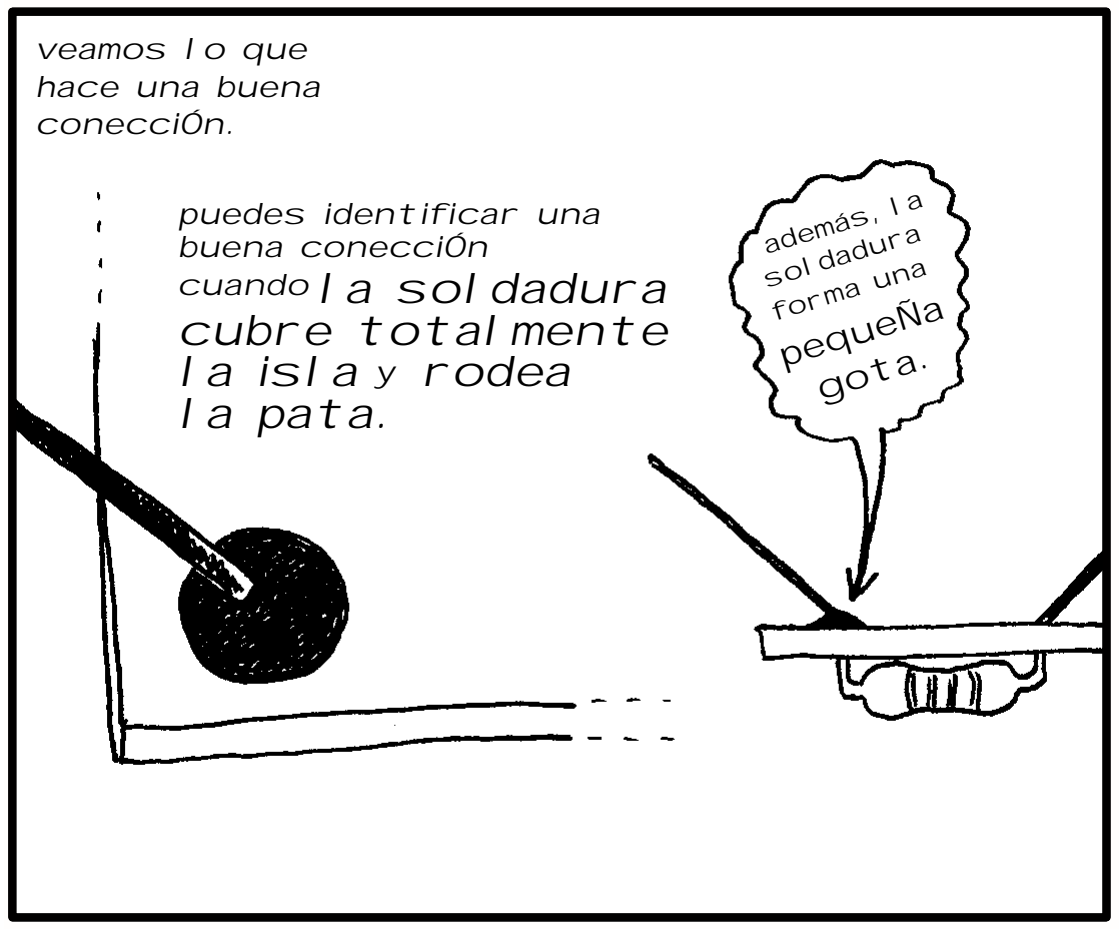
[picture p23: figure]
además, la soldadura forma una pequeÑa gota.; hace una buena; veamos lo que; conecciÓn.; puedes identificar una buena conecciÓn cuando la soldadura cubre totalmente la isla y rodea la pata.

ambas
bien!

bien tambiÉn!

a algunas personas les gusta soldar las partes a las islas luego de agregar varios componentes a la placa.

## yo prefiero poner y soldar sÓlo un componente a la placa al mismo tiempo. encuentro esto más

fÁcil ya que no hay demasiadas patas que puedan meterse en el camino de mi soldador.

si este es el caso, no hay problema-simplemente repite el procedimiento (limpiar la punta, tocar con la punta por 1 segundo la isla y la pata, agregar de 1mm a 3mm de estaÑo, retirar el estaÑo, mantener la punta por 1 segundo más, y retirar el soldador), y debería quedar bien.

### entre demasiada y muy poca soldadura hay

mucho margen.

### por esta razón es

que soldar es fácil.

### luego golpea la mesa contra tu mesa de trabajo

para arrojar el exceso de soldadura derretida sobre la

(aunque tal vez debas raspar ligeramente

además, si agrego más de un componente a la placa a veces olvido soldar alguna isla, ya que no es tán fácil (como pensarías que lo es) ver que conecciones están soldadas.

quizás
quieras
usar

gafas
de
seguridad!

después de soldar todas las patas del componente que estás soldando, es tiempo de cortar el
exceso de las patas.
esto debe hacerse para asegurar que el exceso de las patas no se doble y haga corto
con otra pata o una isla.

## consejo de seguridad #3: siempre

### sostén la pata que estás cortando con una

mano mientras cortas con la otra.

### si haces esto, siempre estarás a salvo

las patas que ya son muy cortas, como en zocalos

### de ci, no necesitan ser cortadas- tienen patas

que son muy cortas para doblarse y provocar cortos.

para acortar las patas, vamos a usar un

### pequeÑo alicate. un lado tiene un filo plano y el otro lado

tiene un surco profundo.

### coloca el filo plano abajo, paralelo al PCB, en la parte superior de la gota de

soldadura.

### aprieta la empuñadura y el filo

cortará de golpe.

lo que convierte
el exceso de la

## proyectil que golpeará justo en tu ojo!

pata en un

si esto sucede, entonces va a haber una
conección donde no queremos una.

si la pata a cortar es demasiado corta para sostener (pero lo suficientemente larga como para entrar en corto

### coloca el alicate, mantén

de la pata,

esto evitará que
el exceso de la
pata golpee a
alguien en el ojo
(o haga un corto
en algún lugar
de tu proyecto)

y luego aprieta.

con algo en tu pcb) entonces

## tus dedos por encima

si cometes algún error, está bien. todos

## los errores se pueden arreglar

(aunque algunos más fácilmente que otros).

## y cometiendo errores es como

aprendemos a volvernos mejores en todo lo que hacemos.
mientras que soldar es fácil,desoldar

## requiere mucha práctica. y si

cometes un error, tienes algo con que practicar!

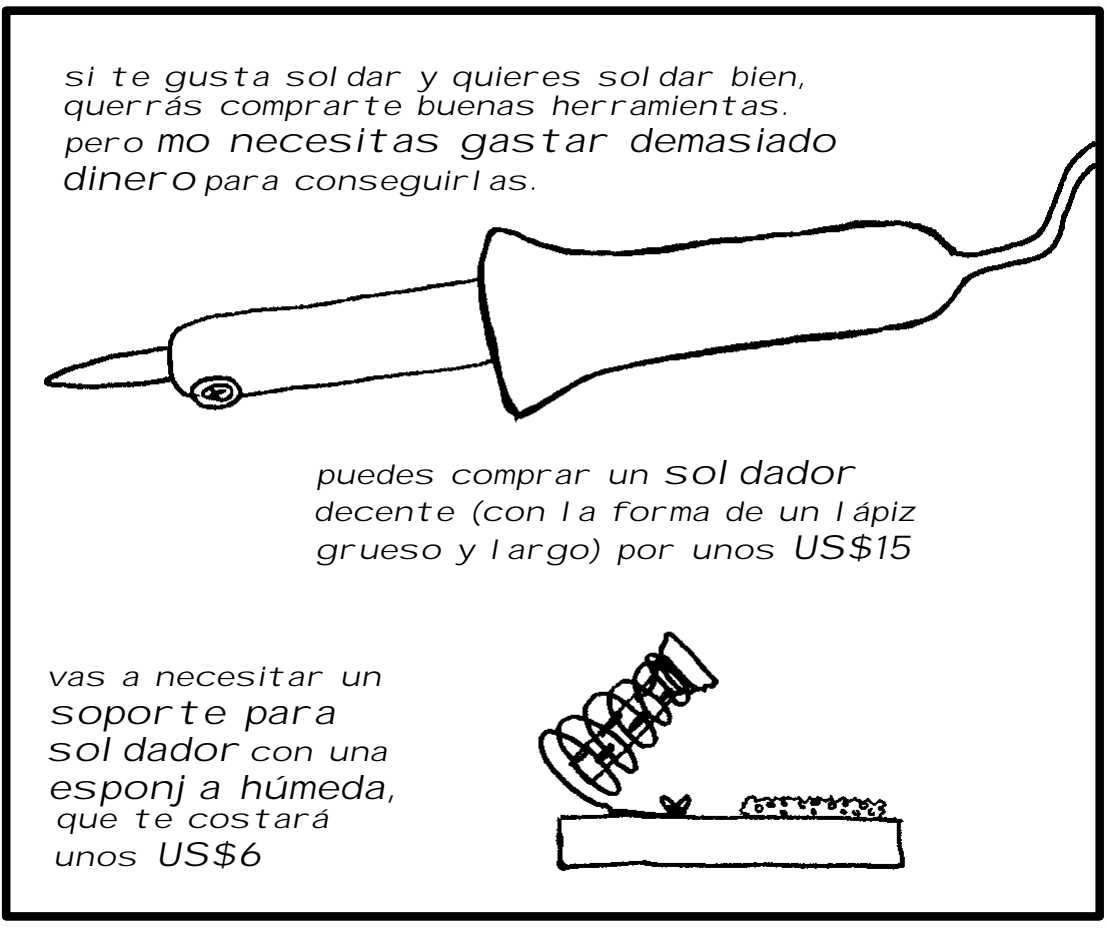
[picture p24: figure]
querrás comprarte buenas herramientas. pero mo necesitas gastar demasiado dinero para conseguirlas.; puedes comprar un soldador decente (con la forma de un lápiz grueso y largo) por unos US$15; vas a necesitar un soporte para soldador con una esponja húmeda, que te costará unos US$6
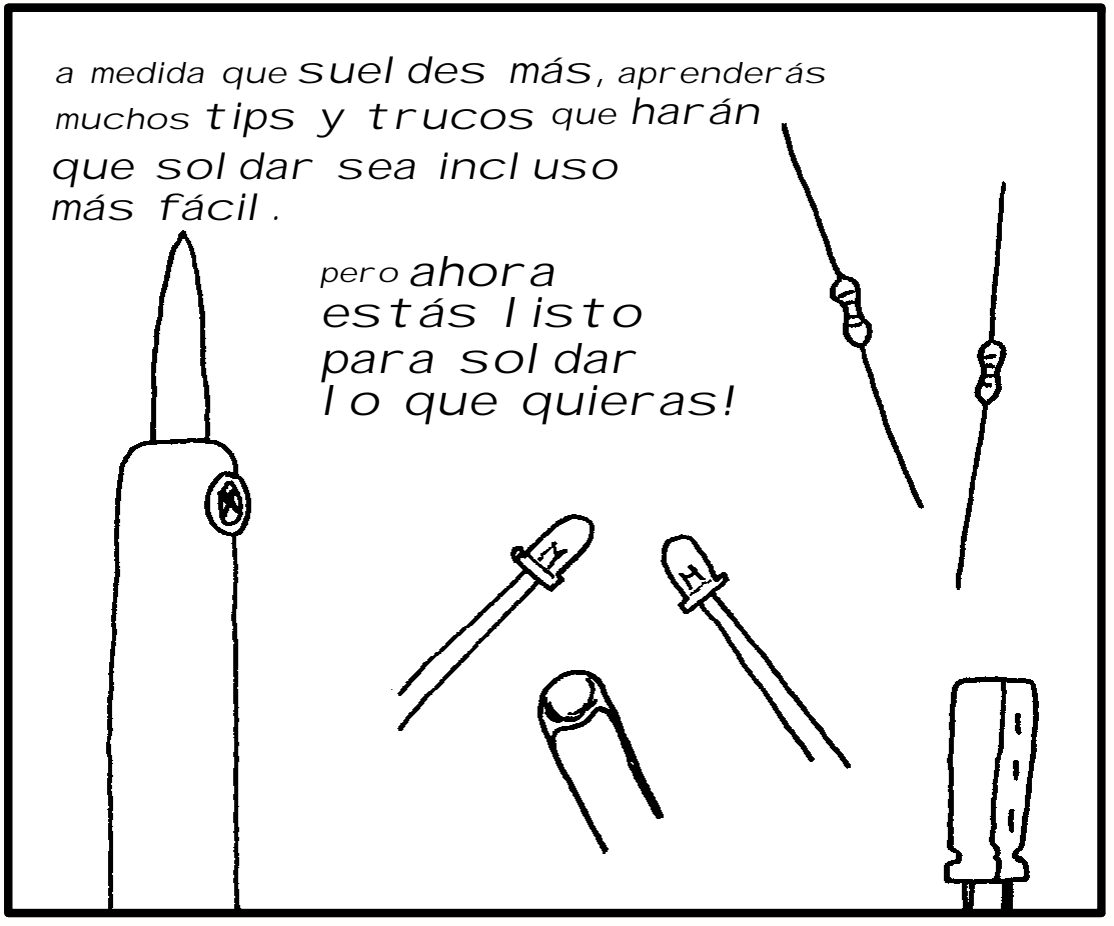
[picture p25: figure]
a medida que sueldes más, aprenderás muchos tips y trucos que harán que soldar sea incluso más fácil.; pero ahora estás listo para soldar lo que quieras!

si te gusta soldar y quieres soldar bien,

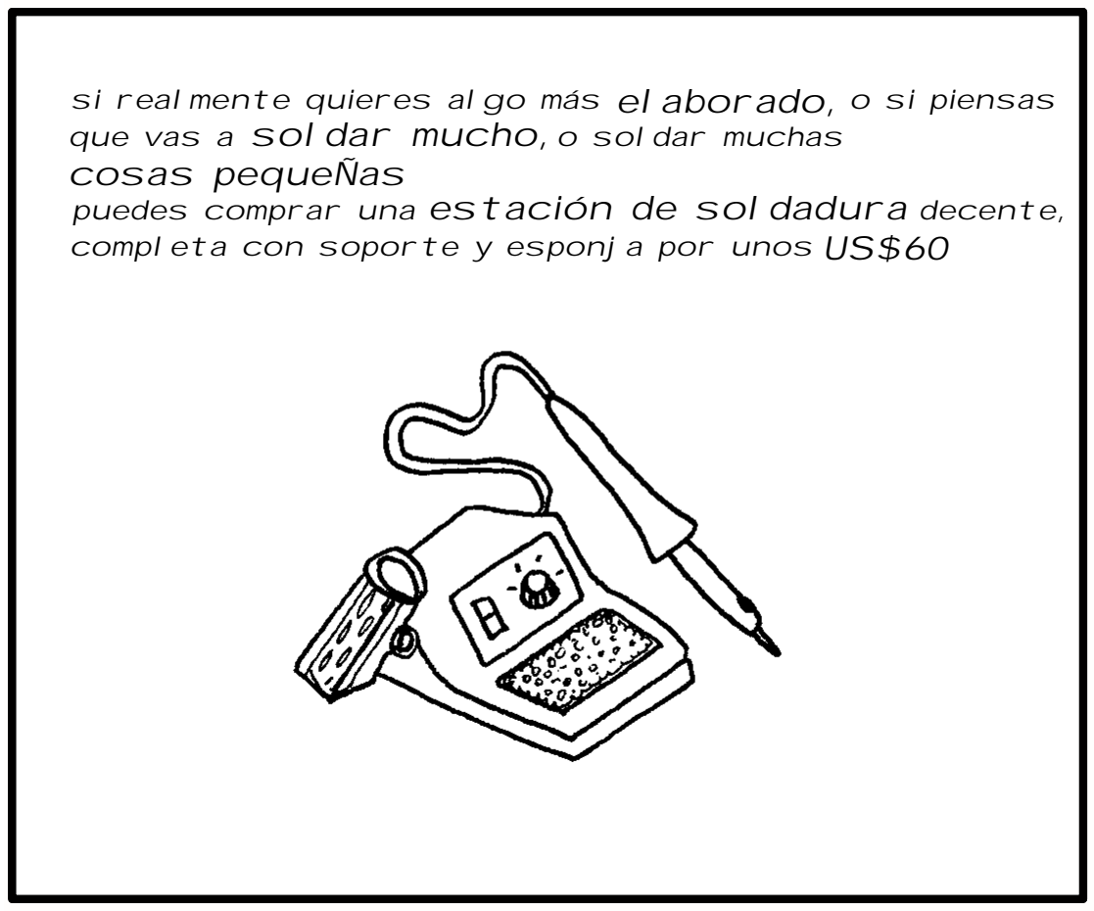
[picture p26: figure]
que vas a soldar mucho, o soldar muchas cosas pequeÑas

si realmente quieres algo más elaborado, o si piensas

puedes comprar una estación de soldadura decente, completa con soporte y esponja por unos US$60

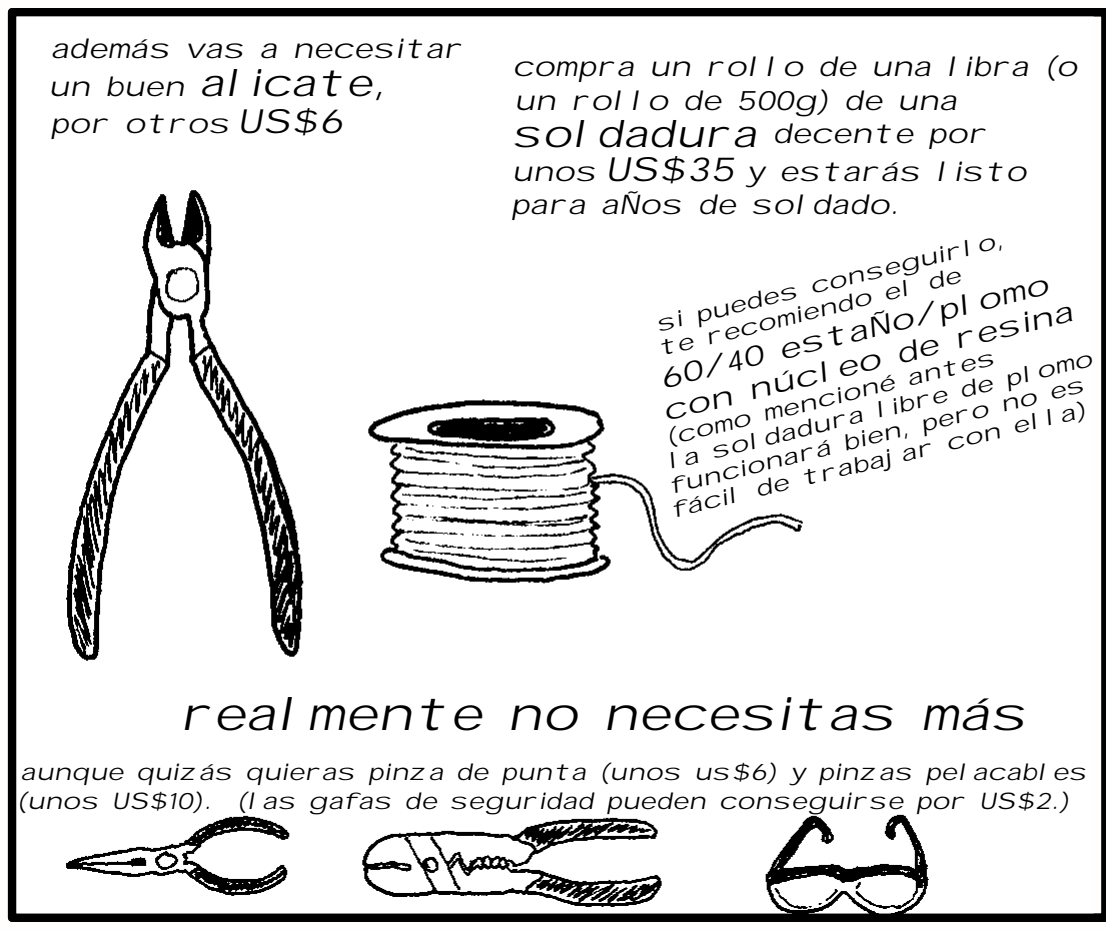
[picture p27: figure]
además vas a necesitar un buen alicate, por otros US$6; compra un rollo de una libra (o un rollo de 500g) de una soldadura unos US$35 y estarás listo para aÑos de soldado. si puedes conseguirlo, te recomiendo el de 60/40 estaÑo/plomo con núcleo de resina; (como mencioné antes la soldadura libre de plomo funcionará bien, pero no es fácil de trabajar con ella); realmente no necesitas más; decente por

aunque quizás quieras pinza de punta (unos us$6) y pinzas pelacables (unos US$10). (las gafas de seguridad pueden conseguirse por US$2.)

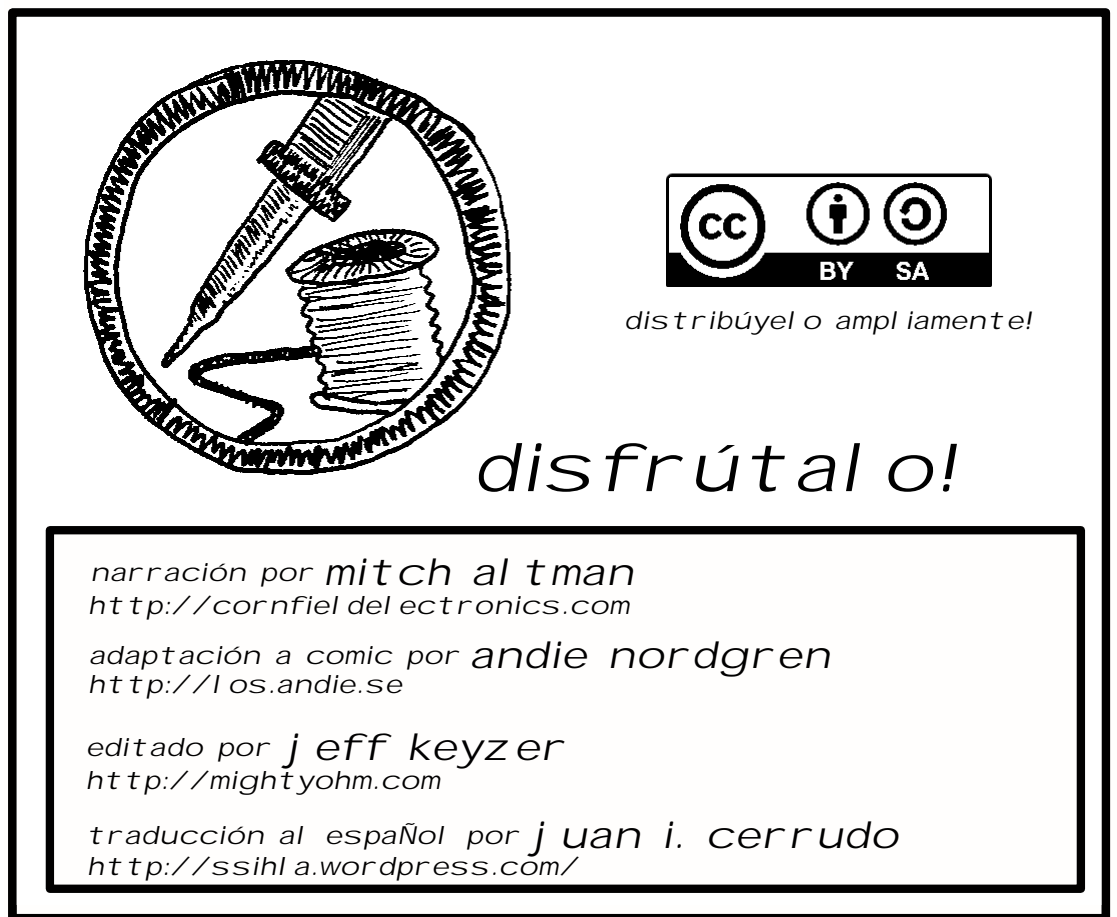
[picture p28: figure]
narración por http://cornfieldelectronics.com; adaptación a comic por http://los.andie.se; editado por http://mightyohm.com; mitch altman; andie nordgren; jeff keyzer; traducción al espaÑol por http://ssihla.wordpress.com/; juan i. cerrudo; distribúyelo ampliamente! disfrútalo!
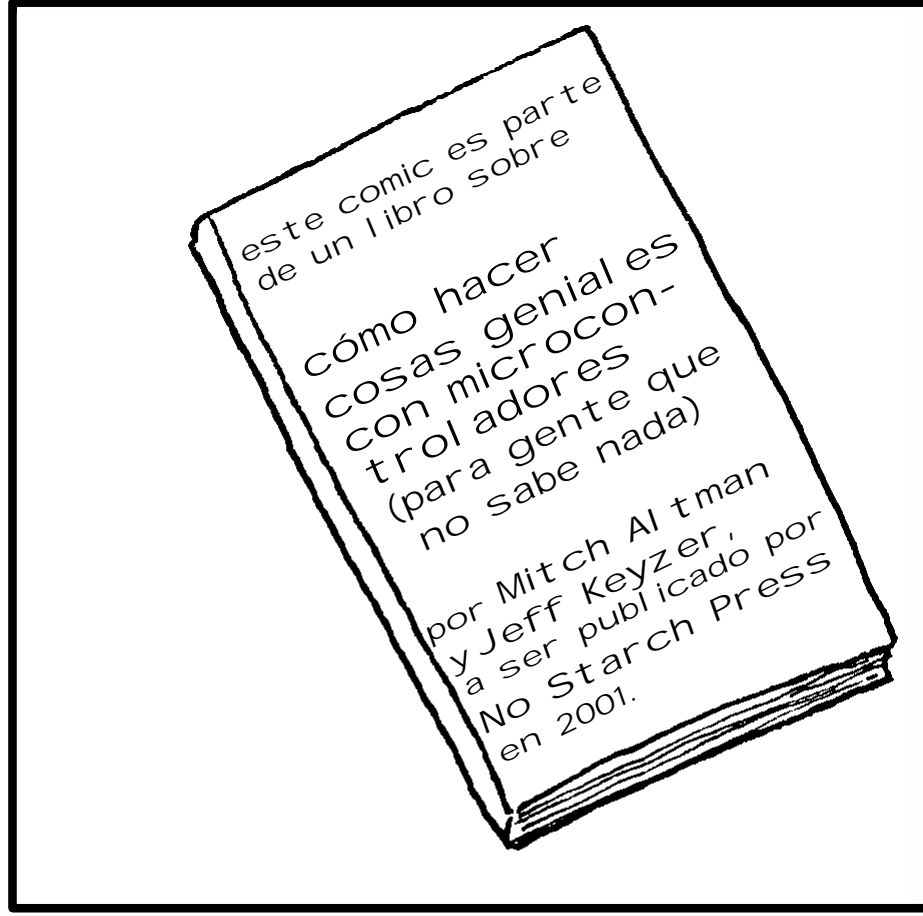
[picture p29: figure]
este comic es parte de un libro sobre; cómo hacer; cosas geniales con microcon- troladores (para gente que no sabe nada) por Mitch Altman y Jeff Keyzer,; a ser publicado por No Starch Press

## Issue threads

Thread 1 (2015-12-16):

Furados metalizados

salvari, 2015-12-16:
As marcas de alineamiento no proxecto orixinal foron interpretadas como vias. Os dous furados cortocircuitan os planos de terra e de alimentación.

salvari, 2015-12-16:
Eliminadas as marcas de alineamiento na PCB

Closed 2015-12-16.

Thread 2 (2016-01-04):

Cambiar os botóns que van a D0 e D1

procastino, 2016-01-04:
Son os portos de lectura de USB, polo que quedan inservibles para ler no ordenador. Desviar dous botóns a pines analóxicos pode ser unha solución.

salvari, 2016-01-25:
Cambiados a AD4 e AD5 respectivamente

Closed 2016-01-25.

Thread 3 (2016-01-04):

Posición de compoñentes

procastino, 2016-01-04:
O potenciómetro de arriba e o led RGB teñen que ir máis para dentro da placa, se tocan co conector USB.

salvari, 2016-01-25:
Cambiada a posición dos potes, hai que medir para comprobar que queda ben.

salvari, 2016-04-03:
Damos este issue por solucionado

Closed 2016-04-03.

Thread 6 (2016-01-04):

Buzzer de 12mm e separación 7.6

procastino, 2016-01-04:
É máis estándar, mellor colocar ese.

salvari, 2016-01-25:
Cambiado

Closed 2016-01-25.

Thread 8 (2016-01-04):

Furados máis pequenos?

procastino, 2016-01-04:
Os leds e resistencias quedan moi folgados nos seus furados (os botóns non), se cadra se poderían poñer os furados un chisco máis pequenos?

salvari, 2016-04-03:
Pois resulta que esta mellora ten moitisima tela, estou a estudiar a documentación de KiCAD pero non parece nada doado.

procastino, 2016-04-03:
Pois déixaos así, tampouco é grave...
El 3/4/2016 6:39 p. m., "Sergio Alvariño" <notifications@github.com>
escribió:

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

salvari, 2016-04-08:
Imos poñer furados de 30 mils de diametro

salvari, 2016-05-14:
Solventado en cc29e5e

Closed 2016-05-14.

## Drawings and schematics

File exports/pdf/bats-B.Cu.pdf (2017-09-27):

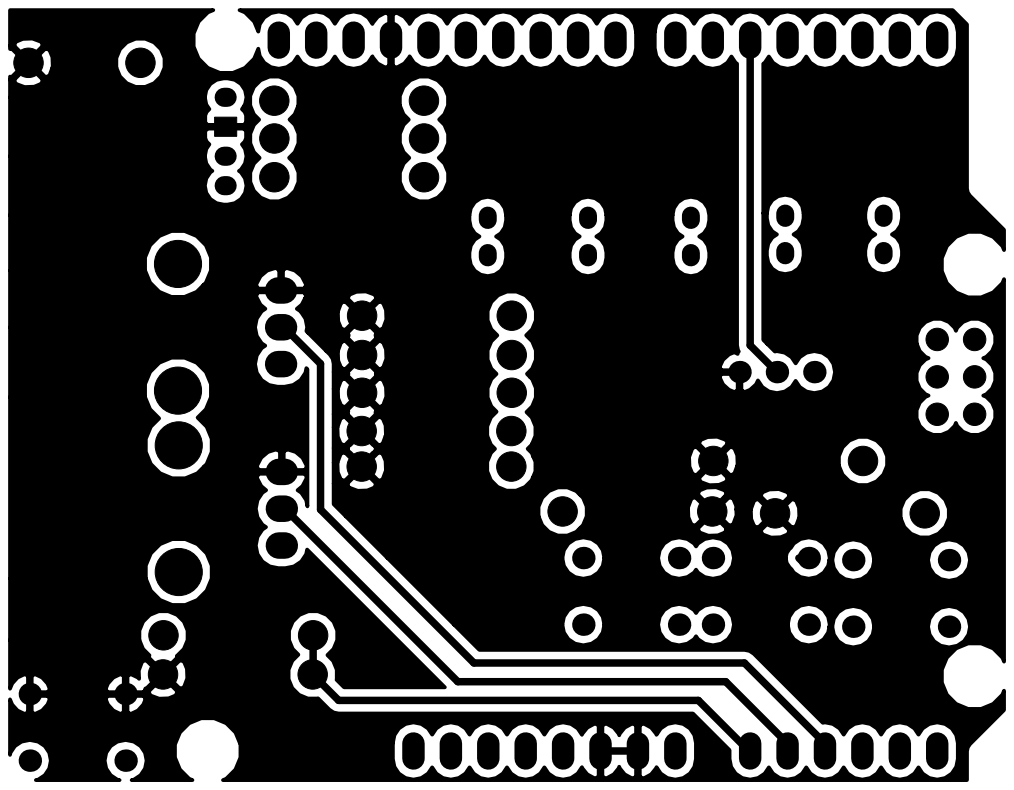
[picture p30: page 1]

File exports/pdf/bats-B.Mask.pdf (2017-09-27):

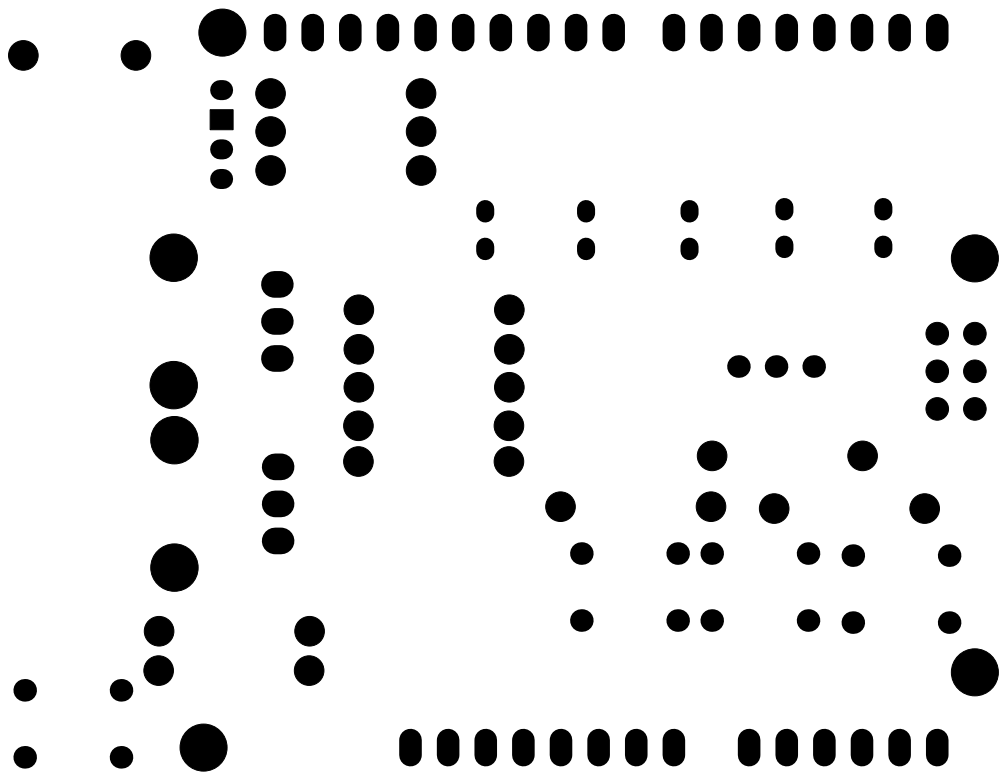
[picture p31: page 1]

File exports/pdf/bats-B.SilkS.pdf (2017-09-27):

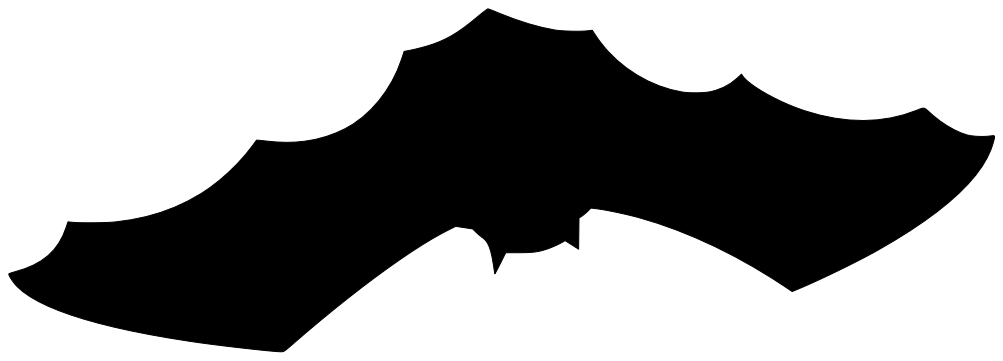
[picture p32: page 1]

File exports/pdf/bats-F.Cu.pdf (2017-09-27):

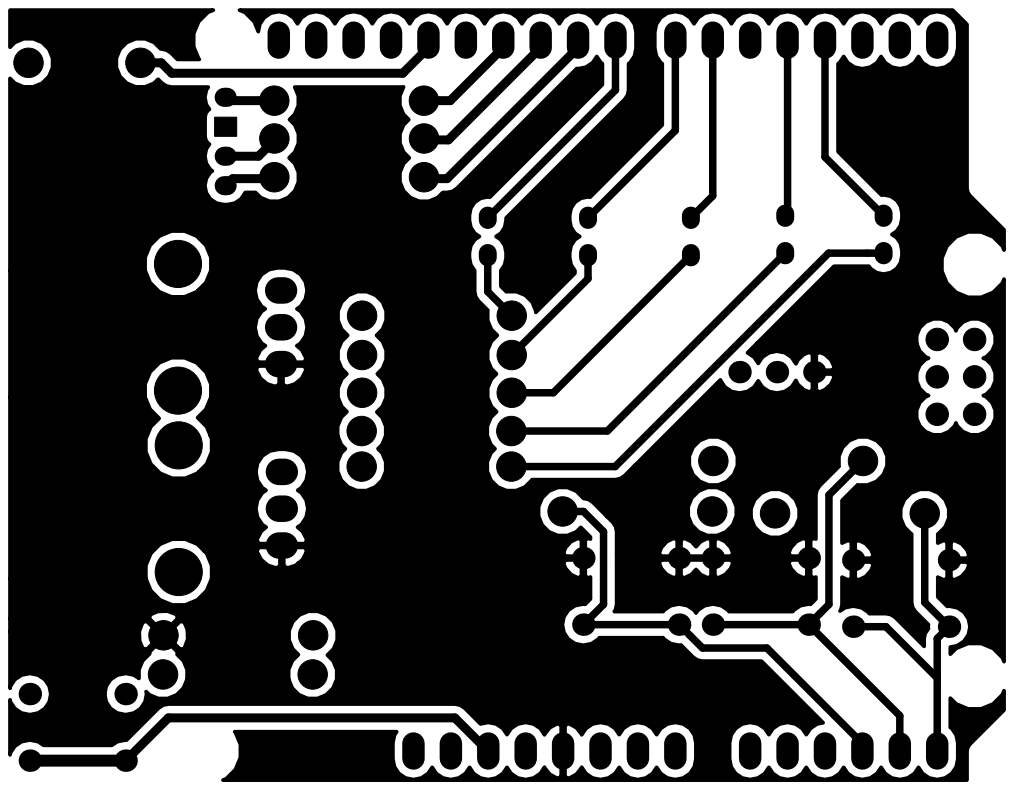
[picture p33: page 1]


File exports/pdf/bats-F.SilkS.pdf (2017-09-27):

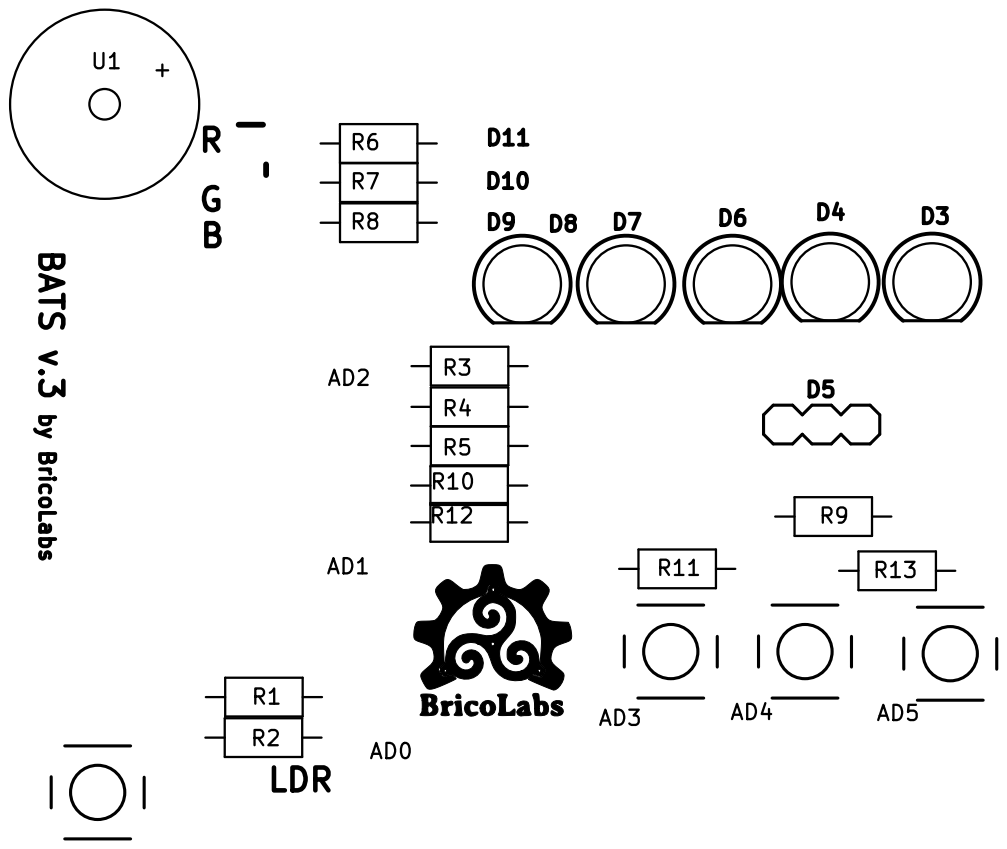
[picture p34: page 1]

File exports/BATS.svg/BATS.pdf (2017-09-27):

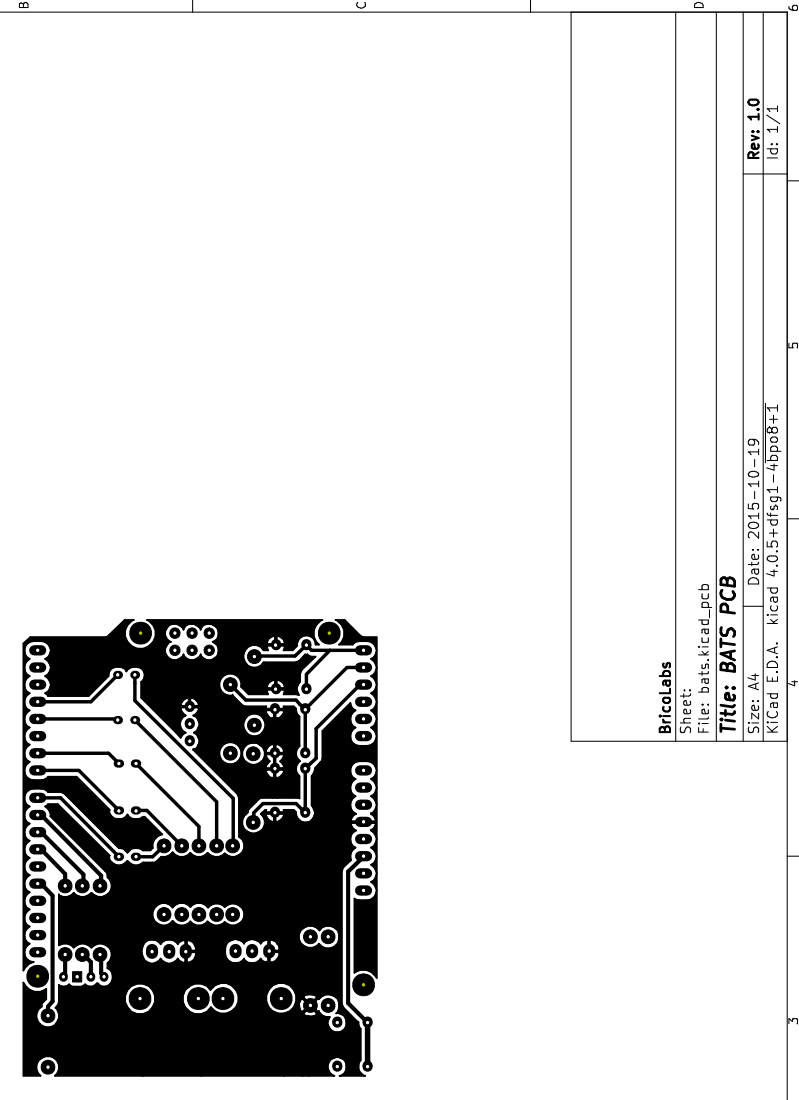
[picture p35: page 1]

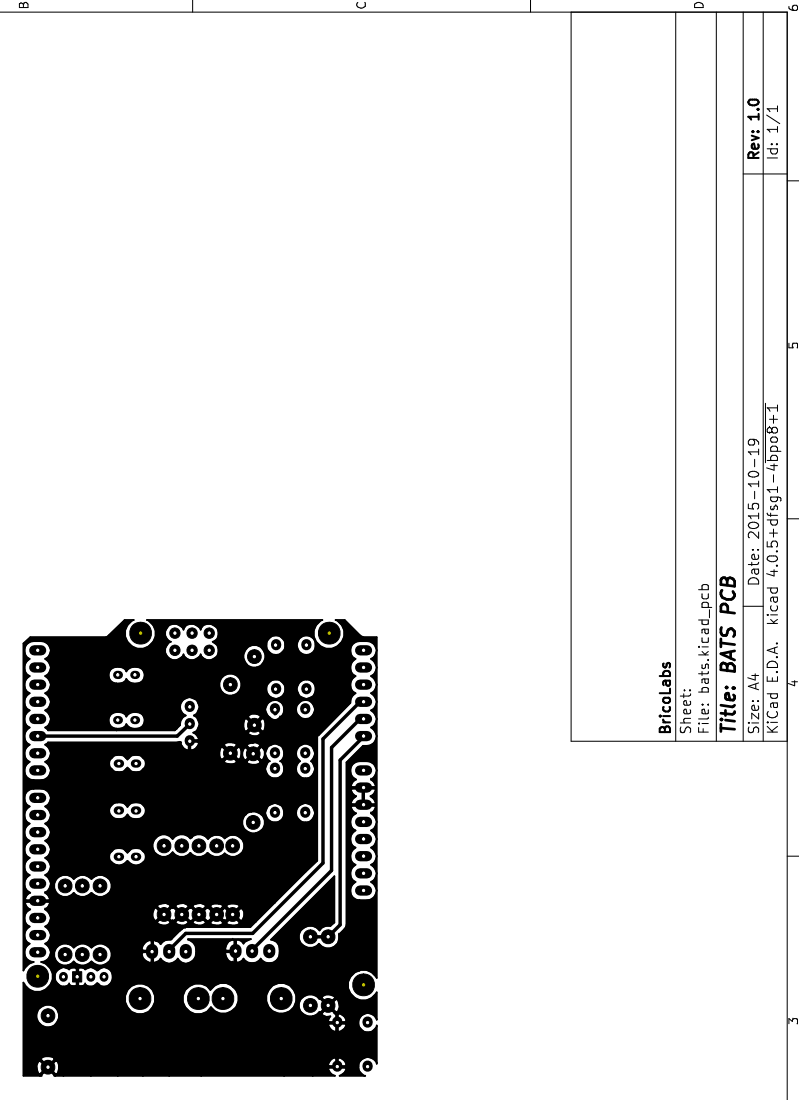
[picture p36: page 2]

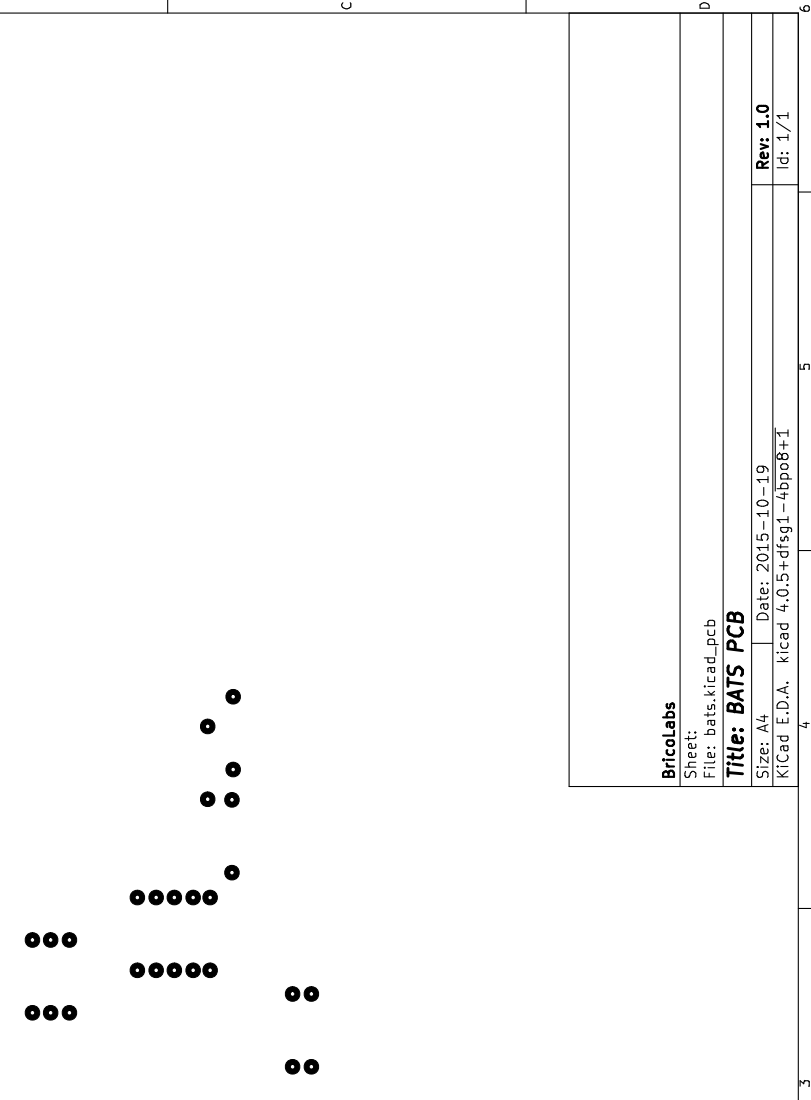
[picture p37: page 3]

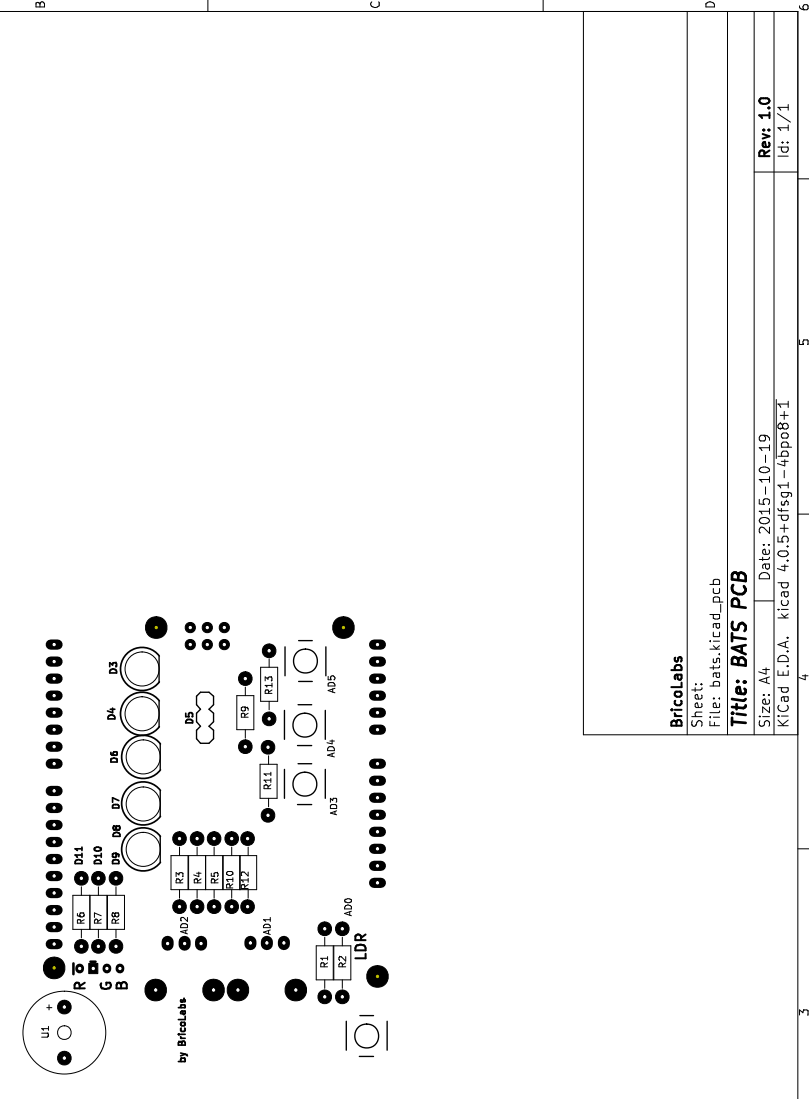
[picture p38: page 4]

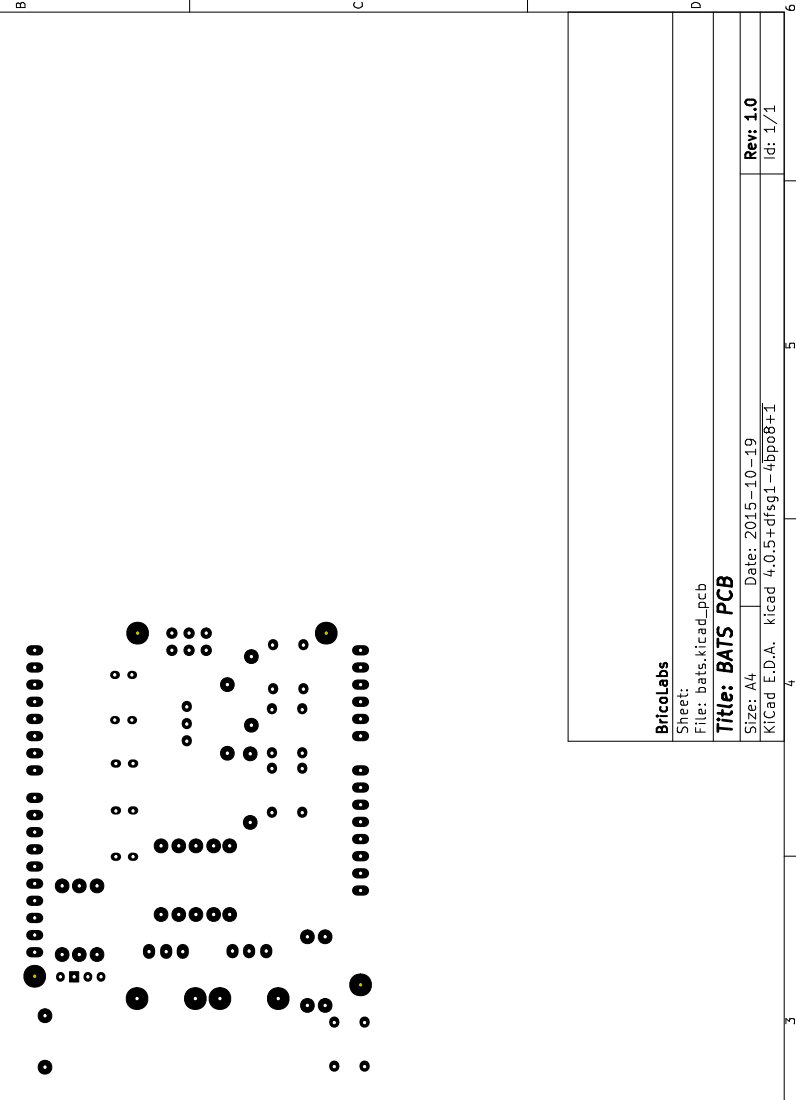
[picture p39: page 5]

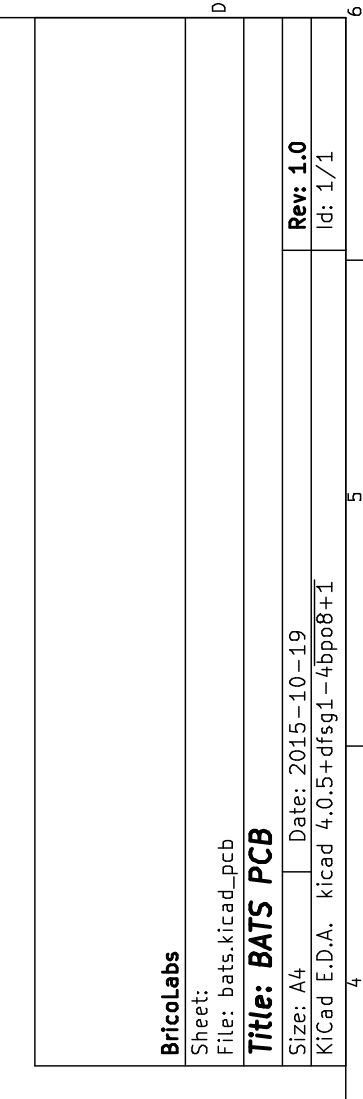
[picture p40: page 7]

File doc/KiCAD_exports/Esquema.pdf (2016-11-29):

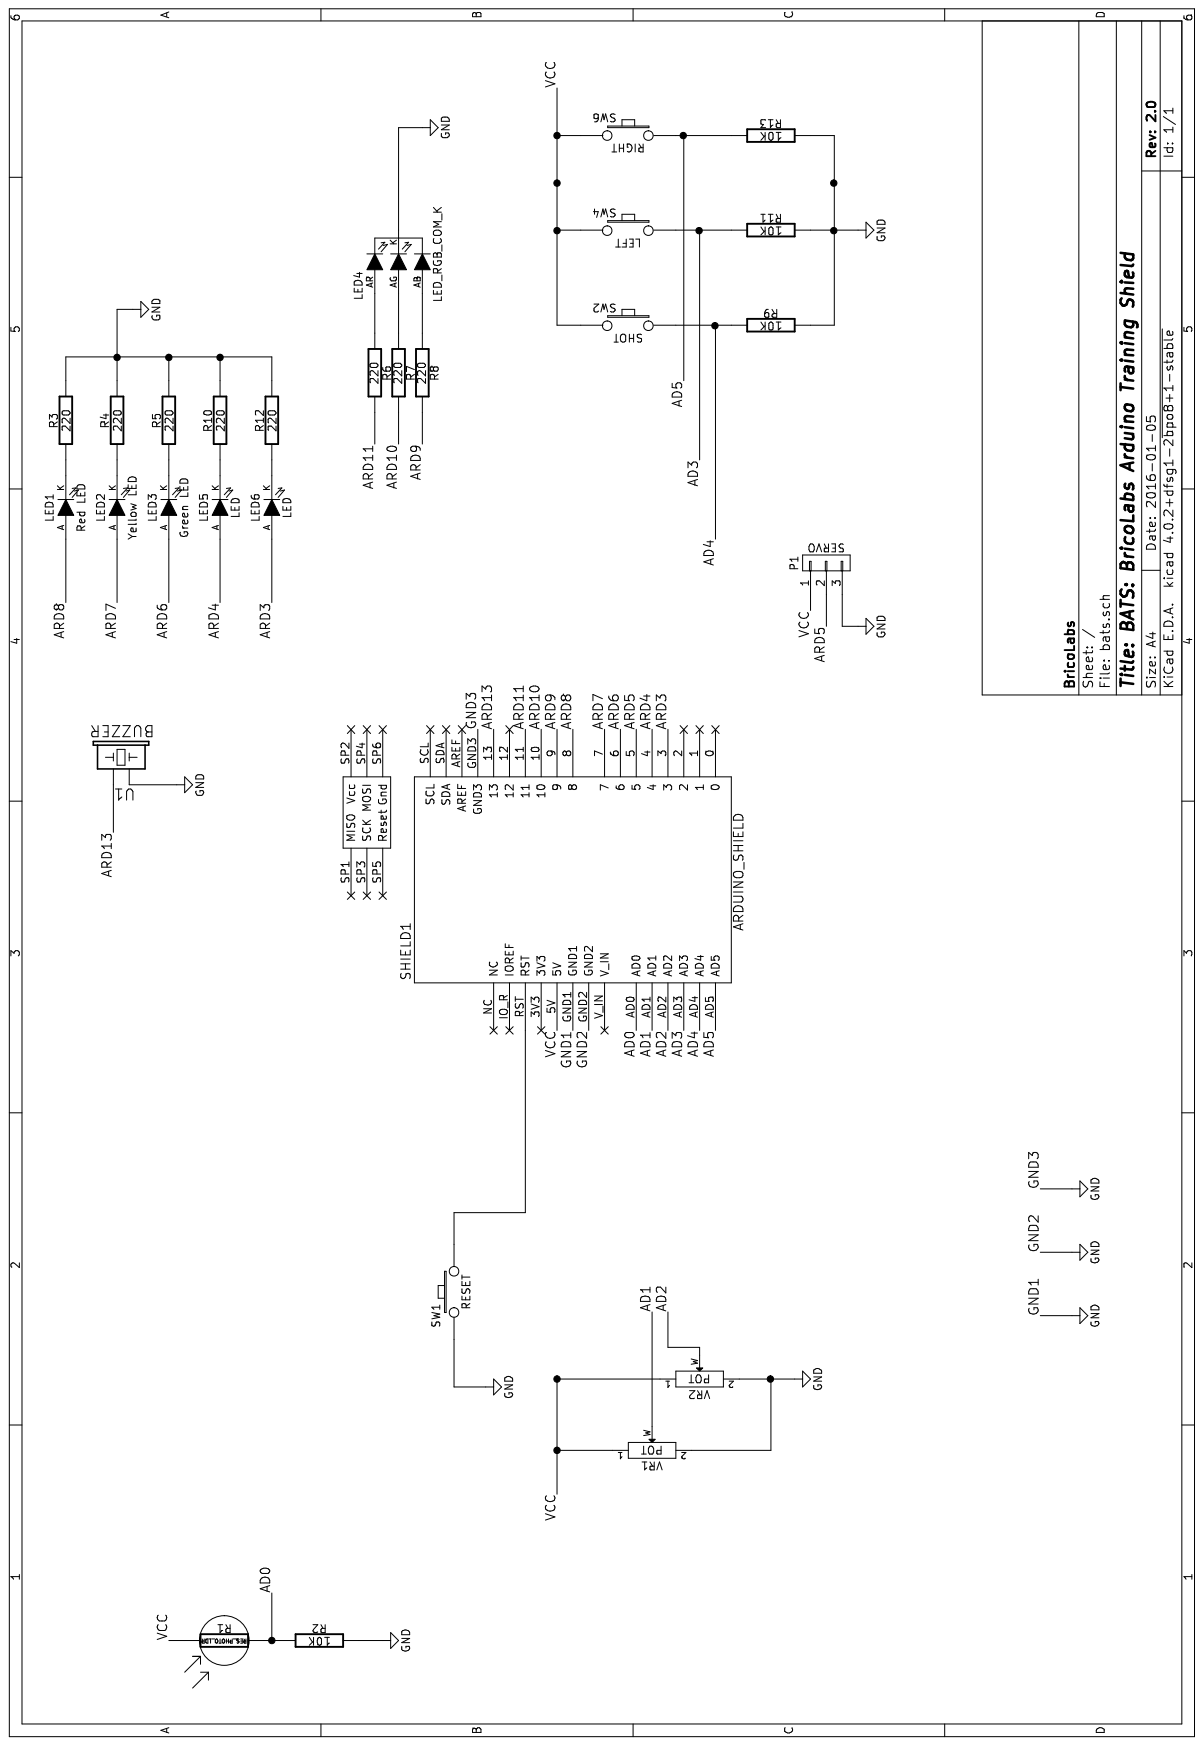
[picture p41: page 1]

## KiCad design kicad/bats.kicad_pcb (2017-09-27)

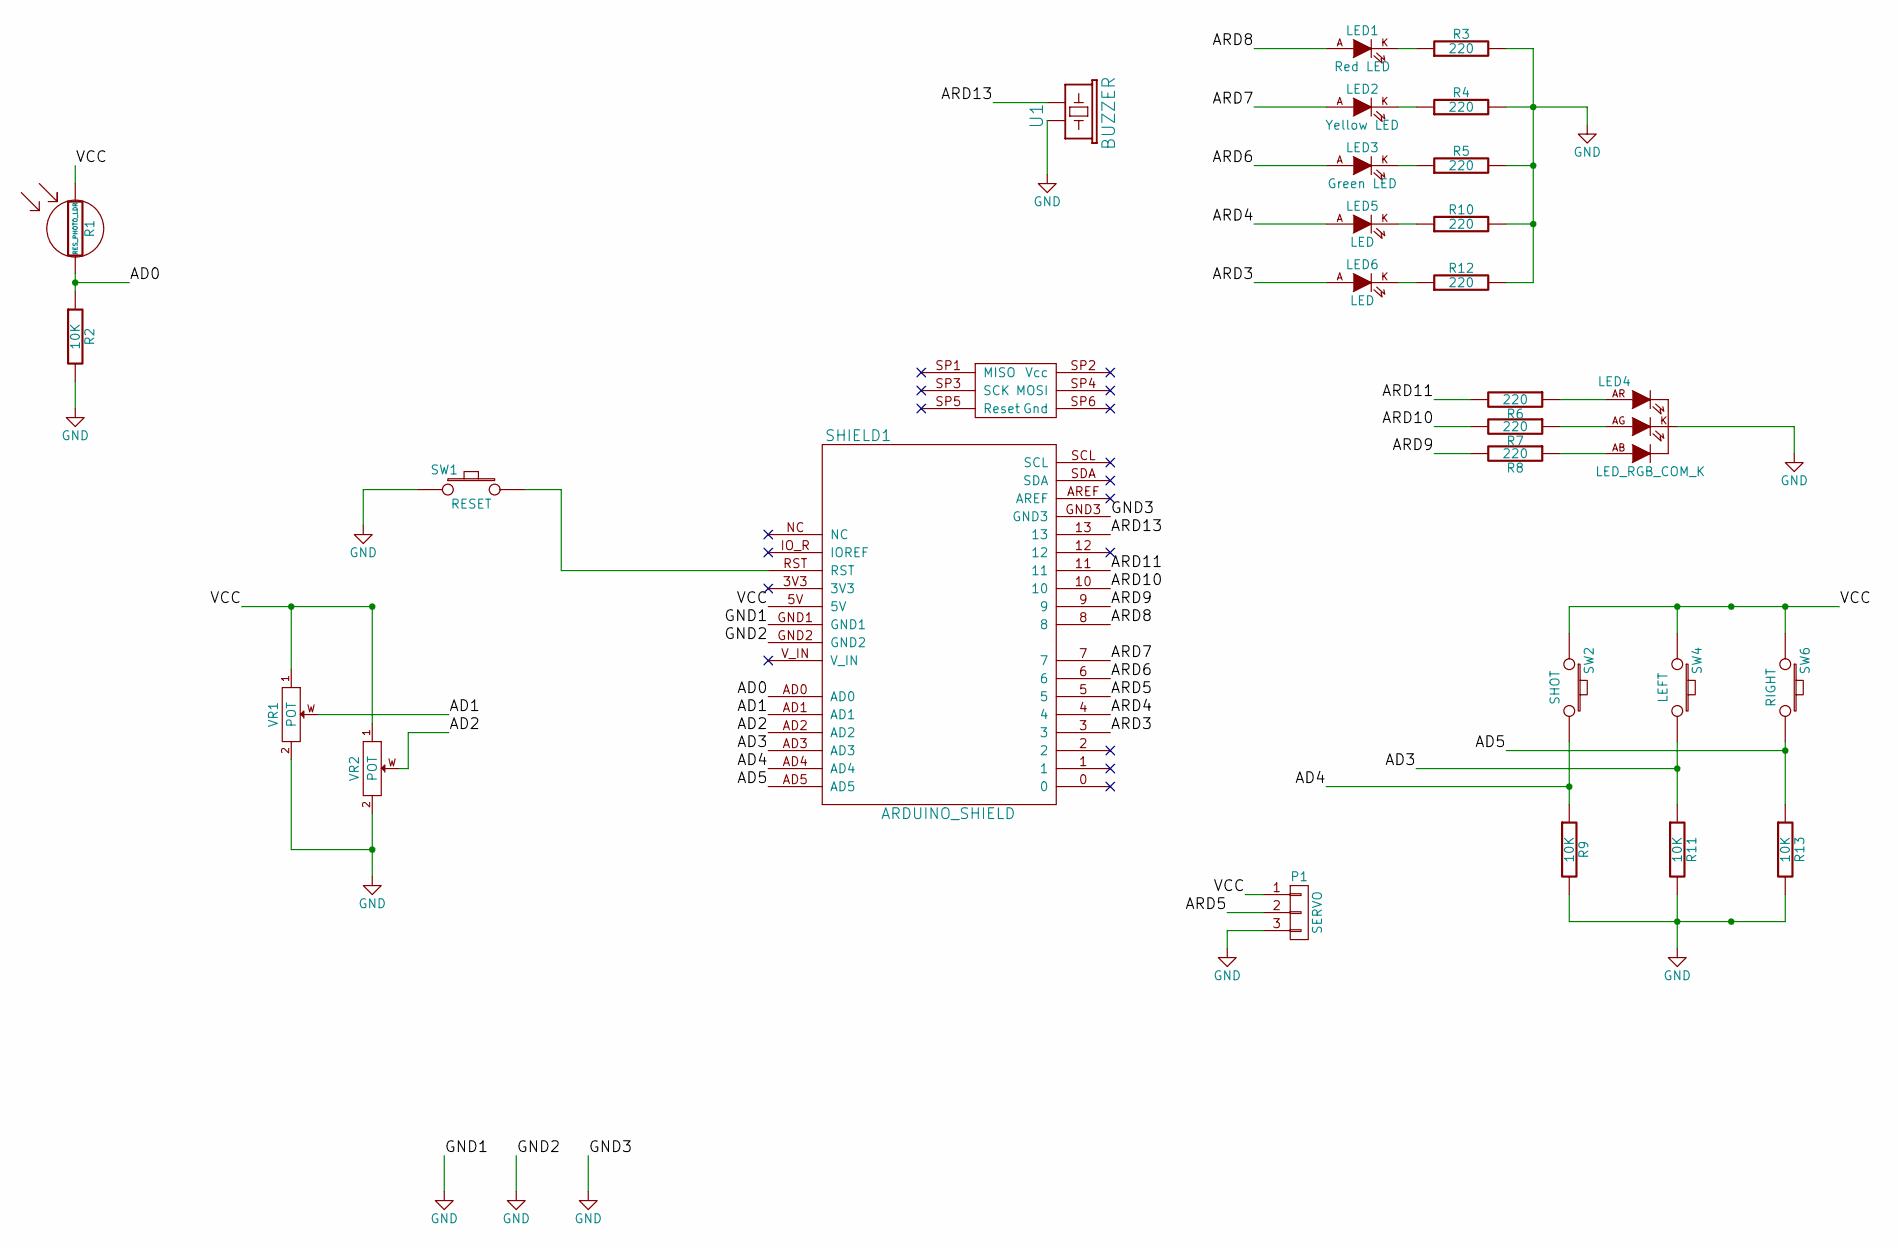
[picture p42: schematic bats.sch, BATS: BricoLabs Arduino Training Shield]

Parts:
LED1: Red LED; LED-5MM_easy_soldering
LED2: Yellow LED; LED-5MM_easy_soldering
LED3: Green LED; LED-5MM_easy_soldering
LED4: LED_RGB_COM_K; LED-RGB-8MM-COM-K-MINIMAL_easy_soldering
LED5, LED6: LED; LED-5MM_easy_soldering
P1: SERVO; 1X03
R1: RES_PHOTO_LDR; Resistor_Horizontal_SmallHole_RM10mm
R2, R9, R11, R13: 10K; Resistor_Horizontal_SmallHole_RM10mm
R3, R4, R5, R6, R7, R8, R10, R12: 220; Resistor_Horizontal_SmallHole_RM10mm
SHIELD1: ARDUINO_SHIELD
SW1: RESET; SW_PUSHBUTTON_PTH
SW2: SHOT; SW_PUSHBUTTON_PTH
SW4: LEFT; SW_PUSHBUTTON_PTH
SW6: RIGHT; SW_PUSHBUTTON_PTH
U1: BUZZER; Buzzer_12x9.5RM7.6
VR1, VR2: POT; POT_RV09_VERT_easySoldering

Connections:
/AD0: R1.2, R2.1, SHIELD1.AD0
/AD1: SHIELD1.AD1, VR1.W
/AD2: SHIELD1.AD2, VR2.W
/AD3: R11.1, SHIELD1.AD3, SW4.2
/AD4: R9.1, SHIELD1.AD4, SW2.2
/AD5: R13.1, SHIELD1.AD5, SW6.2
/ARD3: LED6.A, SHIELD1.3
/ARD4: LED5.A, SHIELD1.4
/ARD5: P1.2, SHIELD1.5
/ARD6: LED3.A, SHIELD1.6
/ARD7: LED2.A, SHIELD1.7
/ARD8: LED1.A, SHIELD1.8
/ARD9: R8.2, SHIELD1.9
/ARD10: R7.2, SHIELD1.10
/ARD11: R6.2, SHIELD1.11
/ARD13: SHIELD1.13, U1.2 (GND)
/VCC: P1.1, R1.1, SHIELD1.5V, SW2.1, SW4.1, SW6.1, VR1.1, VR2.1
GND: LED4.K, P1.3, R2.2, R3.2, R4.2, R5.2, R9.2, R10.2, R11.2, R12.2, R13.2, SHIELD1.GND1, SHIELD1.GND2, SHIELD1.GND3, SW1.1, U1.1 (POS), VR1.2, VR2.2
unnamed: LED1.K, R3.1
unnamed: LED2.K, R4.1
unnamed: LED3.K, R5.1
unnamed: LED4.AB, R8.1
unnamed: LED4.AG, R7.1
unnamed: LED4.AR, R6.1
unnamed: LED5.K, R10.1
unnamed: LED6.K, R12.1
unnamed: SHIELD1.RST, SW1.2

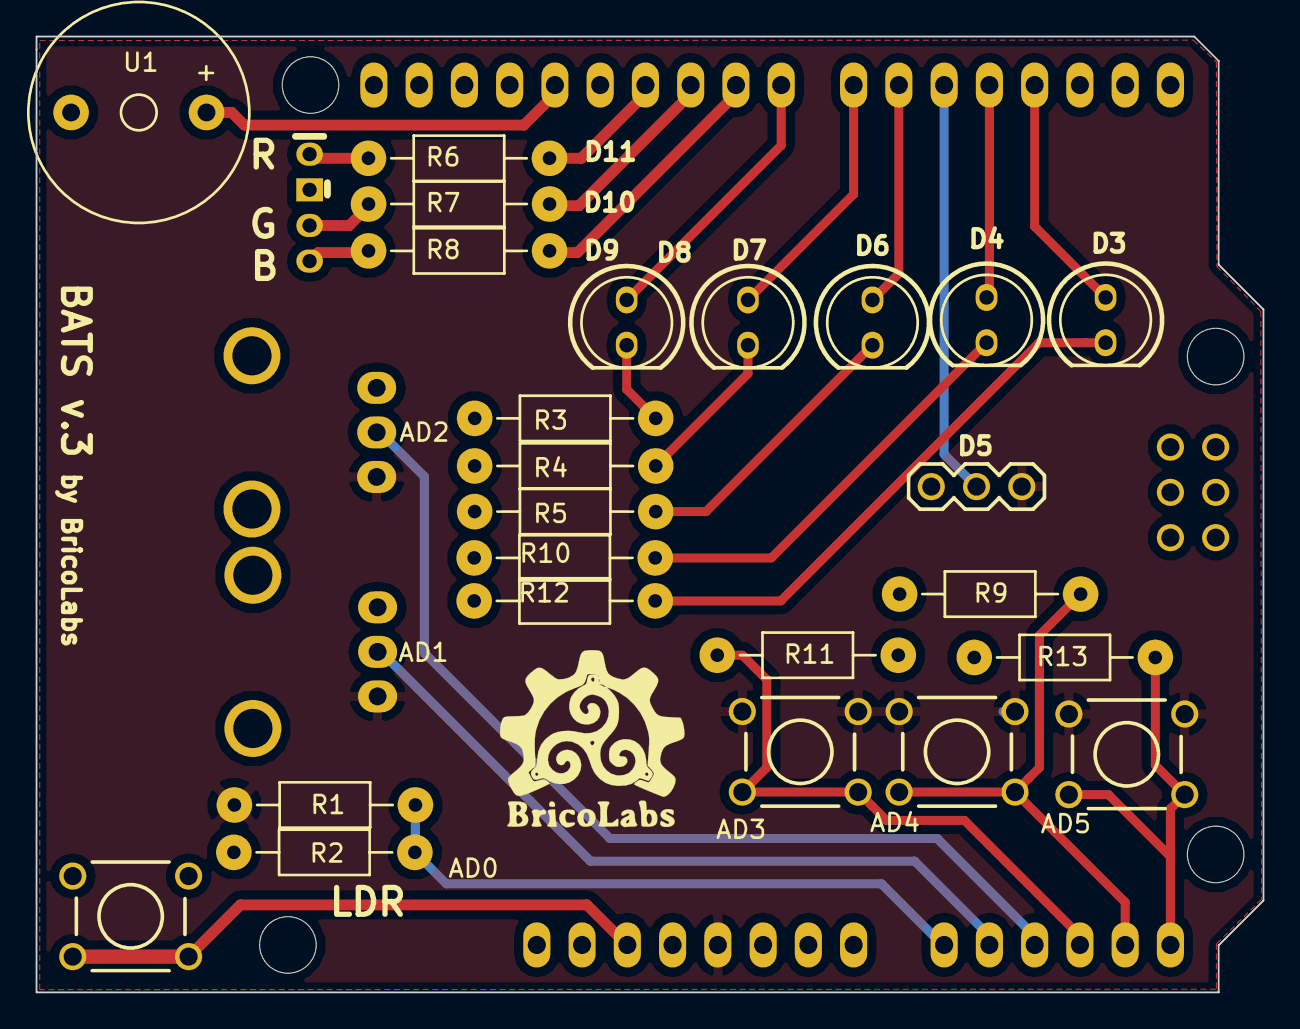
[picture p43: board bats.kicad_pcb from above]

Board: 2 copper layers, 68.9 x 53.6 mm, 28 parts (0 on the bottom side), 27 nets.

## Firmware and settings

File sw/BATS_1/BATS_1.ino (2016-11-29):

/*********************************************************
* Identifica os pins asociados a cada un dos componentes *
*********************************************************/

#define LED1_pin 3
#define LED2_pin 4
#define LED3_pin 6
#define LED4_pin 7
#define LED5_pin 8

#define RGB_R_pin 11
#define RGB_G_pin 10
#define RGB_B_pin 9

#define servo_pin 5

#define zoador_pin 13

#define pulsador1_pin A3
#define pulsador2_pin A4
#define pulsador3_pin A5

#define pot1_pin = A1
#define pot2_pin = A2
#define LDR_pin =  A0

/*********************************************************
* Crea variables auxiliares                              *
*********************************************************/
int auxiliar_LED = 1;
int direccion_LED = 1;

byte brillo_R = 0;
int  incremento_R = 1;
byte brillo_G = 80;
int  incremento_G = 1;
byte brillo_B = 160;
int  incremento_B = 1;

void setup() 
{
  Serial.begin (9600);

// Configura os pins como entradas ou saidas según o caso
  pinMode (LED1_pin, OUTPUT);
  pinMode (LED2_pin, OUTPUT);
  pinMode (LED3_pin, OUTPUT);
  pinMode (LED4_pin, OUTPUT);
  pinMode (LED5_pin, OUTPUT);

  pinMode (RGB_R_pin, OUTPUT);
  pinMode (RGB_G_pin, OUTPUT);
  pinMode (RGB_B_pin, OUTPUT);

  pinMode (servo_pin, OUTPUT);
  pinMode (zoador_pin, OUTPUT);

  pinMode (pulsador1_pin, INPUT);
  pinMode (pulsador2_pin, INPUT);
  pinMode (pulsador3_pin, INPUT);
}

void loop() 
{
// Apaga os LEDs 1 a 5 
  digitalWrite (LED1_pin, LOW);
  digitalWrite (LED2_pin, LOW);
  digitalWrite (LED3_pin, LOW);
  digitalWrite (LED4_pin, LOW);
  digitalWrite (LED5_pin, LOW);

// Se a variable auxiliar está entre 1 e 5
  if (auxiliar_LED<=5)
  {
    // Acende o LED que corresponde
    if (auxiliar_LED==1) digitalWrite (LED1_pin, HIGH);
    if (auxiliar_LED==2) digitalWrite (LED2_pin, HIGH);
    if (auxiliar_LED==3) digitalWrite (LED3_pin, HIGH);
    if (auxiliar_LED==4) digitalWrite (LED4_pin, HIGH);
    if (auxiliar_LED==5) digitalWrite (LED5_pin, HIGH);

    // E espera un pouco antes do seguinte paso
    delay (150);
  }
  
// Se a variable auxiliar é 6 activa o zoador cunha seuencia
// de frecuencias entre os 400 e os 2000 Hz
  if (auxiliar_LED==6)
  {
    int frecuencia = 50;
    while (frecuencia < 4000)
    {
      tone (zoador_pin, frecuencia);
      frecuencia += 500;
      delay (55);
    }
    noTone(zoador_pin);
  }

// Se a variable auxiliar é 7 cambia o color do LED
// RGB durante 2 segundos
  if (auxiliar_LED==7)
  {
    int pasos = 200;

    while (pasos > 0)
    {
      analogWrite (RGB_R_pin, brillo_R);
        brillo_R += incremento_R;
          if (brillo_R >= 255) incremento_R = -10;
          if (brillo_R <=   10) incremento_R = +10;

      analogWrite (RGB_G_pin, brillo_G);
        brillo_G += incremento_G;
          if (brillo_G >= 255) incremento_G = -10;
          if (brillo_G <=  10) incremento_G = +10;

      analogWrite (RGB_B_pin, brillo_B);
        brillo_B += incremento_B;
          if (brillo_B >= 255) incremento_B = -10;
          if (brillo_B <=  10) incremento_B = +10;
      
      pasos --;
      delay (1);

      Serial.print ("R: ");
      Serial.print (brillo_R);
      Serial.print ("\tG: ");
      Serial.print (brillo_G);
      Serial.print ("\tB: ");
      Serial.print (brillo_B);
      Serial.println();
      
    }
  }

// Incrementa a variable auxiliar
  auxiliar_LED +=direccion_LED;
  if (auxiliar_LED >= 8) 
  {
    auxiliar_LED = 5;
    direccion_LED = -1;
  }
  if (auxiliar_LED <= 1) direccion_LED = +1;

}

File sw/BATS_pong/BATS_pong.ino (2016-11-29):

/*********************************************************
* Identifica os pins asociados a cada un dos componentes *
*********************************************************/

#define LED1_pin 3
#define LED2_pin 4
#define LED3_pin 6
#define LED4_pin 7
#define LED5_pin 8

#define RGB_R_pin 11
#define RGB_G_pin 10
#define RGB_B_pin 9

#define servo_pin 5

#define zoador_pin 13

#define pulsador1_pin A3
#define pulsador2_pin A4
#define pulsador3_pin A5

#define pot1_pin = A1
#define pot2_pin = A2
#define LDR_pin =  A0

/*********************************************************
* Crea variables auxiliares                              *
*********************************************************/
boolean enMarcha = false;
boolean noPulsado = false;
int direccion = 1;
int posicion = 3;
int servo = 90;
int espera;
int dificultad = 12000;

void setup() 
{
  Serial.begin (9600);

// Configura os pins como entradas ou saidas según o caso
  pinMode (LED1_pin, OUTPUT);
  pinMode (LED2_pin, OUTPUT);
  pinMode (LED3_pin, OUTPUT);
  pinMode (LED4_pin, OUTPUT);
  pinMode (LED5_pin, OUTPUT);

  pinMode (RGB_R_pin, OUTPUT);
  pinMode (RGB_G_pin, OUTPUT);
  pinMode (RGB_B_pin, OUTPUT);

  pinMode (servo_pin, OUTPUT);
  pinMode (zoador_pin, OUTPUT);

  pinMode (pulsador1_pin, INPUT);
  pinMode (pulsador2_pin, INPUT);
  pinMode (pulsador3_pin, INPUT);
}


void loop() 
{
  
  if (enMarcha == true)
  {
    if (espera < dificultad)
    {
      if (!digitalRead (pulsador1_pin) and !digitalRead (pulsador3_pin)) noPulsado = true;
    
      espera ++;
      if (posicion == 1) 
      {
        if (noPulsado and (digitalRead (pulsador3_pin)))
        {
          direccion =  1;
          espera = dificultad + 1;
        }
      }

      if (posicion == 5) 
      {
        if (noPulsado and (digitalRead (pulsador1_pin)))
        {
          direccion =  -1;
          espera = dificultad +1;
        }
      }
     }
    else
    {
      espera = 0;

      if (digitalRead (pulsador1_pin) or digitalRead (pulsador3_pin)) noPulsado = false;

      if (posicion >  5) 
      {
        tone (zoador_pin, 2200); delay ( 50); noTone (zoador_pin); delay (20);
        tone (zoador_pin, 1100); delay (100); noTone (zoador_pin); delay (20);
        tone (zoador_pin, 440); delay ( 75); noTone (zoador_pin); delay (20);

        direccion = 0;
        enMarcha = false;
        espera = 0;
      }

      if (posicion <  1) 
      {
        tone (zoador_pin, 440); delay ( 70); noTone (zoador_pin); delay (20);
        tone (zoador_pin, 1100); delay (100); noTone (zoador_pin); delay (20);
        tone (zoador_pin, 2200); delay ( 50); noTone (zoador_pin); delay (20);

        direccion = 0;
        enMarcha = false;
        espera = 0;
      }
 
      posicion += direccion;
    }
  }

  else 
  {
    posicion = 0;
    
    espera ++;
    if (espera < 1500)
    {
      digitalWrite (LED1_pin, HIGH);
      digitalWrite (LED2_pin, HIGH);
      digitalWrite (LED3_pin, HIGH);
      digitalWrite (LED4_pin, HIGH);
      digitalWrite (LED5_pin, HIGH);
    }
    
    else if (espera > 15000) espera = 0;

    if (digitalRead (pulsador2_pin))
    {
      posicion = 3;
      dificultad = dificultad * .85;
      direccion = 1;
      if (random (2) > 0) direccion = -1;
      digitalWrite (LED3_pin, HIGH);
      delay (1000);      
      enMarcha = true;
    }
  }

// Apaga os LEDs 1 a 5 
  digitalWrite (LED1_pin, LOW);
  digitalWrite (LED2_pin, LOW);
  digitalWrite (LED3_pin, LOW);
  digitalWrite (LED4_pin, LOW);
  digitalWrite (LED5_pin, LOW);

  if (posicion == 1) digitalWrite (LED1_pin, HIGH);
  if (posicion == 2) digitalWrite (LED2_pin, HIGH);
  if (posicion == 3) digitalWrite (LED3_pin, HIGH);
  if (posicion == 4) digitalWrite (LED4_pin, HIGH);
  if (posicion == 5) digitalWrite (LED5_pin, HIGH);
}

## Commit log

2015-06-21 Engadida a biblioteca de Freetronics
    [sandbox_shield.kicad_pcb, sandbox_shield.sch]
2015-06-21 Primeiros pasos có esquema * Engadido o shield arduino * Engadidos tres leds coas suas resistencias * Asignados footprints a todos os compoñentes
2015-06-22 Engadido o LDR Algún cambio na documentación
    [sandbox_shield.sch]
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2015-06-23 Creado o novo proxecto kicad con nome correcto: bats
    Resulta que cambiar o nome do proxecto en KiCAD non é nada doado.
    [bats.kicad_pcb, bats.sch]
2015-06-23 Borrados os restantes ficheiros con nome sandboxShield Engadido algún compoñente mais
    [sandbox_shield.kicad_pcb, sandbox_shield.sch]
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2015-06-24 Mais avances no esquema do circuito
    [bats.sch]
2015-06-24 Engadido o esquema en formato pdf
    [bats.sch]
2015-06-25 Cambios no ficheiro de documentación.
    Cambiado a orden de execución dos programas no checklist
2015-06-25 A PCB empeza a coller forma.
    [bats.kicad_pcb, bats.sch]
2015-09-04 Mais cambios non especificados, facemos o commit antes de borrar o conxunto de pulsadores analóxicos.
    [bats.sch]
2015-09-05 Cambiado o footprint dos potes. Todos os compoñentes situados na placa Mínimos cambios na documentación (engadida breve explicación dos submódulos de git)
    [bats.kicad_pcb, bats.sch]
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2015-09-05 Primeira versión enrutada, ainda precisa duas caras, hai que pensar un pouco mais.
    [bats.kicad_pcb]
2015-09-06 Engadida unha "KiCAD cheat sheet", una chuleta para KiCAD, non rematada
    Engadida unha segunda versión da placa intentando deixar todo nunha
    cara.
    [bats.sch, bats_less.kicad_pcb]
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2015-10-15 Un commit intermedio facendo probas
    [bats.kicad_pcb, bats.sch]
2015-10-15 Recolocados casi todos os compoñentes Simplificado esquema Aumentado o ancho de pistas
    [bats.kicad_pcb, bats.sch]
2015-10-16 Casi rematado
    [bats.kicad_pcb, bats.sch]
2015-10-19 Colocadas as esquiñas da zona de recheo de masa.
    [bats.kicad_pcb]
2015-10-20 Engadida area de recheo no fronte da placa
    [bats.kicad_pcb, bats.sch]
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2015-11-14 Correxida a forma da placa Correxida a posición do botón de reset Correxida a posición do nome da placa
    [bats.kicad_pcb]
2015-11-14 Engadidos Silks de probas Limpeza de directorios Exportados Gerber
    [bats-B.Cu.gbr, bats-B.Mask.gbr, bats-B.SilkS.gbr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]
2015-11-14 Cambios menores na placa
    [bats.kicad_pcb]
2015-11-14 Exportados os Gerber files, preparado un zip cós Gerber para facer un pedido.
    [bats-B.Cu.gbl, bats-B.Mask.gbs, bats-B.SilkS.gbo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]
2015-11-15 Cambiado ficheiro zip cos grb para o pedido a DirtyPCB Pedido feito
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2015-12-15 Borrados os simbolos de alineamiento que se transformaron en vias en dirtypcb
    Algo mais de documentación.
    [bats.kicad_pcb]
2016-01-05 Cambios masivos:
    Issue 01 - Cambiados os botóns de D0 e D1 a AD4 e AD5 respectivamente.
    Issue 02 - Cambiada a posición dos dous potes e do led rgb cara ao
    interior da placa.
    Issue 05 - Serigrafiados os pines de control
    Issue 06 - Sustituido o buzzer
    Además simplifícase todo o enrutado da placa.
    [bats.kicad_pcb, bats.sch]
2016-01-25 Engadimos algunha serigrafía mais. Todo semella estar listo para a segunda versión.
    [bats.kicad_pcb, bats.sch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]
2016-01-26 Exported new gerber files
    [bats-B.Cu.gbl, bats-B.Cu.gbr, bats-B.Mask.gbr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]
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2016-04-03 Cambiadas algunhas pistas para reconectar as areas positivas do frontal
    [bats-B.Cu.gbr, bats-B.Mask.gbr, bats-B.SilkS.gbr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]
2016-04-03 Correxida a posición do polo positivo na silk do zoador.
    [bats.kicad_pcb]
2016-04-03 Cambiada a posición da rotulación do polo positivo no zoador.
    [bats-B.Cu.gbr, bats-B.Mask.gbr, bats-B.SilkS.gbr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]
2016-04-03 Engadida unha conexión extra na area positiva.
    [bats-B.Cu.gbl, bats-B.Mask.gbs, bats-B.SilkS.gbo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]
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2016-04-30 Cambiadas as pegadas das resistencias a furados mais pequenos.
    [bats.kicad_pcb, bats.sch]
2016-05-14 Cambiados os LED a LED de 5mm no esquema e mais no ficheiro net
    [bats.sch]
2016-05-14 - Correxida a posición da rotulacion de todas as resistencias - Cambiada o tamaño dos leds a 5 mm, cambia tamén a sua posición, pecha o issue #4 - Cambiada a posición de resistencias R3, R4 e R5 e ma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
    [bats.kicad_pcb]
2016-05-14 Versión 2.1, non é outra cousa que a versión 2.0 cos erros correxidos
    [bats-B.Cu.gbl, bats-B.Cu.gbr, bats-B.Mask.gbr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]
2016-05-23 Primeira versión con tres botóns. Ten pistas redundantes e hai que cambiar os pines dos botóns.
    [bats.kicad_pcb, bats.sch]
2016-05-23 Amañados os terminais dos botóns Compre rotar os botóns para simplificar as pistas
    [bats.kicad_pcb, bats.sch]
2016-05-23 TEN UN FALLO, non usar sen cambiar o botón en D1
    [bats.kicad_pcb]
2016-05-24 Primeira versión completa con tres botóns. Os ficheiros gerber non son válidos. - Hai que revisar a conexión do servo - Hai que alinear ben os tres botóns
    [bats.kicad_pcb, bats.sch]
2016-06-21 Todo listo para facer pedido a dirtypcb
    [bats-B.Cu.gbl, bats-B.Cu.gbr, bats-B.Mask.gbr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]
2016-11-25 Engadida a documentación para o taller da OSHWDem
    [bats.kicad_pcb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]
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2017-03-22 Engadida a biblioteca KiCAD de BricoLabs coma submodule
    [bats.kicad_pcb, bats.sch]
2017-09-23 Engadidas as novas pisadas "easy soldering" dende a biblioteca KiCAD de BricoLabs Actualizados os submódulos
    [bats.kicad_pcb, bats.sch]
2017-09-24 Cambiadas as posicións dos botóns
    [bats.kicad_pcb]
2017-09-27 Rematadas as ultimas modificacións
    [bats.kicad_pcb]
2017-09-27 Todos os cambios previos a OSHWDem-2017 rematados
    [bats-B.Cu.gbl, bats-B.Cu.gbr, bats-B.Mask.gbr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]
2017-09-27 Revisados adornos dos silks e números de versións
    [bats.kicad_pcb, bats.sch]
2017-09-27 Todo listo para facer pedido OSHWDem-2017
    [bats-B.Cu.gbl, bats-B.Cu.gbr, bats-B.Mask.gbr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]
